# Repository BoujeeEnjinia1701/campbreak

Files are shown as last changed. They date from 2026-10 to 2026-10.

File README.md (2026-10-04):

# CampBreak

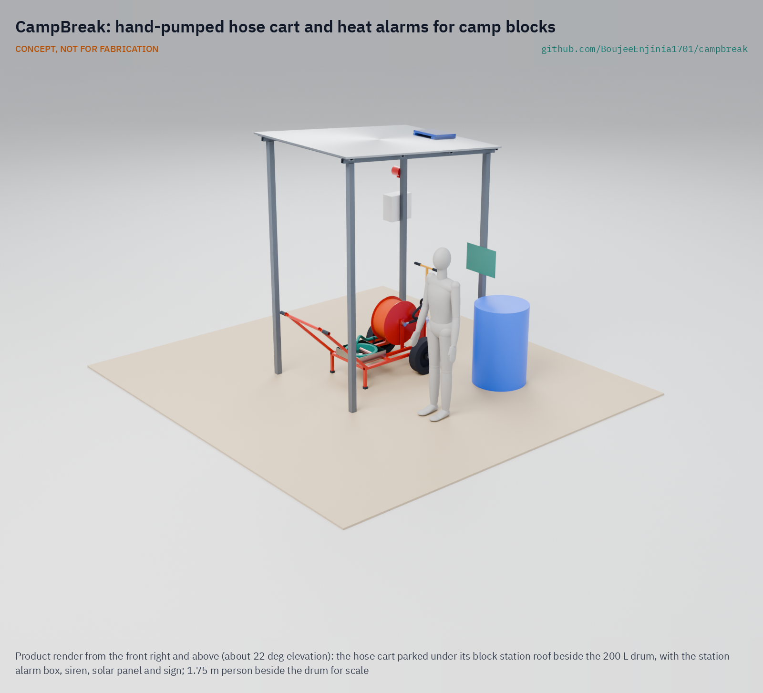
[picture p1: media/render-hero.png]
CampBreak hose cart parked in its block station beside the water drum


     

**Area:** Situational field hardware · **TRL:** 3 of 9 (proof of concept on paper; constructable design, plan not yet built) · **Value-engineering target:** USD 1,600 (estimated cost USD 1,374) · **Difficulty:** 2 of 5

Gives camp residents block alarms and a hand-pumped hose cart to fight shelter fires in the first minutes.

## Concept rationale

Most of the damage in a camp fire is decided in the first few minutes, before any fire service arrives. CampBreak gives each camp block two things for those minutes: rate-of-rise heat alarms in the shelters, so the block knows at once, and a hand-pumped hose cart at a block station, so trained residents can put water on the fire while it is still one shelter. Heat alarms are used because smoke alarms go off from cooking smoke and get switched off.

Keeping the kit open and hand-powered matters because the camps that burn most have little money, patchy power and water that runs short in the dry season. The cart needs no fuel and no mains, and a camp workshop can build and repair it. The alarms make no certification claims; they are an open engineering reference that agencies and camp committees can test and adapt.

## Burning platform

The Rohingya camps in Cox's Bazar, Bangladesh, recorded more than 222 fires between January 2021 and December 2022, 60 of them arson ([Wikipedia, citing BBC, 2023](https://en.wikipedia.org/wiki/2023_Kutupalong_refugee_camp_fire)). A single fire in March 2023 destroyed about 2,000 shelters, 2 health centres and 25 learning centres ([NRC, 2023](https://www.nrc.no/news/2023/march/todays-fire-in-coxs-bazar-must-lead-to-better-living-conditions-in-makeshift-camps)). In January 2024 another fire destroyed about 800 shelters in Camp 5; responders reported that hilly ground kept vehicles out, wind drove the fire through thatch roofs, and dry-season hydrants ran dry ([The New Humanitarian, 2024](https://www.thenewhumanitarian.org/news-feature/2024/01/10/fire-bangladesh-rohingya-refugee-camp-where-is-support)).

The pattern is the same in other dense settlements. In Dhaka, fire services took an average of 68 minutes to reach informal settlements against 28 minutes for formal areas, and residents act as first responders with poor equipment ([Engineering X, Royal Academy of Engineering](https://engineeringx.raeng.org.uk/media/03cd1j4l/engx-a-comparative-study-of-fire-risk-emergence-in-informal-settlements-in-dhaka-and-cape-town-short.pdf)). UNHCR planning standards call for 30 m firebreaks every 300 m and at least 2 m between structures ([UNHCR](https://emergency.unhcr.org/emergency-assistance/shelter-camp-and-settlement/camps/site-planning-camps)), but crowded camps rarely achieve this, so fast local response is often the only barrier left.

## Where it could be used

### By industry

| Industry | Use |
| --- | --- |
| Humanitarian shelter and camp management | Block-level alarm and first-response kit in refugee and displacement camps |
| Urban informal settlements | Community fire stations for dense shack and slum neighbourhoods |
| Disaster risk reduction NGOs | Training and equipment package for community fire volunteer programmes |
| Seasonal and labour camps | Worker camps at construction sites, brick kilns and plantations |
| Rural villages with thatch roofs | Shared hose cart for villages far from a fire station |

### By country or region

| Country or region | Why it matters there |
| --- | --- |
| Bangladesh (Cox's Bazar camps) | More than 222 fires in two years, 60 of them arson, and a 2023 fire that destroyed over 2,000 shelters ([Wikipedia, citing BBC, 2023](https://en.wikipedia.org/wiki/2023_Kutupalong_refugee_camp_fire)). |
| Bangladesh (Dhaka informal settlements) | Fire services averaged 68 minutes to reach informal settlements, against 28 minutes elsewhere ([Engineering X](https://engineeringx.raeng.org.uk/media/03cd1j4l/engx-a-comparative-study-of-fire-risk-emergence-in-informal-settlements-in-dhaka-and-cape-town-short.pdf)). |
| South Africa | Shack fires occur every day, killing and injuring hundreds of people each year ([UNDRR, 2024](https://www.undrr.org/resource/learning-those-who-are-most-risk-informal-settlement-fires-south-africa)). |
| Northwest Syria | A local coordination group counted 126 fires in displacement camps in the first eight months of 2022, with most families cooking inside tents ([Al-Monitor, 2022](https://www.al-monitor.com/originals/2022/08/fires-engulf-displacement-camps-northern-syria-during-heat-wave)). |
| Greece and Europe | The 2020 fires at Moria on Lesbos left about 11,500 asylum seekers without shelter ([UN News, 2020](https://news.un.org/en/story/2020/09/1072132)). |

## What sparked the idea

The idea came from the fire in Camp 11 at Kutupalong, Cox's Bazar, on 5 March 2023. It destroyed more than 2,000 shelters, 35 mosques and 21 learning centres and left about 12,000 people without shelter, although it was brought under control in about three hours ([Wikipedia, citing BBC and The Guardian, 2023](https://en.wikipedia.org/wiki/2023_Kutupalong_refugee_camp_fire)). Three hours is fast for a fire service in a hilly, crowded camp, but far too slow for bamboo and tarpaulin. The damage was done in the first minutes, when the only people present were residents with buckets.

## Problem

Fires in dense camps of bamboo and tarpaulin shelters spread from shelter to shelter within minutes, and fire engines often cannot reach them in time. Residents are the first responders, but they usually have only buckets.

Full problem statement: [docs/01-problem.md](docs/01-problem.md)

## Concept

A camp-block kit of rate-of-rise heat alarms and a hand-pumped hose cart; when an alarm sounds, residents wheel the cart from its block station to the burning shelter and pump water from a drum or tap through the hose to knock the fire down in the first minutes.

Full design precis: [docs/02-concept.md](docs/02-concept.md) · Requirements: [docs/03-requirements.md](docs/03-requirements.md) · Calculations: [docs/04-calcs/01-sizing.md](docs/04-calcs/01-sizing.md) · Prototype build plan: [docs/05-build-plan.md](docs/05-build-plan.md) · Design decisions: [docs/06-design-decisions.md](docs/06-design-decisions.md) · 3D viewer: [media/viewer.html](media/viewer.html)

## Key components

- Rate-of-rise heat alarm, one per shelter, hung under a roof pole
- Block station: four-post shade roof, station alarm box with siren and solar panel, sign and 200 L drum
- Two-wheeled hose cart: welded steel frame, 400 mm puncture-proof wheels
- Semi-rotary hand pump with a two-person T-bar lever and a 4 bar relief valve
- 30 m of 19 mm hose on a reel, stowed full of water behind the shut nozzle, with a jet and spray nozzle
- 4 m suction hose with foot valve strainer, quick couplings and a tap adaptor

Key figures at TRL 3 (estimates): about 20 L/min at the nozzle with two people pumping, a jet reach of about 6.9 m, an alarm relay of 7.2 s, and a 103 kg cart (delivery hose stowed full) that two people pull up a 10 % slope at about 101 N each, 1 N over the 100 N assumed sustainable. A check foot valve keeps the pump primed, the suction hose stays coupled, and volunteers go when two arrive. Water on target within 3 minutes is met on paper for a shelter 100 m away (2.95 min, 3 s to spare), because the delivery hose is stowed full; stations are still sited within 70 m of every shelter (2.5 min).

## Building the prototype

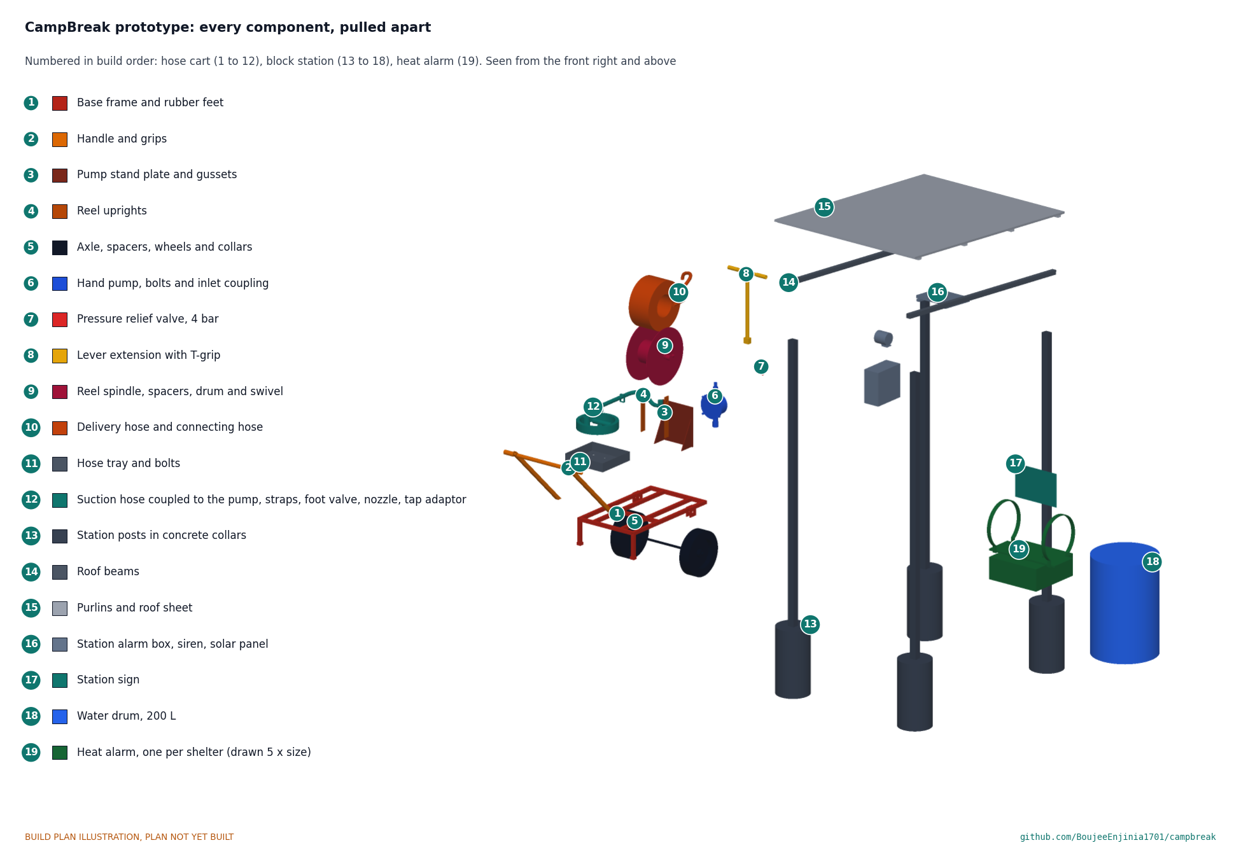
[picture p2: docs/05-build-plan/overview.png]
Every component of the prototype, pulled apart and numbered in build order


The [prototype build plan](docs/05-build-plan.md) shows how to build one block kit, component by component, with a making sketch for every made part, close-ups of the joints and a picture for each of the 21 assembly steps. The cart and station are mild steel tube and plate, cut, drilled and MIG welded, with bought wheels, pump, reel and hoses; the alarm is a drilled stock box on a small aluminium plate. The plan is a plan: nothing has been built or tested yet, and building to it is TRL 4 work. Safety stops before welding, first pumping, loading and wiring are listed in its section 6.

## Safety

> Published as an open engineering reference, not as certified fire alarms or firefighting equipment.
>
> The kit is for small, early fires only. People leave first; nobody enters a burning shelter or stays when the fire spreads.
>
> Never use water on burning cooking oil or on live electrical wiring.
>
> Pressurised hose and pump can injure. The relief valve opens at 4 bar with its discharge pointing down; check hose, clips and fittings before every drill and never point the jet at people.
>
> Heat alarms use alkaline AA cells and the station a sealed lead-acid battery; there are no lithium cells in the kit. Follow the camp's disposal rules.
>
> This design is published as an open engineering reference at TRL 3: a concept, not for fabrication until it is built and tested at TRL 4. It is not certified equipment.

## Repository layout

| Folder | Contents |
| --- | --- |
| `docs/` | Problem, concept, requirements, calculations and design decisions |
| `cad/src/` | build123d Python source, the source of truth for all geometry |
| `cad/step/`, `cad/stl/` | Exported models for FreeCAD, other CAD tools and printing |
| `cad/drawings/` | 2D sketches and dimensioned drawings |
| `bom/` | Bill of materials |
| `electronics/` | KiCad schematics and PCB layouts |
| `firmware/` | Microcontroller code |
| `media/` | Renders, perspectives and photos |
| `build-log/` | Dated prototyping notes |

## Documentation

Controlled documents follow the portfolio [documentation standard](.kit/STANDARDS.md). Each carries a document ID (CBK-PRC-001 for the precis), a version and a revision history. Branded PDFs are built with `python .kit/render.py` and attached to GitHub Releases when a document is tagged, for example `CBK-PRC-001/v1.0`.

## Credits

Designed by Amish Chadha at Design Molecule Labs. See [CONTRIBUTORS.md](CONTRIBUTORS.md) for roles. To cite this design, use [CITATION.cff](CITATION.cff) (GitHub shows it as "Cite this repository").

AI assistance (Claude) was used to accelerate prototype documentation and first-pass research. Design direction and all decisions are Amish Chadha's, recorded in this repository's decision records (`docs/decisions/`).

## Licenses

- **Hardware** (CAD, drawings, BOM, electronics): [CERN-OHL-S v2](LICENSE)
- **Software** (firmware, scripts, notebooks): [MIT](LICENSE-SOFTWARE)

A project of [Design Molecule Labs](https://designmolecule.com).

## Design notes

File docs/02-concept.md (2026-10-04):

---
doc_id: CBK-PRC-001
title: CampBreak design precis
project: CampBreak
doc_type: Precis
version: "0.5"
status: Draft
date: '2026-10-03'
author: Amish Chadha
license: CERN-OHL-S-2.0
revisions:
- version: "0.1"
  date: '2026-09-30'
  author: Amish Chadha
  change: Initial scaffold
- version: "0.2"
  date: '2026-10-03'
  author: Amish Chadha
  change: "Populated to TRL 2 with concept media, components and first-order numbers"
- version: "0.3"
  date: '2026-10-03'
  author: Amish Chadha
  change: "TRL 3 with the decisions of CBK-DDR-001 and CBK-DDR-002 applied and results from CBK-CAL-001"
- version: "0.4"
  date: '2026-10-03'
  author: Amish Chadha
  change: "Amish's R9 decision 1A (CBK-DDR-003): check foot valve, suction hose left coupled, go when two arrive; figures updated"
- version: "0.5"
  date: '2026-10-03'
  author: Amish Chadha
  change: "Amish's round-2 decision 1A (CBK-DDR-004): delivery hose stowed full; cart mass, pull and R9 figures updated"
---

# CampBreak design precis

Gives camp residents block alarms and a hand-pumped hose cart to fight shelter fires in the first minutes.

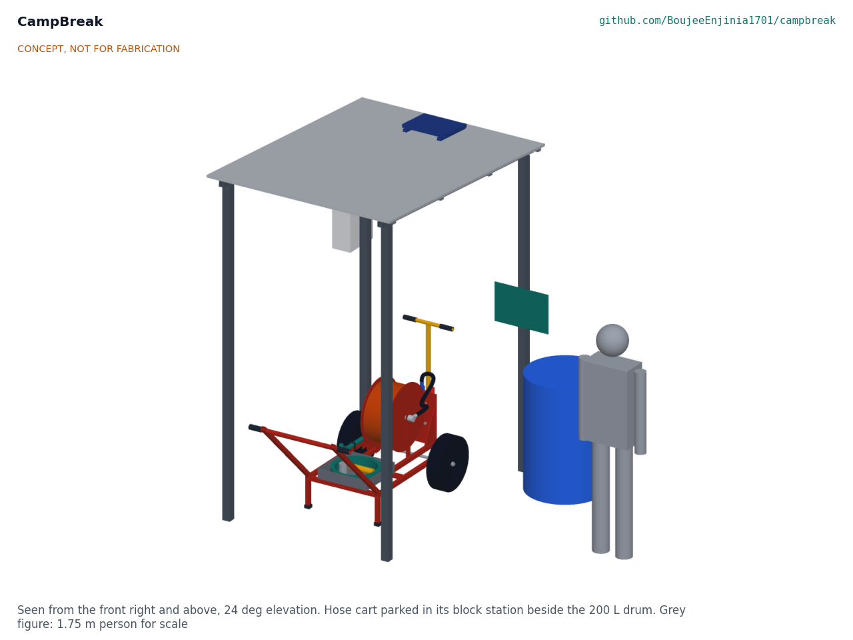
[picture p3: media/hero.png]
Figure 1. Hose cart parked in its block station beside the water drum, with a 1.75 m person for scale


*Figure 1. Concept render of the block station and hose cart, from the TRL 3 model.*

## How it works

Each shelter in a block gets a battery heat alarm hung under a roof pole. When the air at the alarm warms by 8 °C per minute or more, or passes 57 °C, the alarm sounds and radios the block station. The station sounds a 110 dB(A) siren and broadcasts once, so every alarm in the block sounds within about 7 s. Volunteers run to the station, pull out the two-wheeled hose cart and take it to the burning shelter. There they drop the suction hose into a water drum, jerrycan or open container (or connect the tap adaptor to a standpipe), run out the hose from its reel, and two people pump the T-bar lever to drive about 20 L/min through a 6 mm jet that reaches about 7 m. The aim is to keep a fire to one shelter while others clear the neighbours and call the fire service.

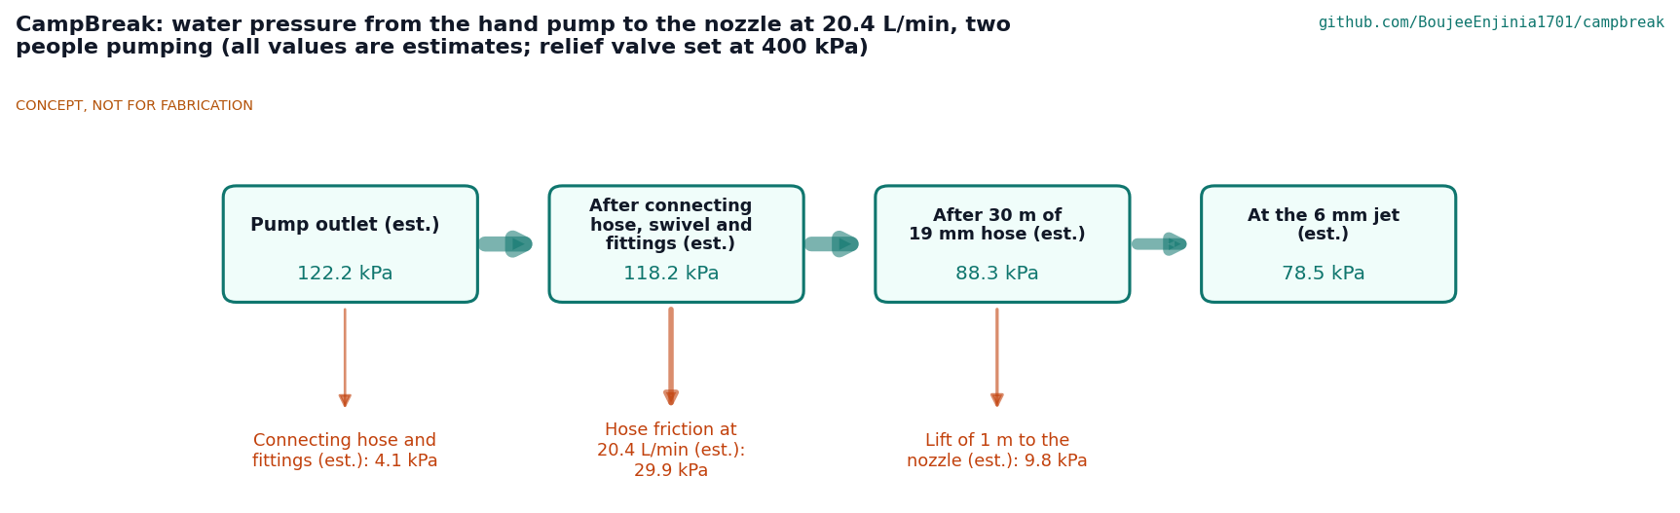
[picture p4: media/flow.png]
Figure 2. Water pressure from the pump to the nozzle (estimates)


*Figure 2. Pressure along the water line at 20.4 L/min with two people pumping; all values are estimates from CBK-CAL-001.*

## Components

*Table 1. Main components (numbers match bom/bom.csv).*

| BOM | Component | What it is |
| --- | --- | --- |
| 1 | Heat alarm (24 per block) | Stock ABS box 100 x 100 x 40 mm with a controller and sub-GHz radio board, a thermistor below the box in a printed guard, a 95 dB(A) piezo and three AA alkaline cells; hung under a roof pole on an aluminium plate and two cable ties |
| 2 | Station alarm box, siren and solar panel | Locked IP65 box with the receiver board, charge controller and 12 V 7 Ah sealed lead-acid battery; 110 dB(A) siren; 10 W panel on the roof |
| 3 | Station frame and roof | Four 60 mm square posts in concrete collars, two beams, four purlins, corrugated sheet; about 1.5 x 2.05 m of shade |
| 4, 5 | Sign and water drum | Instructions in the camp languages; a 200 L drum beside the cart |
| 6 | Cart frame | Welded 30 mm square tube frame with pull handle, pump stand, reel uprights and axle plates |
| 7 | Wheels | Two 400 mm puncture-proof wheels on a 20 mm through axle |
| 8, 9 | Hand pump and lever | Cast-iron double-acting semi-rotary pump, 25 mm ports, with a T-bar lever for two people |
| 10, 11 | Reel and hose | 30 m of 19 mm semi-rigid hose on a reel with a swivel inlet, fed from the pump by a short connecting hose |
| 12 to 15, 20 | Nozzle, suction hose, couplings, tap adaptor, hose straps | Jet and spray nozzle with shut-off; 4 m of 25 mm suction hose with a brass check foot valve, left coupled to the pump inlet and strapped along the left rail so the pump stays primed; cam-lever couplings; a push-on tap adaptor |
| 16 | Hose tray | Folded galvanised tray on the cart that carries the suction hose and small parts |
| 19 | Relief valve | 4 bar spring relief valve at the pump outlet |

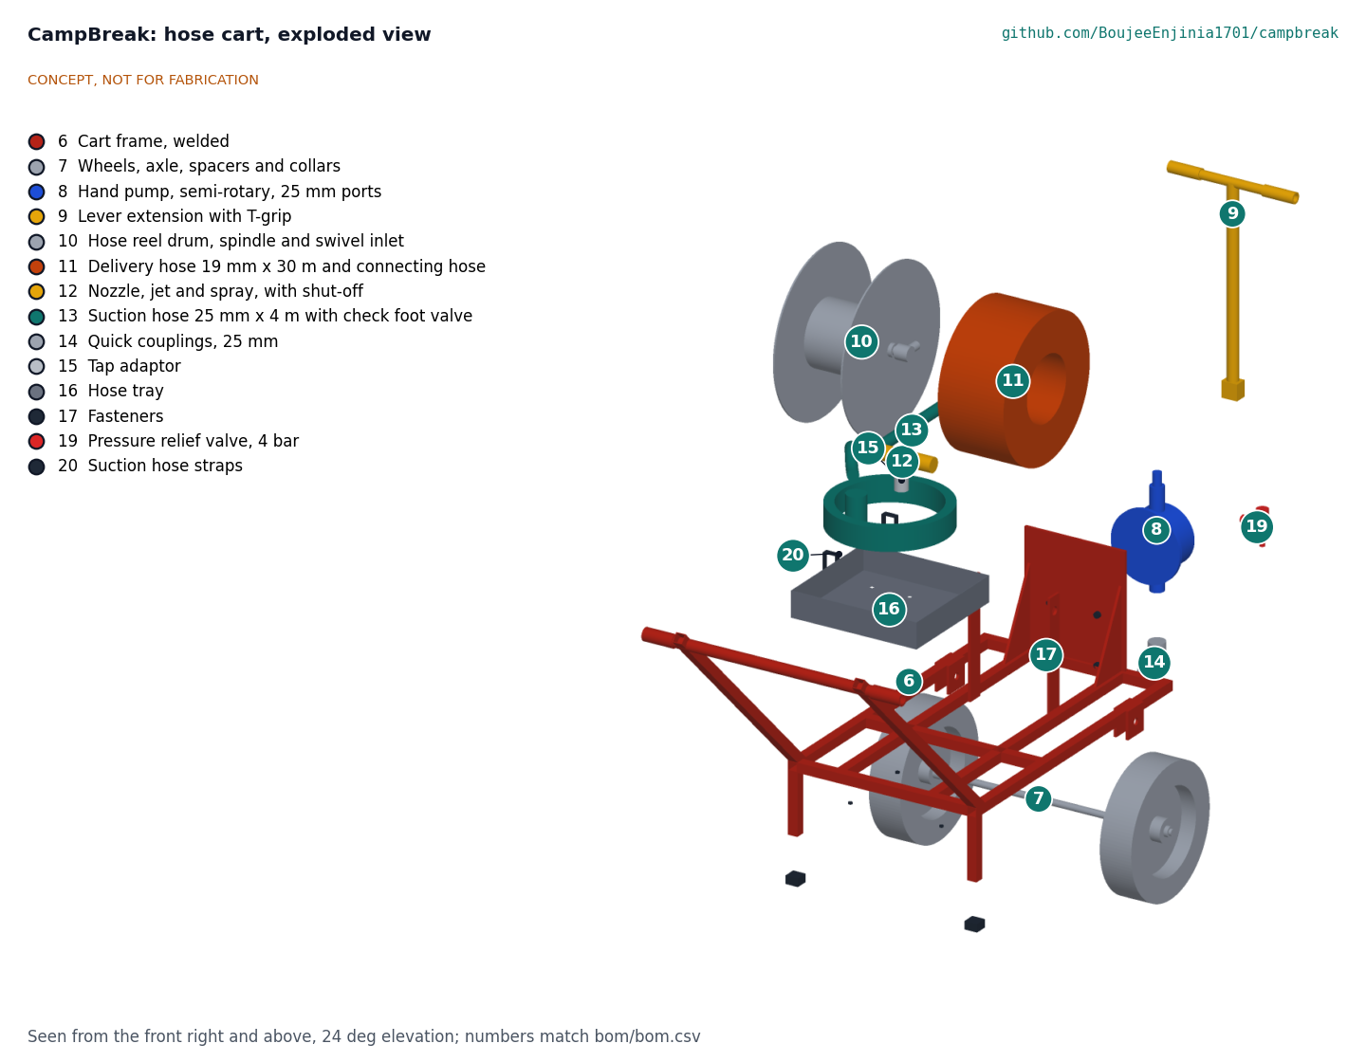
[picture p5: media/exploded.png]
Figure 3. Hose cart pulled apart, numbers matching the BOM


*Figure 3. Exploded view of the hose cart; callouts match bom/bom.csv.*

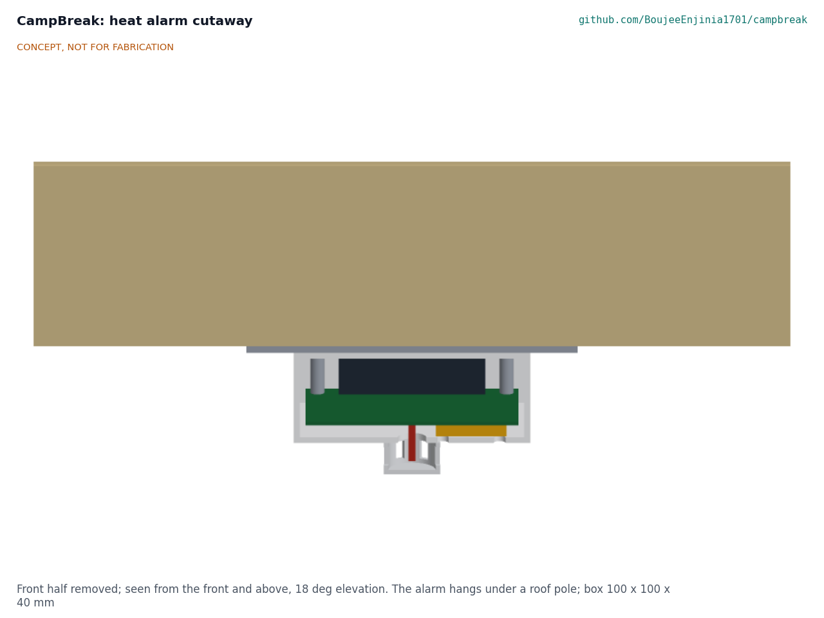
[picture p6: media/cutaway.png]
Figure 4. Heat alarm cut open


*Figure 4. The heat alarm cut open: battery holder, board, sounder and the thermistor below the box.*

## Key design choices

All decided under Amish's 2026-10-03 pre-approval (CBK-DDR-001 and CBK-DDR-002):

1. **Heat, not smoke.** Rate of rise of 8 °C per minute with a 57 °C fixed back-up, because shelters cook with open flames.
2. **Star relay, published in full.** Alarms report to the station, which broadcasts once; no mesh.
3. **A bought pump.** A semi-rotary wing pump is sold in most target markets and is repaired with hand tools.
4. **No lithium cells.** Alkaline cells in the alarms and a sealed lead-acid battery at the station.
5. **Relief valve at 4 bar** so a shut nozzle cannot over-pressure the hose or fittings.
6. **A cart two people can pull,** 850 mm wide, about 103 kg loaded and primed, with the delivery hose full, on 400 mm puncture-proof wheels.
7. **Stations sited within 70 m of every shelter** as the siting margin for the 3 minute target.

Decided by Amish on 2026-10-03 ("1A 2A 3A 4A 5A 6A 7A 8A 9A 10A 11A"; CBK-DDR-003):

8. **A primed pump and a coupled suction hose.** A check foot valve keeps the pump and suction hose full, and the hose stays coupled to the pump, so nothing is coupled or primed at the fire.
9. **Go when two arrive.** The first two volunteers at the station take the cart, within 30 s of the siren; the rule is drilled and printed on the drill card.

## First-order numbers

*Table 2. Key figures (CBK-CAL-001; estimates unless stated).*

| Quantity | Value | Main assumption |
| --- | --- | --- |
| Flow at the nozzle | 20.4 L/min | 0.40 L per double stroke at 60 per minute, 85 % volumetric efficiency |
| Jet reach | 6.9 m | Half the drag-free range of a 12.5 m/s jet at 30° |
| Effort per person | 47 W, about 28 N at the grip | 50 % mechanical efficiency |
| Pump outlet pressure | 1.2 bar | 30 m of 19 mm hose, nozzle 1 m above the pump |
| One 200 L drum | about 10 min | |
| Alarm sound at 3 m | 85.5 dB(A) | 95 dB(A) at 1 m |
| Alarm relay, worst case | 7.2 s | Three retries, station broadcast heard within 4 s |
| Alarm battery life | Cell shelf life (about 5 years) | 6.9 µA average |
| Cart mass, loaded and primed | 103 kg | Catalogue masses for bought parts; 2.6 kg of water in the pump and suction hose and 8.9 kg in the delivery hose |
| Pull on a 10 % slope | 101 N per person | Rolling resistance 0.10; 1 N over the 100 N assumed sustainable |
| Water on target | 2.95 min at 100 m; 2.5 min at 70 m | 1.0 m/s walking, 30 s gather, delivery hose stowed full |
| Block kit cost | USD 1,374 | bom/bom.csv |

Value-engineering target: USD 1,600. Estimated cost of the constructable design: USD 1,374 (USD 226 under the target).

## Patent design-arounds

From the preliminary patent, trademark and prior-art screen (not legal advice):

- Rate-of-rise heat sensing, as the preliminary screen advised; no alarm certification is claimed.
- Lumkani's networked heat detector has no patent identified in the preliminary screen, but its mesh network is described as patented. CampBreak uses a plain star scheme (alarm to station, station broadcast to all), published in full, and is checked again before release.

## Shared blocks

- FieldNode sensor core (power and radio lessons for the alarm and block station)
- CalRig proof-load (pressure and hose proof testing)
- BreakHook (sibling: opening firebreaks in dense settlements)

## Safety

> **Safety:** The kit is for small, early fires only. People leave first; nobody enters a burning shelter or stays when the fire spreads, and the fire service is called at once. Never use water on burning cooking oil or on live electrical wiring.

> **Safety:** The pump, hose and nozzle are pressurised. The relief valve opens at 4 bar and points its discharge at the ground; the hose is rated at 10 bar. Check the hose, clips and couplings before every drill, never point the jet at people, and shut the nozzle only while someone is still at the pump.

> **Safety:** The station battery is sealed lead-acid: fuse it at the terminal, keep it in the locked box, and recycle it through a battery dealer. The alarms use alkaline AA cells; follow the camp's disposal rules. There are no lithium cells in the kit.

> **Safety:** The loaded cart weighs about 103 kg, with the delivery hose full. Two people pull it; on slopes steeper than 10 % a third person holds it back. Park it on its feet with the handle down.

This design is published as an open engineering reference by Design Molecule Labs. It is not certified equipment.

## Open questions

None at design level. Items that can only be settled with real parts are listed in the design decisions register (`docs/06-design-decisions.md`).

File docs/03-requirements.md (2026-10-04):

---
doc_id: CBK-REQ-001
title: CampBreak requirements
project: CampBreak
doc_type: Requirements
version: "0.5"
status: Draft
date: '2026-10-03'
author: Amish Chadha
license: CERN-OHL-S-2.0
revisions:
- version: "0.1"
  date: '2026-09-30'
  author: Amish Chadha
  change: Initial scaffold
- version: "0.2"
  date: '2026-10-03'
  author: Amish Chadha
  change: "Populated to TRL 2 with concept media, components and first-order numbers"
- version: "0.3"
  date: '2026-10-03'
  author: Amish Chadha
  change: "TRL 3 with the decisions of CBK-DDR-001 and CBK-DDR-002 applied and results from CBK-CAL-001"
- version: "0.4"
  date: '2026-10-03'
  author: Amish Chadha
  change: "R9 result after Amish's decision 1A (CBK-DDR-003): check foot valve, suction hose left coupled, go-when-two-arrive rule; delivery hose fill time added. R6 and R11 results updated. Requirement wording unchanged"
- version: "0.5"
  date: '2026-10-03'
  author: Amish Chadha
  change: "Amish's round-2 decision 1A (CBK-DDR-004): delivery hose stowed full; R9 now met on paper at 100 m; R6 pull per person 101 N. Requirement wording unchanged"
---

# CampBreak requirements

Measurable requirements for one block kit, with the TRL 3 result from the calculation note CBK-CAL-001. Ten are met on paper or by design and R2 can only be shown in a cooking trial at TRL 4. **R9 is now met on paper** for a shelter 100 m from the station, with 3 s to spare.

*Table 1. Requirements and TRL 3 status.*

| ID | Requirement | Target | Verification (TRL 4 or later) | TRL 3 result | Status |
| --- | --- | --- | --- | --- | --- |
| R1 | Alarm detects a fast temperature rise | Alarms at a rise of 8 °C (14 °F) per minute or faster, plus a 57 °C fixed threshold | Heat chamber test with logged temperature ramp | Threshold set in firmware, averaged over 60 s | Met by design |
| R2 | Alarm ignores normal cooking | No alarm during 1 hour of stove cooking at 1 m distance | Cooking trial in a mock shelter | Not calculable on paper | To show at TRL 4 |
| R3 | Alarm is loud enough to wake the block | At least 85 dB(A) at 3 m | Sound level meter test | 85.5 dB(A) | Met (est.) |
| R4 | Alarm reaches neighbours and the block station | Every alarm in the block and the station within 10 s | Field test across a mock block layout | 7.2 s worst case | Met (est.) |
| R5 | Alarm runs without mains power | At least 12 months on batteries | Current draw measurement | Limited by cell shelf life, about 5 years | Met (est.) |
| R6 | Cart can be moved on camp paths | Two adults move the loaded cart 100 m on an unpaved 10 % slope in 3 minutes or less; cart width 0.9 m or less | Timed trial on a test track | 1.7 min; 101 N per person (1 N over the 100 N assumed sustainable); 850 mm wide | Met (est.) |
| R7 | Hand pump delivers useful flow | At least 20 L/min (5.3 US gal/min) at the nozzle, pumped by two people for 10 minutes | Bench flow test with timed volume | 20.4 L/min at 47 W per person | Met (est.) |
| R8 | Jet reaches a burning shelter from a safe distance | Jet reach of 6 m (20 ft) or more | Measured throw test | 6.9 m | Met (est.) |
| R9 | Fast deployment | Water on target within 3 minutes of alarm for a shelter 100 m from the station | Timed drill with volunteers, from the siren, using the go-when-two-arrive rule | 2.95 min (177 s) at 100 m; 2.5 min at 70 m | Met (est.), 3 s to spare at 100 m |
| R10 | Repairable locally | All wear parts replaceable with hand tools and parts sold in local markets | Maintenance walkthrough with a camp workshop | Every wear part is a market item | Met by design |
| R11 | Cost against the value-engineering target | Value-engineering target: USD 1,600 for one block kit | Costed bill of materials | USD 1,374, USD 226 under the target | Met |

R9 stays at 3 minutes and 100 m. On 2026-10-03 Amish chose option A on R9 ("1A 2A 3A 4A 5A 6A 7A 8A 9A 10A 11A"; CBK-DDR-003): a check foot valve so the pump stays primed, the suction hose left coupled to the pump with a cam-lever coupling, and the drilled rule "go when two arrive" with a 30 s gather. That brought the 100 m time from 3.8 min to 3.2 min. The rest of the gap was the 26 s needed to fill the empty 30 m delivery hose. In round 2 Amish agreed to stow that hose full of water (CBK-DDR-004): "i agree with all the 46 recommendations you provided. please proceed." The 100 m time is now 2.95 min. This is met on paper by only 3 s, on estimated inputs, and the delivery hose adds 8.9 kg to the cart: the pull is about 101 N per person on a 10 % slope, just over the 100 N assumed sustainable. The R6 time of 1.7 min is still met. The siting rule of CBK-DDR-001 (D9), no shelter more than 70 m along the path from a station, is kept as the siting margin; there the time is 2.5 min.

## Assumptions

- A block has a drum or tap within reach of most shelters, or drums are placed at stations.
- Camp management allows alarms in shelters and a station in each block.
- Volunteers are trained and drill regularly, so the first two reach the station within 30 s of the siren.
- The foot valve's check holds the pump and suction hose full between uses, and the nozzle shut-off holds the delivery hose full; the weekly check on the drill card confirms both.
- The estimates marked (est.) in CBK-CAL-001 hold within the margins shown; the pump displacement is the most important one.

## Safety

> **Safety:** These requirements describe a pressurised hand-pumped water system and battery-powered alarms. The kit is for small, early fires only, people leave first, and water is never used on burning oil or live wiring. It is an open engineering reference, not certified equipment.

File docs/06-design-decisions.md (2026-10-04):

---
doc_id: CBK-DEC-001
title: CampBreak design decisions register
project: CampBreak
doc_type: Design decisions register
version: "0.3"
status: Draft
date: '2026-10-03'
author: Amish Chadha
license: CERN-OHL-S-2.0
revisions:
- version: "0.1"
  date: '2026-10-03'
  author: Amish Chadha
  change: Register opened at TRL 3; all decisions made under Amish's 2026-10-03 pre-approval
- version: "0.2"
  date: '2026-10-03'
  author: Amish Chadha
  change: "Amish's R9 decision 1A recorded (CBK-DDR-003); one new open decision: stow the delivery hose full"
- version: "0.3"
  date: '2026-10-03'
  author: Amish Chadha
  change: "Open decision 1 decided (round 2, 1A) and recorded as CBK-DDR-004; no open decisions; weekly hose check added to items to confirm"
---

# CampBreak design decisions register

Every design decision still to be made, and every decision made, in one place. Each decision is argued in full in its decision record under `docs/decisions/`; this register is the index Amish works from. The build plan (`docs/05-build-plan.md`) describes the design as it stands and does not list decisions.

## Open decisions

None. Open decision 1 (stow the delivery hose full) was decided by Amish on 2026-10-03; see Decisions made and CBK-DDR-004.

## To confirm when parts are bought

| # | What to confirm | Why it matters | Source |
| --- | --- | --- | --- |
| 1 | The hand pump displaces at least 0.40 L per double stroke | R7 is met with only 2 % margin on flow; a smaller pump misses it | CBK-CAL-001, section A |
| 2 | The pump's flange hole pattern (150 mm square assumed), shaft height and handle socket | They set the stand plate holes and the lever hub bore | CBK-DDR-002, P5 and P6 |
| 3 | The reel drum's bore suits a 25 mm spindle, and the swivel inlet's thread suits the 19 mm hose tail | Sets the spindle size or a sleeve | CBK-DDR-002, P7 |
| 4 | The delivery hose's outside diameter is 28 mm or less | The 30 m hose fills the drum with only 8 % spare room | CBK-CAL-001, section G |
| 5 | The nozzle's jet orifice is 6 mm | Sets the flow, pressure and reach together | CBK-CAL-001, section A |
| 6 | The piezo sounder gives at least 95 dB(A) at 1 m | R3 is met with 0.5 dB margin | CBK-CAL-001, section B |
| 7 | The wheels have 20 mm bores and 75 mm hubs | Sets the axle, spacer and collar lengths | CBK-DDR-002, P2 |
| 8 | The relief valve opens at 4 bar ± 0.5 bar | Pressure limit for the hose and fittings | CBK-DDR-001, D7 |
| 9 | The foot valve's check holds the suction hose and pump full for a week, and the suction hose bends to 60 mm radius or less | The pump stays primed (R9); the stowed hose path has a 63 mm bend | CBK-DDR-003 |
| 10 | The nozzle shut-off and the pump hold the full delivery hose for a week with no drip; the pull per person on a 10 % slope (about 101 N expected) is acceptable | R9 has only 3 s of margin and relies on the hose staying full; the pull is 1 N over the 100 N assumed sustainable | CBK-DDR-004 |

## Value engineering

Value-engineering target: USD 1,600 (a hypothetical control target, not a limit). Estimated cost of the constructable design: USD 1,374 (USD 226 under the target). Main cost drivers and savings worth trying:

- The 24 heat alarms are the largest share (USD 420, USD 17.50 each). The board price is a prototype module estimate; a single board with the radio, controller and sounder driver, made in a batch, should fall to about USD 10 to 12 each at TRL 4.
- The station costs USD 317: steel frame and roof USD 157, alarm box with battery, siren and panel USD 105. Where a block already has a shaded structure, the station can be built against it and the frame dropped.
- The cart costs USD 637: pump USD 120, reel drum USD 95, hoses USD 83, wheels USD 69, frame USD 59, suction hose with the brass check foot valve USD 40. A reel welded from tube and sheet in the camp workshop could save about USD 50; a second-hand pump is worth trying if its displacement is checked.

## Decisions made

| Date | Decision | Decided by | Record |
| --- | --- | --- | --- |
| 2026-10-03 | Alarm relay: published star scheme on a sub-GHz band (alarm to station, one station broadcast to all alarms); no mesh; checked against Lumkani's patents before release | Amish, pre-approval: "I pre-approve the batch runs along with any recommendations you come up with." | CBK-DDR-001, D1 |
| 2026-10-03 | Detection: rate of rise of 8 °C per minute over 60 s plus a 57 °C fixed back-up, thermistor below the box | Amish, same pre-approval | CBK-DDR-001, D2 |
| 2026-10-03 | Alarm board specified by function and priced as a module; board design and firmware left to TRL 4 | Amish, same pre-approval | CBK-DDR-001, D3 |
| 2026-10-03 | Block kit of 24 alarms, one station and one cart | Amish, same pre-approval | CBK-DDR-001, D4 |
| 2026-10-03 | Bought cast-iron semi-rotary pump, 25 mm ports, at least 0.40 L per double stroke | Amish, same pre-approval | CBK-DDR-001, D5 |
| 2026-10-03 | No lithium cells: sealed lead-acid at the station, alkaline AA cells in the alarms (conservative; lithium iron phosphate only with evidence of safe charging at 45 °C and a recycling route) | Amish, same pre-approval | CBK-DDR-001, D6 |
| 2026-10-03 | 4 bar relief valve at the pump outlet, discharge down, hose rated 10 bar (conservative; raised only after a burst test of the bought hose and fittings) | Amish, same pre-approval | CBK-DDR-001, D7 |
| 2026-10-03 | 19 mm semi-rigid hose, 30 m on a reel, with a 6 mm jet and spray nozzle | Amish, same pre-approval | CBK-DDR-001, D8 |
| 2026-10-03 | R9 kept at 3 min; stations sited within 70 m of every shelter with a drilled 30 s muster; R9 reported as not met on paper at 100 m | Amish, same pre-approval | CBK-DDR-001, D9 |
| 2026-10-03 | First partner to approach: a camp management agency in the Cox's Bazar camps, Bangladesh, with the Bangladesh Fire Service and Civil Defence (first candidate, not agreed) | Amish, same pre-approval | CBK-DDR-001, D10 |
| 2026-10-03 | Design for construction: welded tube frame, through axle in axle plates, legs and feet, handle, pump stand, lever extension, reel on uprights, connecting hose and relief tee, four-post station, fixings for the station fittings, hose tray and the alarm's plate and ties (P1 to P12) | Amish, same pre-approval | CBK-DDR-002 |
| 2026-10-03 | `budget_usd` left at USD 1,600 as the value-engineering target; cost variations accepted | Amish: "I also accept any cost overruns or variations from the assumed scope cost." | CBK-DDR-001 |
| 2026-10-03 | R9 (decision 1A): brass check foot valve so the pump stays primed; suction hose left coupled to the pump inlet with a cam-lever coupling and strapped along the left rail; drilled rule "go when two arrive" with a 30 s gather on the drill card, the station sign and in the build plan; 3 min target and "stations within 70 m of every shelter" kept as the siting margin. Result: 3.2 min at 100 m (not met, 11 s over), 2.7 min at 70 m | Amish: "1A 2A 3A 4A 5A 6A 7A 8A 9A 10A 11A" | CBK-DDR-003 |
| 2026-10-03 | R9 (round 2, decision 1A): delivery hose and connecting hose stowed full of water behind the shut nozzle, refilled at the weekly check; no new parts. Result: 2.95 min (177 s) at 100 m, met with 3 s to spare; 2.5 min at 70 m; cart 103.4 kg; 101 N per person on a 10 % slope (1 N over the 100 N assumed sustainable); cost unchanged at USD 1,374 | Amish: "i agree with all the 46 recommendations you provided. please proceed." | CBK-DDR-004 |

## Safety

> **Safety:** CampBreak includes a pressurised hand-pumped water line (relief valve at 4 bar, hose rated 10 bar) and a sealed lead-acid station battery. The kit is for small, early fires only; people leave first, and water is never used on burning oil or live wiring. Safety stops are listed in the build plan, section 6. It is an open engineering reference, not certified equipment.

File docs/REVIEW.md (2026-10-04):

# Review note: CampBreak

## Session 2026-09-30: scaffolded

### What was done

- Repository created from kit 1.6.0 at TRL 1, target TRL 2.
- `docs/01-problem.md` (CBK-PRB-001 v0.1): problem with cited evidence, users, environment, constraints, prior work, open questions.
- `docs/02-concept.md` (CBK-PRC-001 v0.1): how it works, components, patent design-arounds, shared blocks, safety.
- `docs/03-requirements.md` (CBK-REQ-001 v0.1): 11 proposed requirements.
- `README.md` with concept rationale, burning platform, where it could be used, and what sparked the idea.

### Next

- Run `/populate` to bring the repo to a strong TRL 2 with concept media.

## Session 2026-10-03: TRL 2 (populate)

Run under `/to-trl3` with Amish's 2026-10-03 pre-approval: "start with the first 14 repos from the list of 29 projects. I pre-approve the batch runs along with any recommendations you come up with. I also accept any cost overruns or variations from the assumed scope cost."

### What was done

- Kit 1.7.0 installed (`.kit/`, `.claude/commands/`, root `CLAUDE.md` from `.kit/CLAUDE.md`).
- `docs/01-problem.md` (CBK-PRB-001 v0.3): budget worded as a value-engineering target; open questions answered; safety section.
- `docs/02-concept.md` (CBK-PRC-001 v0.3): how it works, components by BOM line, key design choices, first-order numbers, safety.
- `docs/03-requirements.md` (CBK-REQ-001 v0.3): 11 measurable requirements with TRL 3 status.
- Concept media from `cad/src/concept_media.py`: `media/hero.png` (with a 1.75 m figure), `media/concept-blueprint.png` and `.pdf` (CBK-DWG-010), `media/model.glb` and `media/viewer.html`, `media/cutaway.png` (heat alarm), `media/exploded.png` (cart, BOM callouts), `media/flow.png` (pressure along the water line, estimates).
- `bom/bom.csv`: 19 lines, every line priced.

### Results

The concept closes on paper except for response time at 100 m (R9) and the cooking test (R2), which cannot be calculated.

### Decisions made under the pre-approval

TRL 2 review items D1 to D10 (relay scheme, detection rule, board scope, kit size, pump, no lithium, relief valve, hose, R9 siting rule, first partner), recorded in `docs/decisions/0001-trl2-review-decisions.md` (CBK-DDR-001).

## Session 2026-10-03: TRL 3 (advance and build plan)

### What was done

- `cad/src/model.py`: parametric build123d model of the cart, station and heat alarm, made constructable, with 97 constructability checks (all pass). STEP and STL in `cad/step/` and `cad/stl/`.
- `docs/04-calcs/01-sizing.md` (CBK-CAL-001 v0.1) and `docs/04-calcs/sizing.py` with `results.csv`.
- `cad/drawings/CBK-DWG-001` Rev P1: general arrangement of the hose cart (`cad/src/sheets.py`).
- Build plan `docs/05-build-plan.md` (CBK-BLD-001 v0.1) with pictures from `cad/src/build_plan_media.py`: overview, 12 making sketches (CBK-DWG-101 to 112), 11 joint close-ups and 21 assembly steps.
- Design decisions register `docs/06-design-decisions.md` (CBK-DEC-001 v0.1) and decision record `docs/decisions/0002-design-for-construction.md` (CBK-DDR-002).
- Appearance model `cad/src/product_model.py` (hero, exploded and detail views; mannequin and forearm for scale). Scenes exported to `/home/claude/renders/campbreak` for the photoreal render on Amish's Mac. `media/render-hero.png` does not exist yet; the README already leads with it.
- `project.yaml`: trl 3, trl_target 3, `design_state: constructable`, evidence listed. `budget_usd` unchanged at 1,600.

### Results

- Flow 20.4 L/min at 47 W per person; jet reach 6.9 m; pump outlet 1.2 bar.
- Alarm 85.5 dB(A) at 3 m; relay 7.2 s worst case; battery life limited by cell shelf life.
- Cart 850 mm wide, about 91 kg loaded; 89 N per person on a 10 % slope; 1.7 min for 100 m.
- Station roof resists a 30 m/s gust uplift with a factor of about 2 on collar weight.
- Value-engineering target: USD 1,600. Estimated cost of the constructable design: USD 1,355 (USD 245 under the target).

### Requirements not met

- **R9 (water on target within 3 min at 100 m): not met on paper**, 3.8 min. With the decided siting rule (no shelter more than 70 m from a station, 30 s muster) the time is 2.8 min.
- R2 (no false alarm while cooking) cannot be shown on paper; it needs a cooking trial at TRL 4.
- Thin margins: R7 flow (2 %), R3 sound (0.5 dB), reel capacity (8 %).

### Decisions made under the pre-approval

- CBK-DDR-001, D1 to D10 (above).
- CBK-DDR-002, P1 to P12: the design-for-construction changes listed below.
- Open decisions: none. Items to confirm when parts are bought are in CBK-DEC-001 (pump displacement and flange, reel bore, hose diameter, jet orifice, sounder level, wheel hubs, relief setting).

### Build plan findings: design changes made for construction (2026-10-03)

1. Cart frame made a welded ladder frame of 30 mm square tube with bearers (P1).
2. Through axle in four 8 mm axle plates with spacers, collars and R-clips (P2).
3. Front legs with rubber feet so the cart parks level (P3).
4. Handle arms sitting on the rail tops, coped to the cross bar (P4).
5. Pump stand plate with gussets; pump bolted with four M12 bolts (P5).
6. Clamp-on lever extension with a T-bar for two people (P6).
7. Reel drum on a spindle in two welded uprights with a swivel inlet (P7).
8. Connecting hose from pump to reel, relief valve on a tee pointing down (P8).
9. Station on four posts in concrete collars instead of a two-post cantilever (P9).
10. Bought fixings for the station box, siren, panel and sign (P10).
11. Folded hose tray bolted to the bearers (P11).
12. Heat alarm on an aluminium plate hung by two ties under a roof pole; thermistor in a printed guard (P12).

### Appearance model

`cad/src/product_model.py` uses the model components unchanged; it only adds context (ground, a 1.75 m mannequin beside the drum, a forearm and hand beside the alarm) and leaves out the buried post ends and collars. No appearance deviations from `model.py`.

### Safety concerns

- Pressurised water line: relief valve at 4 bar fitted before first pumping, hose rated 10 bar, safety stops in build plan section 6.
- Sealed lead-acid station battery: fused at the terminal, connected last, locked box.
- A 91 kg cart on slopes: two people pulling, a third holding back on steeper slopes.
- Use limits: small, early fires only; people leave first; never water on oil or live wiring; drills only with the fire service or camp fire safety focal point present.
- No certification is claimed for the alarms or the firefighting equipment.

### Recommended next step

Photoreal renders and storefront images on Amish's Mac (`/render-product`). TRL 4 (build and test to CBK-BLD-001, starting with the pump flow and relief check and the cooking trial) needs a new instruction from Amish.

## 2026-10-03: photoreal renders

Rendered with Blender Cycles on Amish's Mac from `cad/src/product_model.py`; captioned with `.kit/photo_caption.py`; `media/card.png` and `media/social-preview.png` made with `.kit/cards.py`. Views: hero, exploded, detail. image_qc passes and `render.py --check` has no FAIL.

## 2026-10-03: Amish's requirement decisions carried out

Amish, 2026-10-03: "1A 2A 3A 4A 5A 6A 7A 8A 9A 10A 11A". For CampBreak this is decision 1A on R9 (water on target within 3 min at 100 m), recorded in `docs/decisions/0003-r9-response-time.md` (CBK-DDR-003) and in the register `docs/06-design-decisions.md` (CBK-DEC-001 v0.2).

### Changes made, with the new result for each

| Change | Files | New result |
| --- | --- | --- |
| Brass spring-loaded foot valve with a positive-seal check, so the pump and suction hose stay primed | `cad/src/model.py`, `bom/bom.csv` line 13 (USD 40, was 28) | No priming at the fire; suction loss factor raised to 7.0 (est.); R7 flow unchanged at 20.4 L/min, 47 W per person |
| Suction hose left coupled to the pump inlet by its cam-lever adaptor with a 90° elbow tail, run along the top of the left rail under two rubber straps and onto its coil in the tray | `cad/src/model.py` (new parts `suction_adaptor`, `suction_run`, `hose_straps`; 18 new checks, 115 of 115 pass), STEP and STL, `bom/bom.csv` lines 14 and 20 (new, USD 5) | Clears the wheels by 20 mm, the ground by 173 mm and the swung lever by 166 mm; tightest hose bend 63 mm radius |
| "Go when two arrive" with a 30 s gather on a laminated drill card, the station sign and in the build plan | `docs/05-build-plan.md` section 5a (drill card), Step 12, first checks; sign sketch CBK-DWG-111; `bom/bom.csv` line 18 (USD 27, was 25) | Gather 30 s instead of the 60 s muster |
| R9 recomputed (CBK-CAL-001 v0.2, section E), now with the 26 s to fill the empty 30 m delivery hose, which v0.1 left out | `docs/04-calcs/sizing.py`, `01-sizing.md`, `results.csv`; `docs/03-requirements.md` v0.4 (wording unchanged, result updated) | **R9 at 100 m: 191 s (3.2 min) against 180 s, still not met on paper, 11 s over** (3.8 min before; 4.2 min like for like with the fill counted). At 70 m, the siting margin kept: 161 s (2.7 min), met |
| Cart mass and pull | `sizing.py`, `01-sizing.md` | 94.6 kg stowed primed (was 91.4), including 2.6 kg of water; 92 N per person on a 10 % slope; R6 still met (1.7 min) |
| Cost | `bom/bom.csv` | Value-engineering target: USD 1,600. Estimated cost of the constructable design: USD 1,374 (USD 226 under the target). `budget_usd` unchanged |

Pictures changed: general arrangement CBK-DWG-001 (Rev P2), concept sheet CBK-DWG-010 (Rev P2), `media/hero.png`, `media/exploded.png`, `media/model.glb`, build plan overview, sign sketch CBK-DWG-111, new joint 12 (Figure 17; later figures renumbered), Step 6 to Step 17. Documents also updated: `docs/02-concept.md` v0.4, `docs/01-problem.md` v0.4 (cost), `README.md`, `project.yaml` (evidence), `cad/src/product_model.py` (materials for the new parts; scenes re-exported to `/home/claude/renders/campbreak`). `Compound(children=...)` replaced by `Compound([...])` in the scripts.

### Decision proposed, awaiting Amish

Stow the 30 m delivery hose full of water as well (CBK-DEC-001, open decision 1). Options: (a) leave as is, R9 not met at 100 m by 11 s, the 70 m margin holds; (b) stow the hose full behind the shut nozzle: 177 s (2.95 min) at 100 m, met with 3 s to spare, 8.9 kg more on the cart (about 101 N per person on a 10 % slope, just over the 100 N assumed sustainable), no new parts; (c) restate R9 to 3.25 min. Recommendation: (b).

### Safety

- The first pumper works alone for a minute or two until others arrive, at about 95 W, above the 75 W assumed sustainable for 10 min (est.); the drill checks it.
- "Go when two arrive" never means one person with the cart or running with it; people leave the shelter first. Both are on the drill card.
- The foot valve's seal is now a working part; the weekly prime check on the drill card finds a leak.

### Recommended next step

Amish decides open decision 1. TRL 4 (build and test to CBK-BLD-001, including the week-long prime hold and the timed drill at 70 m and 100 m) needs a new instruction from Amish.

## 2026-10-03: photoreal renders redone after Amish's requirement decisions

Rendered with Blender Cycles on Amish's Mac from `cad/src/product_model.py`; captioned with `.kit/photo_caption.py`; `media/card.png` and `media/social-preview.png` made with `.kit/cards.py`. Views: hero, exploded, detail. image_qc passes and `render.py --check` has no FAIL.

## 2026-10-03: Amish's round-2 requirement decisions carried out

Amish, 2026-10-03: "i agree with all the 46 recommendations you provided. please proceed." For CampBreak this is decision 1A: stow the delivery hose full of water on the cart, recompute R9 at 100 m and the pull per person. Recorded in `docs/decisions/0004-delivery-hose-stowed-full.md` (CBK-DDR-004) and in the register `docs/06-design-decisions.md` (CBK-DEC-001 v0.3).

### Changes made, with the new result for each

| Change | Files | New result |
| --- | --- | --- |
| Delivery hose (8.5 L) and connecting hose (0.3 L) stowed full of water behind the shut nozzle; no new parts and no geometry change | `docs/04-calcs/sizing.py` (water in the hoses added to the cart mass and centre of mass), `docs/04-calcs/01-sizing.md` v0.3, `results.csv`, `bom/bom.csv` line 11 note | Cart 103.4 kg stowed (was 94.6 kg), 8.9 kg more |
| R9 recomputed (CBK-CAL-001 v0.3, section E): no fill time at the fire | `01-sizing.md`, `results.csv`, `docs/03-requirements.md` v0.5 (wording unchanged) | **R9 at 100 m: 2.95 min (177 s) against 3 min, met on paper with 3 s to spare** (191 s before). At 70 m, the siting margin: 2.5 min (147 s). The 25 s to run out the hose and aim now sets the pace |
| Pull per person recomputed | `01-sizing.md` section D | **101 N per person on a 10 % slope (was 92 N), 1 N over the 100 N assumed sustainable.** R6 time (1.7 min) and width (850 mm) are still met; the pull is at the edge of the assumption and the TRL 4 pulling trial measures it |
| Build plan and drill card | `docs/05-build-plan.md` v0.3: Step 12 now fills the delivery hose; new first check "Hose stays full"; weekly check on the drill card also checks the hose is full; weight in the safety note | Text only; build plan pictures unchanged because the model is unchanged |
| Cost | `bom/bom.csv` | Value-engineering target: USD 1,600. Estimated cost of the constructable design: USD 1,374 (USD 226 under the target). `budget_usd` unchanged |
| Documents restated | `docs/02-concept.md` v0.5, `README.md` | Mass, pull and R9 figures updated |

Pictures changed: general arrangement CBK-DWG-001 (Rev P3) and concept sheet CBK-DWG-010 (Rev P3), whose notes and key figures changed. The model, STEP, STL, hero, exploded view and build plan pictures are unchanged (no geometry change). The appearance model needed no change, so the photoreal renders stand and the existing views were re-exported without a change.

### Decisions proposed, awaiting Amish

None. Open decision 1 is closed.

### Safety

- The cart now weighs about 103 kg. Two people always move it, a third holds it back on slopes steeper than 10 %, and nobody runs with it.
- The pull of 101 N per person is 1 N over the 100 N assumed sustainable; the margin on R9 is only 3 s. Both are honest thin points, to be measured at TRL 4.
- A full delivery hose is kept shut at the nozzle; the 4 bar relief valve protects it if the sun heats it.

### Recommended next step

TRL 4 (build and test to CBK-BLD-001, including the week-long hose-full hold, the pulling trial with the effort per person, and the timed drill at 70 m and 100 m) needs a new instruction from Amish.

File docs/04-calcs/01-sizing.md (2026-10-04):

---
doc_id: CBK-CAL-001
title: CampBreak sizing calculations
project: CampBreak
doc_type: Calculation note
version: "0.3"
status: Draft
date: '2026-10-03'
author: Amish Chadha
license: CERN-OHL-S-2.0
revisions:
- version: "0.1"
  date: '2026-10-03'
  author: Amish Chadha
  change: First calculation note at TRL 3, on the constructable design (CBK-DDR-002)
- version: "0.2"
  date: '2026-10-03'
  author: Amish Chadha
  change: "Amish's R9 decision (CBK-DDR-003): check foot valve, suction hose left coupled, go-when-two-arrive rule; R9 timeline recomputed with the delivery hose fill time added; cart mass and cost updated"
- version: "0.3"
  date: '2026-10-03'
  author: Amish Chadha
  change: "Amish's round-2 decision 1A (CBK-DDR-004): delivery hose stowed full of water; R9 recomputed at 100 m and 70 m; cart mass and pull per person recomputed"
---

# CampBreak sizing calculations

On paper the kit meets ten of its eleven requirements. The hand pump gives about 20.4 L/min with two people pumping at a sustainable 47 W each, the 6 mm jet reaches about 6.9 m, the alarms are loud enough and fast enough, and two people pull the loaded cart up a 10 % slope with about 101 N each, 1 N over the 100 N assumed sustainable. R2 (no false alarm while cooking) cannot be calculated and needs a cooking trial at TRL 4. R9 (water on target within 3 min for a shelter 100 m away) is now **met on paper**, at 2.95 min (177 s, 3 s to spare). Amish's R9 decisions of 2026-10-03 (CBK-DDR-003: check foot valve, suction hose left coupled to the pump, "go when two arrive" with a 30 s gather; CBK-DDR-004: delivery hose stowed full of water) bring the time from 3.8 min as first published to 2.95 min. A shelter at most 70 m from a station, the siting margin kept from CBK-DDR-001 (D9), gets water in 2.5 min. The kit costs about USD 1,374 against a value-engineering target of USD 1,600.

Every figure comes from `docs/04-calcs/sizing.py`, which reads its geometry from `cad/src/model.py` and its prices from `bom/bom.csv`, and writes `docs/04-calcs/results.csv`. Inputs marked (est.) are estimates to be confirmed by measurement at TRL 4.

> **Safety:** The pump and hose are a pressurised water system. A shut nozzle with two people pumping could reach several bar; the 4 bar relief valve (CBK-DDR-001, D7) caps it, and the hose is rated at 10 bar. The station battery is sealed lead-acid: it can deliver high short-circuit current and vents hydrogen if overcharged. The kit is for small, early fires only; people leave first, and water is never used on burning oil or live wiring.

## A. Pump, hose and nozzle (R7, R8)

### Assumptions

*Table 1. Inputs for the water line.*

| Input | Value | Note |
| --- | --- | --- |
| Pump displacement | 0.40 L per double stroke | (est.) to confirm on the pump bought |
| Pumping rate | 60 double strokes per minute | (est.) steady pace for two people |
| Volumetric efficiency | 0.85 | (est.) cast semi-rotary pump |
| Mechanical efficiency | 0.50 | (est.) lever, vanes and seals |
| Jet | 6 mm, discharge coefficient 0.96 | Nozzle orifice to confirm when bought |
| Delivery hose | 19 mm bore, 30 m, roughness 0.01 mm | Plus 1.2 m of 19 mm connecting hose |
| Delivery fittings | Loss factor 4.0 | (est.) swivel, tee and couplings |
| Suction | 25 mm, 4 m, loss factor 7.0, lift 1.5 m | (est.) spring check foot valve, strainer, elbow and coupling (CBK-DDR-003); worst case from a low open container |
| Nozzle height | 1 m above the pump | Slope or raised arm |
| Reach factor | 0.50 of the drag-free range at 30° | (est.) to measure |
| Sustained effort | 75 W per person for 10 min | (est.) |

### Method

Flow is displacement x rate x volumetric efficiency. Jet speed comes from the flow and the orifice; nozzle pressure is half the density times the jet speed squared. Hose friction uses the Darcy factor from the Swamee-Jain equation. The pump head is the sum of nozzle pressure, friction, fittings, lift to the nozzle and suction losses. Shaft power is hydraulic power over mechanical efficiency; the lever force follows from the work per double stroke over four 40° swings at a 610 mm grip radius.

### Results

*Table 2. Water line at two people pumping.*

| Quantity | Result |
| --- | --- |
| Flow at the nozzle | 20.4 L/min (R7 target 20) |
| Jet speed | 12.5 m/s |
| Pressure at the nozzle | 78 kPa |
| Hose friction, 30 m | 29.9 kPa at 1.2 m/s, Reynolds number about 22,800 |
| Pump outlet pressure | 122 kPa (1.2 bar), well under the 4 bar relief setting |
| Suction side | 17 kPa below atmosphere; 8.3 m of net positive suction head available |
| Hydraulic power | 47 W; shaft power 95 W, or 47 W per person |
| Force at the grip | 56 N in total, about 28 N per person |
| Force to reach the relief setting against a shut nozzle | 94 N in total, so two people can reach it |
| Jet reach | 6.9 m (13.9 m drag-free); R8 target 6 m |
| One 200 L drum | about 9.8 min of pumping |

Effort is well within the 75 W per person that can be kept up for 10 minutes, so R7 is met with margin on effort, though only with 2 % margin on flow. The flow depends directly on the pump's displacement, which must be confirmed on the pump bought (CBK-DEC-001, to confirm).

Figure 1 (`media/flow.png`) shows the pressure falling from the pump to the nozzle; all values are estimates.

## B. Heat alarm (R1 to R5)

*Table 3. Alarm inputs (est. unless stated).*

| Input | Value |
| --- | --- |
| Threshold | 8 °C per minute over 60 s, plus 57 °C fixed (decided, CBK-DDR-001 D2) |
| Sample interval | 10 s; 1 mA for 1 ms per sample |
| Sleep current | 3 µA |
| Radio listen for station broadcast | every 4 s, 10 mA for 1.5 ms |
| Daily check-in | one 60 ms transmission at 40 mA |
| Cells | 3 x AA alkaline, 2.4 Ah derated to 70 %, with a 30 min sounding reserve |
| Sounder | 95 dB(A) at 1 m |
| Alert | 100 ms transmission with three retries 1 s apart |

*Table 4. Alarm results.*

| Requirement | Result | Status |
| --- | --- | --- |
| R1 rate of rise | 8 °C per minute set in firmware; worst-case extra delay one 10 s sample | Met by design |
| R2 cooking | Not calculable on paper | To show at TRL 4 |
| R3 sound at 3 m | 95 - 20 log10(3) = 85.5 dB(A) | Met (est.), 0.5 dB margin |
| R4 relay time | 3.1 s alarm to station (with retries) plus 4.1 s for the station broadcast to reach every alarm: 7.2 s worst case | Met (est.) |
| R5 battery life | Average 6.9 µA; 331 months on paper, so cell shelf life (about 5 years) is the limit | Met (est.) |

R3 has little margin: a sounder of at least 95 dB(A) at 1 m is specified in the BOM, and a louder one is the first fix if the TRL 4 measurement falls short.

## C. Cart mass and balance (R6)

Steel parts are weighed from the model volumes at 7,850 kg/m³; bought parts use catalogue estimates (pump 14 kg, wheels 5.5 kg each, reel drum 9 kg, wound hose 11.4 kg, brass check foot valve 1.0 kg). Since CBK-DDR-003 the cart is stowed primed: the pump body (about 0.6 L, est.) and the 4 m suction hose (2.0 L) hold 2.6 kg of water, counted at the middle of the suction hose run. Since CBK-DDR-004 the 30 m delivery hose (8.5 L) and the 1.2 m connecting hose (0.3 L) are stowed full too: 8.9 kg of water, counted at the wound hose and the connecting hose.

*Table 5. Cart mass and balance.*

| Quantity | Result |
| --- | --- |
| Loaded cart mass, stowed primed with the delivery hose full | 103.4 kg (est.), of which 2.6 kg is water in the pump and suction hose and 8.9 kg is water in the delivery and connecting hoses (94.6 kg before CBK-DDR-004) |
| Centre of mass | 5 mm left of the centre line, 108 mm in front of the axle and 409 mm up |
| Load on the front feet when parked | 139 N |
| Lift at the pull bar to raise the feet | 81 N |
| Tipping sideways | at 42° |
| Overall size | 850 wide x 1,744 long x 1,067 tall |

## D. Pulling effort and speed (R6)

Rolling resistance 0.10 on unpaved ground (est.), slope 10 %, two people. Pull force is the weight times the sine of the slope plus rolling resistance times the cosine: 202 N in all, 101 N each (92 N before the delivery hose was stowed full). That is 1 N over the 100 N per person assumed sustainable (est.), so the assumption is slightly exceeded, not comfortably met: the pull is a steady push on a 10 % slope for 100 m, and a third person on the cart or a halt on the way covers it. At 1.0 m/s, 100 m takes 1.7 min. The cart is 850 mm wide against a 900 mm limit. R6 is met on time and width (est.), with the pull per person at the edge of the assumption; the TRL 4 timed trial measures it.

## E. Time to water on target (R9)

Amish decided on 2026-10-03 (CBK-DDR-003, decision 1A): "1A 2A 3A 4A 5A 6A 7A 8A 9A 10A 11A". For CampBreak, 1A means three changes, with the 3 min target and the 70 m siting margin kept:

1. A brass spring-loaded foot valve with a positive-seal check holds the 4 m suction hose and the pump full of water between uses, so the pump does not need priming.
2. The suction hose stays coupled to the pump inlet by its cam-lever coupling and lies along the left rail, so nothing has to be coupled at the fire.
3. The drilled rule "go when two arrive": the first two volunteers at the station take the cart at once, at most 30 s after the siren. Others follow to the fire.

In round 2 Amish agreed to a fourth change (CBK-DDR-004): "i agree with all the 46 recommendations you provided. please proceed." The delivery hose (30 m of 19 mm hose and 1.2 m of connecting hose, 8.85 L) is stowed full of water behind the shut nozzle and refilled at the weekly check. The shut-off holds the water in, and the 4 bar relief valve already protects the full hose from heating in the sun.

On arrival the two split the work. One lifts the suction hose off the cart, drops the foot valve in the water and starts pumping. The other runs out the hose from the reel and aims. With the delivery hose full, water leaves the nozzle on the first strokes. Before CBK-DDR-004 the empty line had to fill first: 26 s at 20.4 L/min, which version 0.1 of this note left out.

*Table 6. Time from alarm to water on target.*

| Stage | 100 m (R9) | 70 m (siting margin) | Note |
| --- | --- | --- | --- |
| Alarm to siren | 7 s | 7 s | Section B |
| Gather: go when two arrive | 30 s | 30 s | Drilled; at most 30 s |
| Pull the cart out | 15 s | 15 s | (est.) |
| Walk at 1.0 m/s | 100 s | 70 s | Section D |
| Drop the coupled suction hose in the water | 10 s, at the same time | 10 s, at the same time | (est.) first person; no coupling, no priming |
| First strokes to lift water | 3 s, at the same time | 3 s, at the same time | (est.) pump and suction already full |
| Fill the delivery line | 0 s | 0 s | Stowed full (CBK-DDR-004); 26 s when stowed empty |
| Run out the hose and aim | 25 s | 25 s | (est.) second person; now sets the pace |
| **Total** | **177 s (2.95 min)** | **147 s (2.5 min)** | |

R9 is **met on paper** at 100 m: 177 s against 180 s, 3 s to spare, a thin margin on estimated inputs (walk speed, gather time and pull-out time are all drilled values at TRL 4). At 70 m, the siting margin kept from CBK-DDR-001 (D9), it is met with 33 s to spare.

*Table 7. What the decision changed, at 100 m.*

| Case | Time |
| --- | --- |
| Version 0.1 timeline (60 s muster, 30 s set-up, 15 s priming), as published | 227 s (3.8 min) |
| Version 0.1 timeline with the delivery line fill added | 253 s (4.2 min) |
| After CBK-DDR-003, delivery hose stowed empty | 191 s (3.2 min) |
| Decided design, delivery hose stowed full (CBK-DDR-004) | 177 s (2.95 min) |

On a like-for-like basis CBK-DDR-003 saves 62 s and CBK-DDR-004 a further 14 s (the 39 s after arrival, set by the drop, the first strokes and the 26 s fill, becomes 25 s, set by running out the hose). The price is 8.9 kg more on the cart, which raises the pull per person from 92 N to 101 N. That is slightly above the 100 N assumed sustainable, and the R6 time is still met. The hose must stay full for a week: a TRL 4 check confirms that the nozzle shut-off and the pump hold it.

Until the next volunteers arrive, one person pumps alone. Holding 60 double strokes a minute needs about 95 W at the shaft and 56 N at the grip from that person, more than the 75 W assumed sustainable for 10 minutes (est.), but for the minute or two until the others arrive it is a reasonable effort. The drill (build plan, section 5) checks it.

## F. Station roof and posts

Wind 30 m/s (est., a strong monsoon gust), net uplift coefficient 1.2 on the 3.1 m² roof: about 1,990 N of uplift, 500 N per post. Each concrete collar (300 mm across, 600 mm deep) weighs about 975 N, so uplift is resisted with a factor of about 2. A horizontal load of 210 N gives a bending stress of about 10 MPa at the foot of each 60 x 60 x 3 mm post, far below the 235 MPa yield of S235. The four-post frame weighs about 86 kg of steel plus 14 kg of roof sheet.

## G. Hose reel capacity

30 m of hose with a 28 mm outside diameter needs 18.5 L of space; the drum (200 mm core, 440 mm wound diameter, 210 mm wide, packing 0.785) offers 19.9 L, a ratio of 1.08. The hose fits with little room to spare, so it must be wound neatly (build plan, step 10).

## H. Cost (R11)

*Table 8. Cost of one block kit, from bom/bom.csv.*

| Part of the kit | USD |
| --- | --- |
| 24 heat alarms | 420 |
| Station (alarm box, frame and roof, sign, drum) | 317 |
| Hose cart | 637 |
| **Total** | **1,374** |

Value-engineering target: USD 1,600. Estimated cost of the constructable design: USD 1,374 (USD 226 under the target). CBK-DDR-003 added USD 19: the brass check foot valve (USD 12 more than the plain foot valve), two rubber hose straps (USD 5) and the laminated drill card (USD 2).

## Results against every requirement

*Table 9. Results (from results.csv).*

| ID | Requirement | Target | Result | Status |
| --- | --- | --- | --- | --- |
| R1 | Rate-of-rise threshold | 8 °C/min | 8 °C/min over 60 s, plus 57 °C fixed | Met by design |
| R2 | No alarm in 1 h of cooking at 1 m | No alarm | Not calculable on paper | To show at TRL 4 |
| R3 | Sound at 3 m | At least 85 dB(A) | 85.5 dB(A) | Met (est.) |
| R4 | Relay to station and all alarms | 10 s or less | 7.2 s worst case | Met (est.) |
| R5 | Battery life | 12 months or more | Cell shelf life, about 5 years | Met (est.) |
| R6 | Cart on a 10 % slope, 100 m | 3 min or less, width 0.9 m or less | 1.7 min; 101 N per person (1 N over the 100 N assumed); 850 mm wide | Met (est.) |
| R7 | Flow for 10 min | 20 L/min or more | 20.4 L/min; 47 W per person | Met (est.) |
| R8 | Jet reach | 6 m or more | 6.9 m | Met (est.) |
| R9 | Water on target 100 m away | 3 min or less | 2.95 min (177 s) at 100 m; 2.5 min at 70 m (siting margin) | Met (est.), 3 s to spare |
| R10 | Repairable locally | Hand tools, market parts | Every wear part is a market item | Met by design |
| R11 | Cost | Value-engineering target USD 1,600 | USD 1,374 | USD 226 under the target |

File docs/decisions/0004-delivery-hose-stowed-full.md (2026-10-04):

---
doc_id: CBK-DDR-004
title: CampBreak delivery hose stowed full (R9)
project: CampBreak
doc_type: Design decision record
version: "0.1"
status: Draft
date: '2026-10-03'
author: Amish Chadha
license: CERN-OHL-S-2.0
revisions:
- version: "0.1"
  date: '2026-10-03'
  author: Amish Chadha
  change: Amish's round-2 decision 1A on R9 carried into the design
---

# 0004: Response time (R9): delivery hose stowed full of water

- **Date:** 2026-10-03
- **Status:** decided by Amish, 2026-10-03 (round 2): "i agree with all the 46 recommendations you provided. please proceed." For CampBreak this is decision 1A, the open decision posed in CBK-DEC-001 v0.2.

## Context

After CBK-DDR-003 (primed pump, coupled suction hose, "go when two arrive") R9 was 191 s at 100 m against 180 s, 11 s over. The rest of the gap was the 26 s needed to fill the empty delivery hose (8.85 L at 20.4 L/min) at the fire.

## Options considered

| Option | What it means |
| --- | --- |
| A (chosen) | Stow the delivery hose full behind the shut nozzle, refilled at the weekly check. No new parts; the 4 bar relief valve already protects the full hose from heating in the sun |
| B | Leave as is: R9 not met at 100 m by 11 s; the 70 m siting margin holds |
| C | Restate R9 to 3.25 min at 100 m |

## Decision

Option A. The geometry does not change: the hose, reel, pump and nozzle are the parts already in the model. What changes is the way the cart is stowed and the drill card.

*Table 1. Changes.*

| Item | Was | Now |
| --- | --- | --- |
| Delivery and connecting hose | Stowed empty and drained | Stowed full of water (8.9 kg) behind the shut nozzle; filled at build plan Step 12 and checked every week |
| Drill card (BOM 18) | Weekly prime check only | The weekly check also confirms the delivery hose is full |
| Build plan | Step 12 drains the hose | Step 12 fills it; new first check "Hose stays full" |

## Consequences

*Table 2. Results (CBK-CAL-001 v0.3).*

| Item | Result |
| --- | --- |
| R9 at 100 m | 177 s (2.95 min) against 180 s: **met on paper, 3 s to spare** (191 s before). The 25 s to run out the hose and aim now sets the pace |
| R9 at 70 m (siting margin) | 147 s (2.5 min) |
| Mass | Cart 103.4 kg stowed (was 94.6 kg), 8.9 kg more |
| Pull per person | 101 N on a 10 % slope (was 92 N). This is **1 N over the 100 N assumed sustainable**, so the assumption is slightly exceeded. R6 time (1.7 min) and width (850 mm) are still met. A third person on the handle or a halt on the way covers it, and the TRL 4 pulling trial measures the real effort |
| Margin | 3 s on R9 is thin; walk speed, gather time and pull-out time are estimates and the TRL 4 drill decides |
| Cost | Unchanged: no new parts. Value-engineering target: USD 1,600. Estimated cost of the constructable design: USD 1,374 (USD 226 under the target); `budget_usd` unchanged |
| Model | Unchanged geometry; 115 of 115 constructability checks still pass; STEP and STL not regenerated |
| Drawings | CBK-DWG-001 Rev P3; concept sheet CBK-DWG-010 Rev P3 |

To confirm at TRL 4: the nozzle shut-off and the pump hold the hose full for a week with no drip.

## Safety

> **Safety:** CampBreak includes a pressurised hand-pumped water line (relief valve at 4 bar, hose rated 10 bar) and a sealed lead-acid station battery. The cart now weighs about 103 kg: two people always move it, a third holds it back on slopes steeper than 10 %, and nobody runs with it. The full hose is kept shut at the nozzle; the relief valve protects it if the sun heats it. The kit is for small, early fires only; people leave first, and water is never used on burning oil or live wiring. It is an open engineering reference, not certified equipment.

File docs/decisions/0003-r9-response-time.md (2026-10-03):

---
doc_id: CBK-DDR-003
title: CampBreak response time (R9) changes
project: CampBreak
doc_type: Design decision record
version: "0.1"
status: Draft
date: '2026-10-03'
author: Amish Chadha
license: CERN-OHL-S-2.0
revisions:
- version: "0.1"
  date: '2026-10-03'
  author: Amish Chadha
  change: Amish's requirement decision 1A on R9 carried into the design
---

# 0003: Response time (R9): primed pump, suction hose left coupled, go when two arrive

- **Date:** 2026-10-03
- **Status:** decided by Amish, 2026-10-03: "1A 2A 3A 4A 5A 6A 7A 8A 9A 10A 11A". For CampBreak this is decision 1A.

## Context

R9 asks for water on target within 3 minutes of the alarm for a shelter 100 m from the station. At TRL 3 (CBK-CAL-001 v0.1) the time was 3.8 min, so R9 was not met on paper; CBK-DDR-001 (D9) kept the target and added a siting rule, no shelter more than 70 m from a station. The time at the fire was spent on a 60 s muster, 30 s to couple the suction hose and run out the hose, and 15 s to prime the pump.

## Options considered

| Option | What it means |
| --- | --- |
| A (chosen) | Fit a foot valve with a check so the pump stays primed; stow the suction hose coupled to the pump with a cam-lever (camlock class) coupling; drill the rule "go when two arrive" with a 30 s gather and put it on the drill card and in the build plan. Keep the 3 min target and keep "stations within 70 m of every shelter" as the siting margin |
| B | Leave the design and rely on the siting rule only |
| C | Lower the target or shorten the distance in R9 |

## Decision

Option A. The changes made:

*Table 1. Changes.*

| Item | Was | Now |
| --- | --- | --- |
| Foot valve (BOM 13) | Plain foot valve strainer | Brass spring-loaded foot valve, 25 mm, with a positive-seal check and a stainless strainer; holds the suction hose and pump full between uses |
| Suction hose stowage (BOM 13, 14) | Coiled loose in the tray; coupled to the pump at the fire | Left coupled to the pump inlet by its cam-lever adaptor with a 90° elbow tail; runs along the top of the left rail and onto its coil in the tray. The model checks it clears the wheels by 20 mm, the ground by 173 mm and the lever by 166 mm |
| Hose straps (new BOM 20) | None | Two rubber straps with buckles, round the left rail and the hose, 300 mm apart |
| Drill card (BOM 18) | Pump instruction label only | Laminated drill card in the station box: go when two arrive, the order of work at the fire, and the weekly prime check |
| Station sign (BOM 4) | Leave first, raise the alarm, fetch the cart | Adds "go when two arrive" |

## Consequences

*Table 2. Results (CBK-CAL-001 v0.2).*

| Item | Result |
| --- | --- |
| R9 at 100 m | 191 s (3.2 min) against 180 s: **still not met on paper, 11 s over**. Like for like, the decision saves 62 s (253 s before, once the hose fill is counted) |
| R9 at 70 m (siting margin) | 161 s (2.7 min): met |
| What remains | 26 s to fill the empty 30 m delivery hose, left out of the earlier figure. Stowing that hose full too would give 177 s (2.95 min); this is posed to Amish in CBK-DEC-001 |
| Mass | Cart 94.6 kg stowed primed (was 91.4 kg), including 2.6 kg of water; 92 N per person on a 10 % slope; R6 still met |
| Effort | The first pumper works alone until others arrive: about 95 W, more than the 75 W assumed sustainable for 10 min (est.), for a minute or two |
| Cost | USD 1,374 for the block kit (USD 19 more), USD 226 under the USD 1,600 value-engineering target (`budget_usd` unchanged) |
| Model | 115 constructability checks (18 new), all pass |
| Drawings | CBK-DWG-001 Rev P2; concept sheet CBK-DWG-010 Rev P2; sign sketch CBK-DWG-111 notes; build plan joint 12 and step 12 |

The foot valve's seal is now a working part: if it leaks, the pump loses its prime and about 15 s is lost at the fire. The drill card's weekly prime check finds it, and the leak-down rate is added to the items to confirm when parts are bought.

## Safety

> **Safety:** CampBreak includes a pressurised hand-pumped water line (relief valve at 4 bar, hose rated 10 bar) and a sealed lead-acid station battery. Going when two arrive must not mean going alone or running with the cart: two people always move it, and people leave the burning shelter first. The kit is for small, early fires only; water is never used on burning oil or live wiring. It is an open engineering reference, not certified equipment.

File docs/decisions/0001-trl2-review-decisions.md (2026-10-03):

---
doc_id: CBK-DDR-001
title: CampBreak TRL 2 review decisions
project: CampBreak
doc_type: Design decision record
version: "0.1"
status: Draft
date: '2026-10-03'
author: Amish Chadha
license: CERN-OHL-S-2.0
revisions:
- version: "0.1"
  date: '2026-10-03'
  author: Amish Chadha
  change: TRL 2 review items decided under Amish's 2026-10-03 pre-approval
---

# 0001: TRL 2 review decisions

- **Date:** 2026-10-03
- **Status:** decided. Amish, 2026-10-03: "start with the first 14 repos from the list of 29 projects. I pre-approve the batch runs along with any recommendations you come up with. I also accept any cost overruns or variations from the assumed scope cost." Every item below is the recommendation made in the TRL 2 review and is therefore decided as recommended.

## Context

The scaffold (CBK-PRB-001 and CBK-PRC-001 v0.1) left five open questions: the alarm relay scheme, the size of a block kit, the flow and pressure needed, theft and misuse, and the first drill partner. Populating the repo to TRL 2 raised further choices: the pump type, the station power source, pressure protection, the hose and the response-time target. Amish pre-approved every recommendation for this batch on 2026-10-03, so each is recorded here as decided. Choices that touch safety take the conservative option, and the evidence that would relax them is stated.

## Options considered

*Table 1. Options for each item.*

| # | Item | Options |
| --- | --- | --- |
| D1 | Alarm relay scheme | (a) mesh in which every alarm repeats every other; (b) star: each alarm reports to the block station, which sounds the siren and sends one broadcast that every alarm repeats with its sounder; (c) wired loop |
| D2 | Detection rule | (a) smoke; (b) fixed temperature only; (c) rate of rise with a fixed-temperature back-up |
| D3 | Alarm electronics at TRL 3 | (a) design the board now; (b) specify the board by function and price it as a module assembly, leaving the board design and firmware to TRL 4 |
| D4 | Block kit size | (a) 12 shelters; (b) 24 shelters; (c) 48 shelters |
| D5 | Pump | (a) self-built piston pump; (b) bought double-acting semi-rotary (wing) pump; (c) stirrup pump |
| D6 | Station and alarm power | (a) lithium cells with solar charging; (b) 12 V sealed lead-acid battery with a 10 W panel at the station, alkaline AA cells in the alarms |
| D7 | Pressure protection | (a) none, the operators stop pumping; (b) a 4 bar spring relief valve on the pump outlet, hose rated 10 bar |
| D8 | Hose and nozzle | (a) 25 mm layflat; (b) 19 mm semi-rigid hose, 30 m, on a reel, with a 6 mm jet and spray nozzle |
| D9 | Response-time shortfall (R9) | (a) lower the target; (b) keep the 3 min target and add a siting rule: no shelter more than 70 m along the path from a station, with a 30 s muster drilled by volunteers |
| D10 | First partner and region | (a) Cox's Bazar camps, Bangladesh; (b) Northwest Syria; (c) informal settlements in South Africa |

## Decision

*Table 2. Items decided, 2026-10-03.*

| # | Item | Decision | Status |
| --- | --- | --- | --- |
| D1 | Alarm relay scheme | (b) star scheme on a sub-GHz licence-free radio band: the alarm sends its alert with three retries, the station sounds the 110 dB(A) siren and broadcasts once, and every alarm in range sounds. The scheme is published in full. It is not a mesh, and it will be checked against Lumkani's patents before release. | Decided by Amish, 2026-10-03 (pre-approval) |
| D2 | Detection rule | (c) rate of rise of 8 °C per minute averaged over 60 s, plus a 57 °C fixed back-up, from an NTC thermistor below the box | Decided by Amish, 2026-10-03 (pre-approval) |
| D3 | Alarm electronics | (b) specified by function (low-power controller, sub-GHz radio, thermistor input, sounder driver) and priced as a module assembly; board design and firmware are TRL 4 work | Decided by Amish, 2026-10-03 (pre-approval) |
| D4 | Block kit size | (b) 24 alarms, one station and one cart per drill block | Decided by Amish, 2026-10-03 (pre-approval) |
| D5 | Pump | (b) bought cast-iron semi-rotary pump, 25 mm ports, at least 0.40 L per double stroke; it is sold in markets in most target regions and is repairable with hand tools | Decided by Amish, 2026-10-03 (pre-approval) |
| D6 | Power | (b) no lithium cells anywhere in the kit: sealed lead-acid at the station, alkaline AA cells in the alarms. Conservative choice; lithium iron phosphate could be reconsidered with evidence of safe charging in 45 °C shade temperatures and a local recycling route. | Decided by Amish, 2026-10-03 (pre-approval) |
| D7 | Pressure protection | (b) 4 bar relief valve on a tee at the pump outlet, discharge pointing down, hose rated at least 10 bar. Conservative choice; the setting could rise only with a burst test of the bought hose and fittings at TRL 4. | Decided by Amish, 2026-10-03 (pre-approval) |
| D8 | Hose and nozzle | (b) 19 mm semi-rigid hose, 30 m on a reel, 6 mm jet and spray nozzle with shut-off; the hose pays out without being fully unrolled | Decided by Amish, 2026-10-03 (pre-approval) |
| D9 | R9 shortfall | (b) keep the target; stations are sited so that no shelter is more than 70 m along the path from one, and volunteers drill a 30 s muster. R9 is still reported as not met on paper for 100 m. | Decided by Amish, 2026-10-03 (pre-approval) |
| D10 | First partner and region | (a) Cox's Bazar camps, Bangladesh: the first candidate to approach is a camp shelter or site management agency with an existing community fire volunteer programme, together with the Bangladesh Fire Service and Civil Defence. Recorded as the first candidate, not as agreed. | Decided by Amish, 2026-10-03 (pre-approval) |

## Consequences

- CBK-PRB-001, CBK-PRC-001 and CBK-REQ-001 are revised to v0.3; the open questions are answered by D1, D4, D7, D9 and D10.
- Theft and misuse (an open question in CBK-PRB-001) are handled by the station layout: the cart parks under the station roof in view of the block, and the alarm box is a locked IP65 enclosure. No further parts were added.
- `budget_usd` stays at USD 1,600, a value-engineering target. The pitch and problem are unchanged.
- Nothing in this record authorizes building or testing; TRL 4 needs a new instruction from Amish.

## Safety

> **Safety:** CampBreak includes a pressurised hand-pumped water line (relief valve at 4 bar, hose rated 10 bar) and a sealed lead-acid station battery. The kit is for small, early fires only; people leave first, and water is never used on burning oil or live wiring. Safety stops are listed in the build plan, section 6. It is an open engineering reference, not certified equipment.

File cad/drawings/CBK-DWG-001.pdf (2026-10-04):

CONCEPT, NOT FOR FABRICATION | CampBreak · github.com/BoujeeEnjinia1701/campbreak

FRONT VIEW
Scale 1:25; looking at the front (along +Y)

TOP VIEW
Scale 1:25; looking down (along -Z)

RIGHT VIEW
Scale 1:25; looking at the right side (along -X)

850

1744 1067

ISOMETRIC VIEW
Not to scale; seen from the front right and above, about 30 deg elevation MAIN SIZES AND FIGURES
Overall 850 wide x 1744 long x 1067 tall
Wheel track 735; 400 mm wheels on a 20 mm axle Frame of 30 x 30 x 2 mm tube; deck 215 above the ground Pull bar 33.7 mm, 800 up, 820 long
Pump shaft 440 up; lever grip 610 from the shaft
Reel 500 mm flanges, spindle 535 up; 30 m of 19 mm hose
About 103 kg stowed primed, delivery hose full; 101 N each for two on a 10 % slope (est.) 20.4 L/min; jet reach about 6.9 m (est.)
Suction hose left coupled to the pump on the left rail; check foot valve keeps it primed Delivery hose stowed full behind the shut nozzle; no fill time at the fire
Block station and heat alarm: making sketches CBK-DWG-109 to 112
REV | DESCRIPTION | DATE | BY
P1 | First issue from the constructable TRL 3 model (CBK-DDR-002) | 2026-10-03 | AC
P2 | Suction hose stowed coupled to the pump, check foot valve (CBK-DDR-003) | 2026-10-03 | AC
P3 | Delivery hose stowed full; figures updated (CBK-DDR-004) | 2026-10-03 | AC
CAMPBREAK | github.com/BoujeeEnjinia1701/campbreak

## Hand-pumped hose cart for camp blocks: general arrangement

DRAWING NO.
CBK-DWG-001

REV
P3

SHEET
1 of 1

SIZE

## ANSI B

SCALE
1:25

UNITS
mm
PROJECTION | DATE
2026-10-03

DRAWN
Amish Chadha

MATERIAL / NOTES
S235 steel tube, welded and painted; bought pump, reel, hoses and wheels
Licensed CERN-OHL-S-2.0 · Design Molecule Lab · designmolecule.com | Generated from cad/src; do not edit by hand

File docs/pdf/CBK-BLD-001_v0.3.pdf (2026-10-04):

C A M P B R E A K · B U I L D P L A N

# CampBreak prototype build plan

Design Molecule Lab · designmolecule.com

D O C U M E N T CO N T RO L

Document ID | CBK-BLD-001 | Version | 0.3
Status | Draft | Date | 2026-10-03
Author | Amish Chadha | License | CERN-OHL-S-2.0
Project TRL | TRL 3 | Proof of concept
Repository | github.com/BoujeeEnjinia1701/campbreak
Source | docs/05-build-plan.md @ uncommitted

R EV I S I O N H I STO RY

Version | Date | Author | Change
0.3 | 2026-10-03 | Amish Chadha

Amish's round-2 decision 1A (CBK-DDR-004): delivery hose stowed full of water, filled at Step 12 and topped up at the weekly check; cart weight and pull updated

0.2 | 2026-10-03 | Amish Chadha | Amish's R9 decision 1A (CBK- DDR-003): check foot valve, suction hose left coupled to the pump and strapped to the rail, go-when-two- arrive drill card
0.1 | 2026-10-03 | Amish Chadha | First build plan; design made constructable (CBK-DDR-002)

D R A F T · N O T F O R F A B R I C A T I O N

## CampBreak prototype build plan

Plan, not yet built. How to build the first proof-of-concept prototype, component by component. Building and testing to it is TRL 4 work. Decisions are kept in the design decisions register (docs/06-design-decisions.md), not here.

### 1. What you are building


Figure 1. Every component pulled apart and numbered in build order: the hose cart (1 to 12), the block station (13 to
18) and one heat alarm (19, drawn five times its size).
The prototype is one block kit: a two-wheeled hose cart with a hand pump, a shaded block station for the cart with a siren and a water drum, and a heat alarm of the kind hung in each shelter (a drill block has 24). Figure 1 shows the 19 component groups in the order you make or fit them. The made parts are the welded cart frame, handle, pump stand and reel uprights, the axle and spindle pieces, the lever extension, a folded sheet-steel hose tray, the four station posts with their roof frame, the sign and the alarm's mounting plate and drilled box. Everything else is bought and fitted: wheels, pump, relief valve, reel drum, hoses, nozzle, couplings, roof sheet, drum, the station's box, battery, siren and panel, and the alarm's board, cells and sounder. The work is sawing, drilling and MIG welding mild steel tube and plate, folding thin sheet, pouring four concrete collars, and drilling plastic boxes. The parts cost about USD 1,374 from the bill of materials.

Safety: The finished cart is a pressurised water system: two people can push the pump to several bar against a shut nozzle, so the 4 bar relief valve must be fitted before the first pumping, discharge pointing at the ground. Welding needs a screen, gloves, a mask and a fire watch; grind and weld well away from fuel and shelters. The loaded cart weighs about 103 kg, with its pump, suction hose and delivery hose kept full of water: two people lift and move it. The station roof is put up from a stepladder by two people, never in wind. The station battery is sealed lead-acid: connect its fuse last.

### 2. What changed to make it buildable

The concept showed what the kit does; its parts were blocks with no stock size and no fixings. Each change below keeps what the kit does, and all of them are recorded in decision record CBK-DDR-002.
Table 1. Changes from the concept.

Component | The concept had | The buildable design has | Why
Cart frame | A solid platform | A welded frame of 30 mm square tube with two lines of bearers (Figure 2) | One tube size, square cuts, every joint a weld on a flat table
Wheels | Wheels on the frame sides, no axle mounting | A 20 mm through axle in four 8 mm axle plates, with spacers, collars and R-clips (Figure 15) | The axle runs in two plates each side and clears the tubes
Legs | None; the cart stood on its wheels only | Two short legs with rubber feet at the front | The cart parks level
Handle | A bar floating in front | Two arms sitting on the rail tops, coped to a cross bar (Figures 4 and 5) | A welded triangle at each foot
Pump mounting | Pump on the deck, no fixing | A 10 mm stand plate with two gussets; four M12 bolts (Figure 7) | Puts the shaft 440 mm up so the lever clears the wheels
Lever | The pump's own short handle | A clamp-on lever with a T-bar for two people (Figure 12) | About 28 N per person
Reel | A cylinder, no support | A bought drum on a 25 mm spindle in two welded uprights with a swivel inlet (Figure 9) | The hose pays out while the pump stays connected
Pump to reel | Nothing | A 1.2 m connecting hose and the 4 bar relief valve on a tee (Figure 16) | The relief water goes to the ground
Small parts | Loose | A folded tray bolted to the bearers (Figures 13 and 14) | Everything travels on the cart and drains
Station | Two posts holding a cantilever roof | Four posts in concrete collars, two beams, four purlins and a sheet (Figures 18 to 21) | Resists monsoon uplift with plain bolts and welds

Suction hose Coiled loose in the tray,

| coupled and primed at the fire | Left coupled to the pump inlet, strapped along the left rail, with a check foot valve that keeps the pump full (Figure 17; CBK-DDR-003) | Nothing to couple or prime at the fire: water about 30 s sooner
Heat alarm | A box glued to the roof | An aluminium plate on the box, hung on a roof pole by two ties (Figures 24 and 25) | Fits any bamboo pole; no screws into bamboo

### 3. Making the components

Make and check each component before the assembly step that needs it. Sizes are in millimetres. "Front" is the pull handle end of the cart; "left" and "right" are as seen standing behind the handle, facing the cart. Workshop tolerance is 1 mm on the cart and 5 mm on the station unless a step says otherwise; drawings carry no tolerances before TRL 4.

### 3.1 Cart base frame

Figure 2. Cart base frame making sketch (CBK-DWG-101).
What it is and what it is made from. The ladder frame everything on the cart hangs from. Mild steel square tube 30 x 30 x 2 mm (S235), about 7.6 m in all, and 8 mm flat plate for the four axle plates.
How to make it.
Cut two side rails 1,000 long, three cross members 540 long (cut the middle one later into pieces of 110, 260 and 110), two front bearers 320 long, two rear bearers 590 long and two legs 190 long. Square all ends and deburr.
Lay the side rails on a flat table, 540 apart inside. Weld the front cross member flush with the rail front ends and the rear one with its back face 30 in from the rail back ends. Check that the diagonals are equal within 3 mm, then weld.
Mark the middle cross member line 350 behind the front cross member. Fit its two 110 pieces from the rails inward and the 260 piece in the middle, leaving a 30 gap each side for the bearers.
Fit the bearers in those gaps, 260 apart inside: the front pair from the front cross member to the middle line, the rear pair from the middle line to the rear cross member. All tube tops flush. Weld.
Cut four axle plates 80 x 85 x 8. Clamp them as a stack and drill a 21 mm hole centred across the width, 40 up from the bottom edge.
Weld one plate on each side of each rail, centred 800 behind the rail front ends, tops flush with the rail top, with a 20 mm bar through all four holes so they line up. Remove the bar after cooling.
Weld a leg under each rail's front end, square to the rail.

1.

2.

3.

4.

5.

6.

7.

How it fits the parts next to it. The handle arms sit on the rail tops at the front (Figure 4). The pump stand plate sits on the rear cross member and its gussets on the rear bearers (Figure 7). The reel uprights stand against the inner faces of the rear bearers (Figure 9). The axle runs through the four plates (Figure 15). The tray sits on the bearers and the front cross member (Figure 14).
Check before moving on. The frame sits flat on the table without rocking; the 20 mm bar turns by hand in all four plates at once.

### 3.2 Pull handle

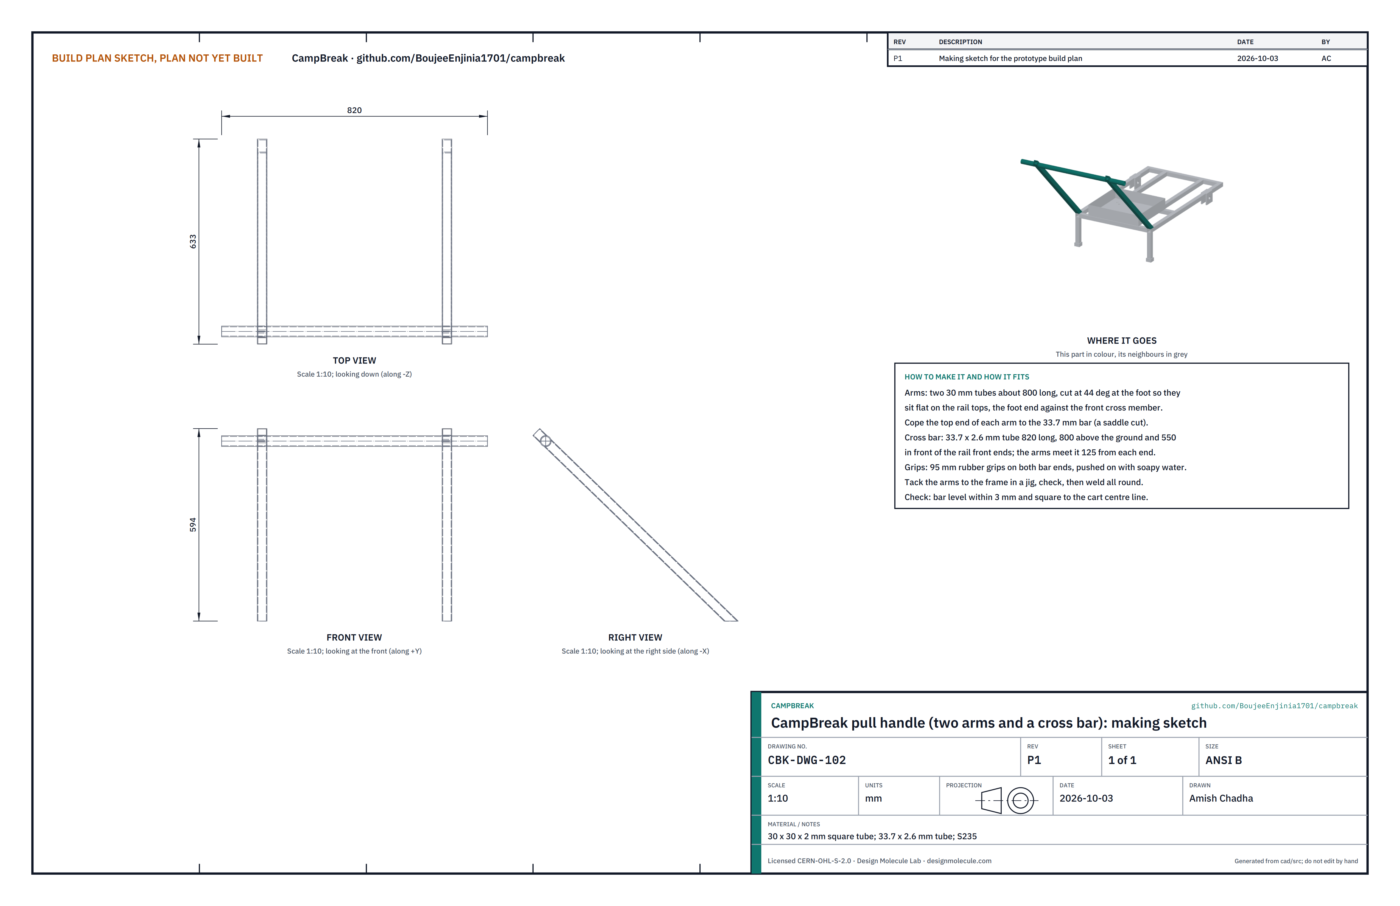
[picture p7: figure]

Figure 3. Pull handle making sketch (CBK-DWG-102).
What it is and what it is made from. Two arms and a cross bar that two people pull side by side. 30 x 30 x 2 mm square tube for the arms; 33.7 x 2.6 mm round tube, 820 long, for the bar; two rubber grips.
How to make it.
Cut two arms about 820 long. Cut the foot end of each at 44° so it lies flat on the rail top with its toe touching the front cross member's end.
Cope the top end of each arm to fit round the 33.7 mm bar (a saddle cut with a hole saw or a grinder and a paper template).
Set the frame on the table, clamp the bar 800 above the floor and 550 in front of the rail front ends, centred, and tack the arms to the rails and the bar, 125 in from each bar end.
Check that the bar is level and square to the frame, then weld all round.
Push a grip onto each bar end with soapy water.

1.

2.

3.

4.
5.

How it fits the parts next to it.

Figure 4. The arm foot sits flat on the rail top and its toe touches the end of the front cross member; welded all round.

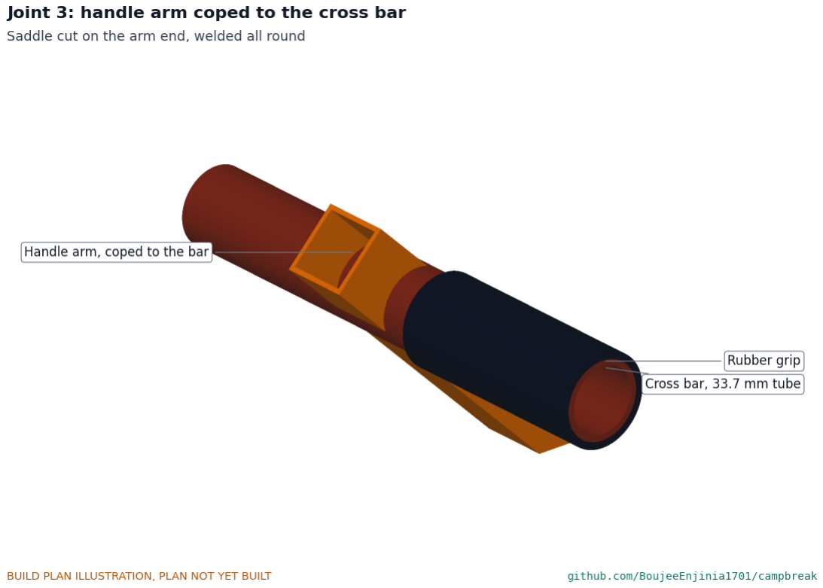
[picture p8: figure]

Figure 5. The saddle-cut arm end wraps the bar; welded all round.
Check before moving on. The bar is level within 3 mm. Lift the frame by the bar: nothing flexes visibly.

### 3.3 Pump stand plate and gussets

Figure 6. Pump stand making sketch (CBK-DWG-103).
What it is and what it is made from. An upright plate the pump bolts to, braced by two triangles. 10 mm plate 320 x 355; two 8 mm triangles 130 x 250.
How to make it.
Cut the plate 320 wide and 355 tall. Mark the centre line.
Lay the bought pump's flange on the plate, centred on the centre line with the shaft 195 up from the bottom edge, and mark its four holes (on a 150 mm square for the pump specified). Drill 13 mm.
Cut two right-angled triangles, 130 along the bottom and 250 tall.
Stand the plate on the rear cross member, its front face 10 behind the member's front face and square to the bearers. Weld it to the cross member on both sides.
Stand each gusset on a rear bearer, centred on it, against the plate's front face. Weld to the bearer and the plate.

How it fits the parts next to it.

1.
2.

3.
4.

5.

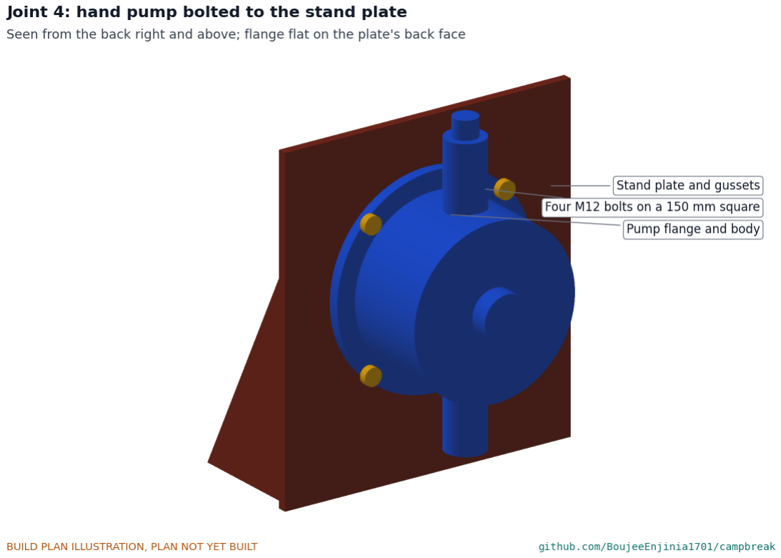
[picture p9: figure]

Figure 7. The pump flange sits flat on the plate's back face; four M12 bolts with washers both sides.
Check before moving on. The plate is upright within 1°; the pump's bolts pass through all four holes without forcing.

### 3.4 Reel uprights

Figure 8. Reel upright making sketch (CBK-DWG-104).
What it is and what it is made from. Two flat bars that carry the reel spindle. 50 x 8 mm flat bar, two pieces 365 long.
How to make it.
Cut both bars 365 long and clamp them together.
Drill a 26 mm hole through both, centred across the width, 320 up from the bottom end.
Stand each bar against the inside face of a rear bearer, bottom end flush with the bearer bottom, its centre 130 in front of the axle centre line. Pass a 25 mm bar through both holes to hold them in line, then weld along both edges.

How it fits the parts next to it.

1.
2.
3.

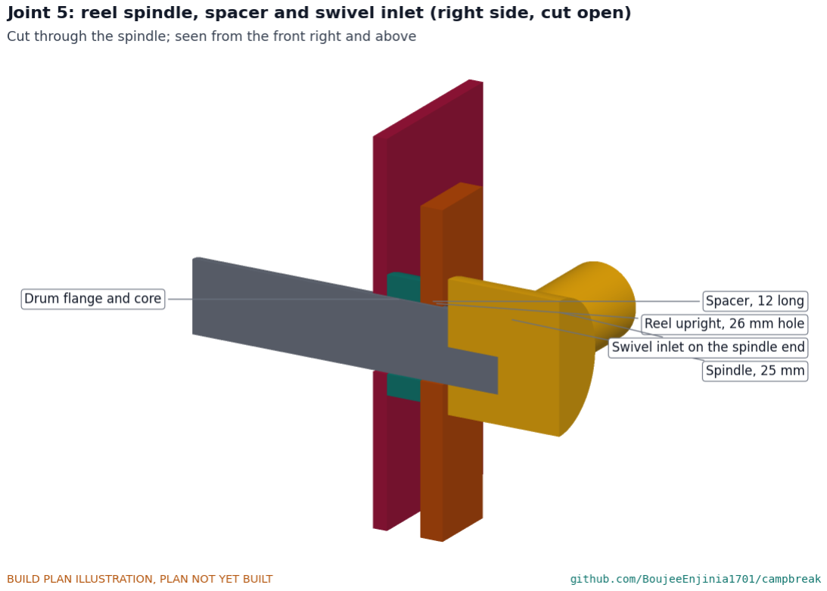
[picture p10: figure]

Figure 9. The spindle passes through the upright, a 12 mm spacer and the drum; the swivel inlet sits on the right-hand end.
Check before moving on. The 25 mm bar slides through both holes at once and is level within 2 mm.

### 3.5 Axle, wheel spacers and collars

Figure 10. Axle and spacers making sketch (CBK-DWG-105).
What it is and what it is made from. A 20 mm bright steel bar 850 long, two spacers cut from 32 x 22 mm tube, two bought 20 mm collars and two R-clips.
How to make it.
Cut the axle 850 long; chamfer both ends 1 mm.
Drill a 4 mm cross hole 6 from each end for the R-clips.
Cut two spacers 22 long from the tube; square and deburr the ends.

How it fits the parts next to it. See Figure 15 in section 3.9. From the middle out on each side: inner axle plate, rail, outer axle plate, spacer, wheel hub, collar, R-clip.
Check before moving on. With both wheels on, the axle end float is 1 to 2 mm and the wheels spin freely.

1.
2.
3.

### 3.6 Reel spindle and spacers

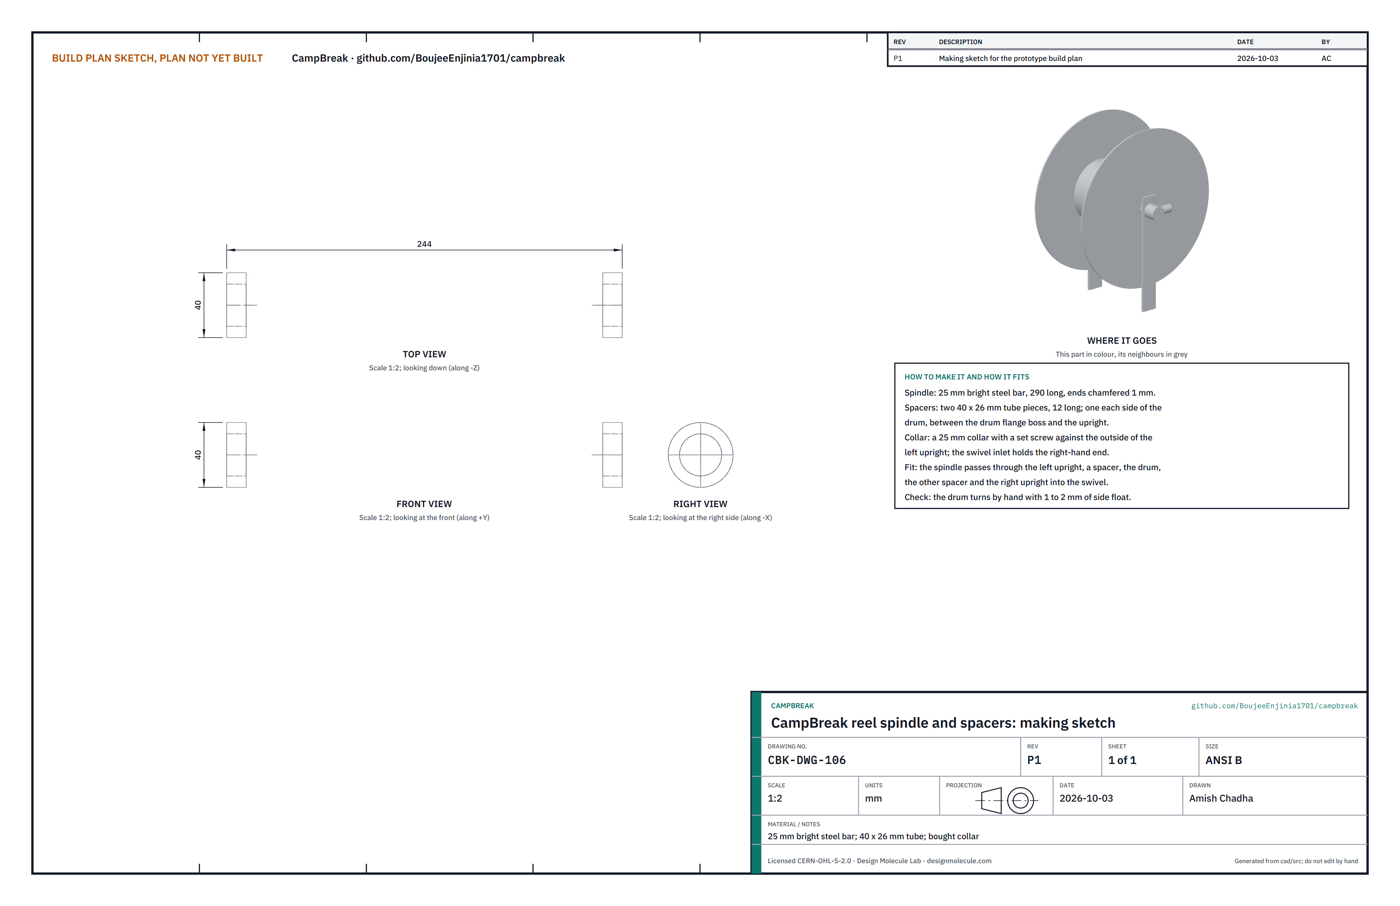
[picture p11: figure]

Figure 11. Reel spindle making sketch (CBK-DWG-106).
What it is and what it is made from. A 25 mm bright steel bar 290 long, two spacers cut from 40 x 26 mm tube, one bought 25 mm collar.
How to make it.
Cut the spindle 290 long; chamfer both ends 1 mm.
Cut two spacers 12 long; deburr.
Check the reel drum's bore against the spindle; if the bore is larger, sleeve it (see the register, to confirm).

How it fits the parts next to it. Figure 9: left upright, spacer, drum, spacer, right upright, swivel. The collar sits against the outside of the left upright.
Check before moving on. The drum turns by hand with 1 to 2 mm of side float.

1.
2.
3.

### 3.7 Lever extension with T-grip

Figure 12. Lever extension making sketch (CBK-DWG-107).
What it is and what it is made from. A clamp hub that fits the pump's handle socket, a 585 mm lever of 33.7 x 2.6 mm tube and a 400 mm T-bar of 27 x 2.3 mm tube with two grips.
How to make it.
Cut a 50 x 50 block 38 thick. Bore it to fit the pump's handle socket (measured on the pump bought), slot it on one side and drill and tap for two M10 clamp bolts.
Weld the lever tube upright on the hub.
Weld the T-bar across the top, square to the pump shaft, so the bar centre is 610 above the shaft centre. Push the grips on.

How it fits the parts next to it. The hub clamps on the pump's handle socket with the lever upright at mid-stroke. Two people face each other across the T-bar and swing it 40° each way.
Check before moving on. At both ends of the swing the grip is at least 50 from the wheels and 30 from the frame.

1.

2.
3.
4.

### 3.8 Hose tray

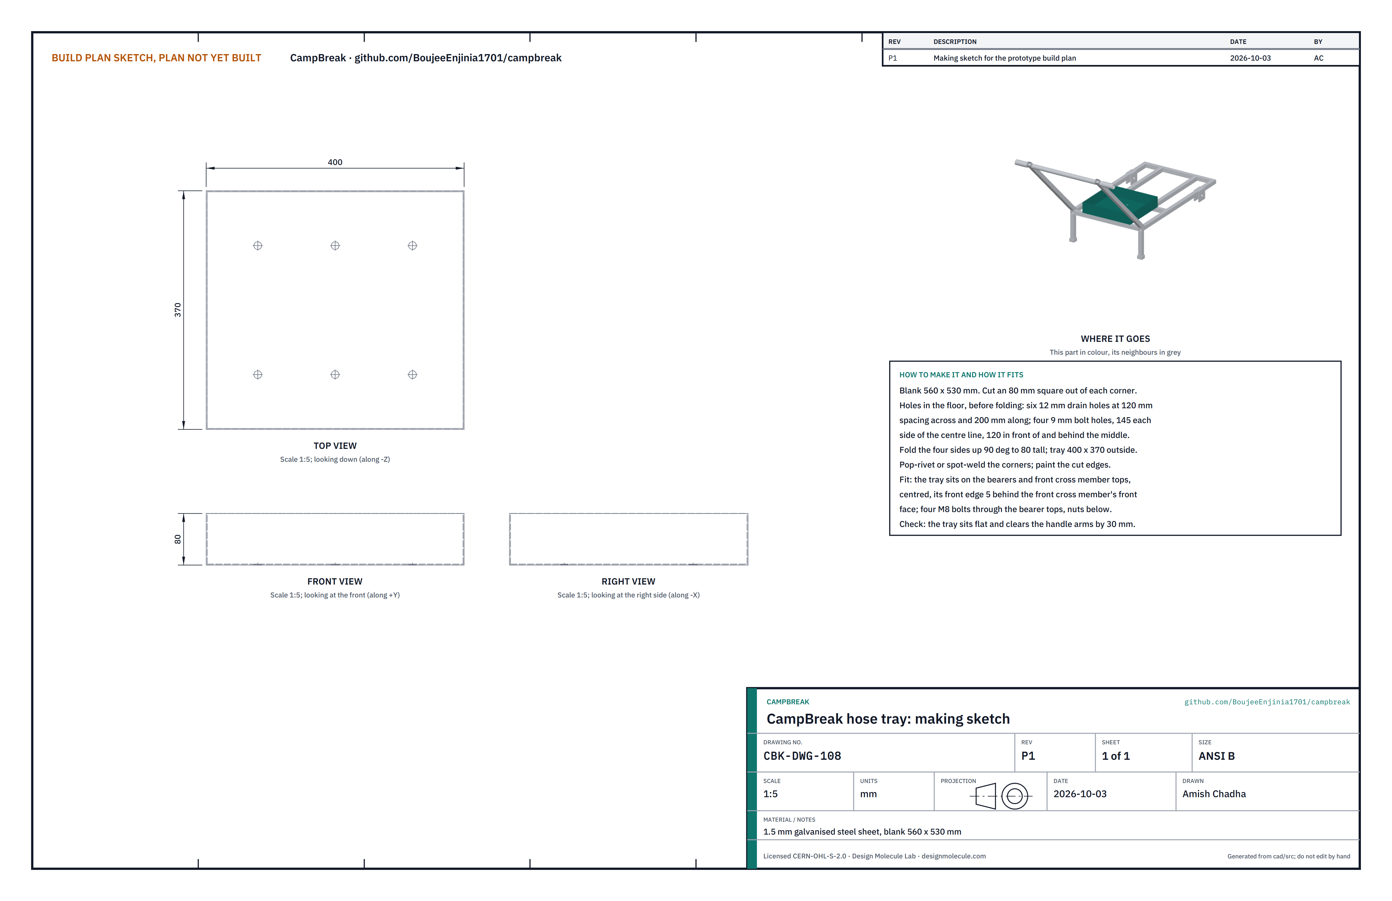
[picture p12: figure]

Figure 13. Hose tray making sketch (CBK-DWG-108).
What it is and what it is made from. An open tray that carries the suction hose and small parts. 1.5 mm galvanised steel sheet, blank 560 x 530.
How to make it.
Cut the blank and cut an 80 mm square from each corner.
Drill six 12 mm drain holes in the floor (three across at 120 spacing, two rows 200 apart) and four 9 mm bolt holes, 145 each side of the centre line and 120 in front of and behind the middle.
Fold the four sides up 90° to 80 tall. The tray is 400 x 370 outside.
Pop-rivet the corners and paint the cut edges with zinc-rich paint.

How it fits the parts next to it.

1.
2.

3.
4.

Figure 14. The tray floor sits flat on the tube tops; an M8 bolt through each bearer top, nut and washer below. Check before moving on. The tray sits flat and clears the handle arms by 30 mm.

### 3.9 Bought cart parts

What to buy for the cart (full specifications in the bill of materials), and what to do to each:
Wheels: two 400 mm puncture-proof wheelbarrow wheels, 100 mm wide, with 20 mm bore ball-bearing hubs 75 long. Nothing to do.
Hand pump: a cast-iron double-acting semi-rotary pump with 25 mm ports, at least 0.40 L per double stroke and rated for at least 40 m head. Measure its flange holes and handle socket before drilling the stand plate (3.3) and boring the lever hub (3.7).
Relief valve: a 19 mm spring relief valve set at 4 bar, with a tee. Fit it at the pump outlet with the discharge pointing down.
Reel drum: a steel reel drum with a 200 mm core and 500 mm flanges, 210 apart, and a 19 mm swivel inlet with a hose tail.
Hoses: 30 m of 19 mm semi-rigid hose rated at least 10 bar; 1.2 m of 19 mm reinforced hose and two clips for the pump to reel connection; 4 m of 25 mm wire-reinforced suction hose that bends to 60 mm radius or less. Foot valve: a 25 mm brass spring-loaded foot valve with a check that seals and a stainless strainer. It keeps the suction hose and the pump full of water between uses. Before you buy, fill one on its hose, hang it up and see that it holds water overnight.

•

•

•

•

•

•

Nozzle, couplings and tap adaptor: a jet and spray nozzle with shut-off and a 6 mm jet; three 25 mm cam-lever coupling sets, the suction hose's one with a 90° elbow hose tail; a push-on tap connector to a 25 mm hose tail. Hose straps: two rubber straps with buckles, 20 mm wide, long enough to go round the rail and the hose.

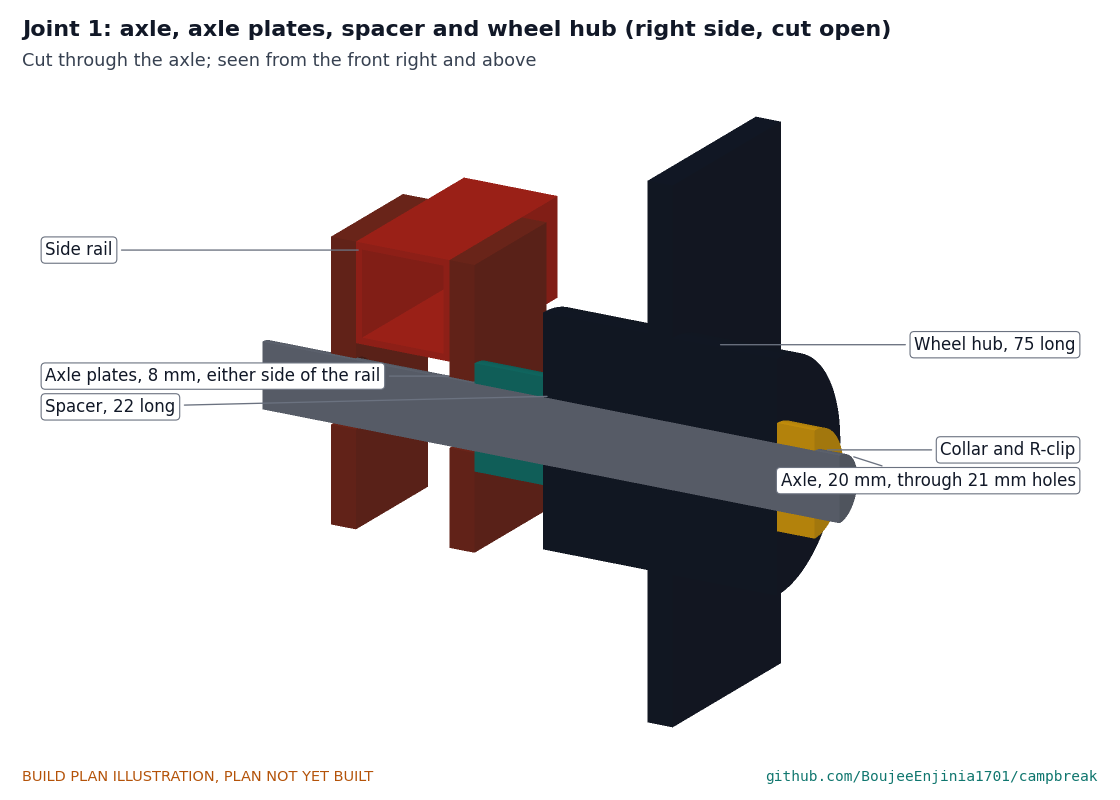
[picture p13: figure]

Figure 15. The axle passes through 21 mm holes in both axle plates; the spacer holds the hub clear of the outer plate; the collar and R-clip hold it on.

•

•

Figure 16. Seen from the back right: the relief valve sits on a tee at the pump outlet with its discharge pointing down; the connecting hose runs from the outlet tail over to the reel swivel, a clip at each end.

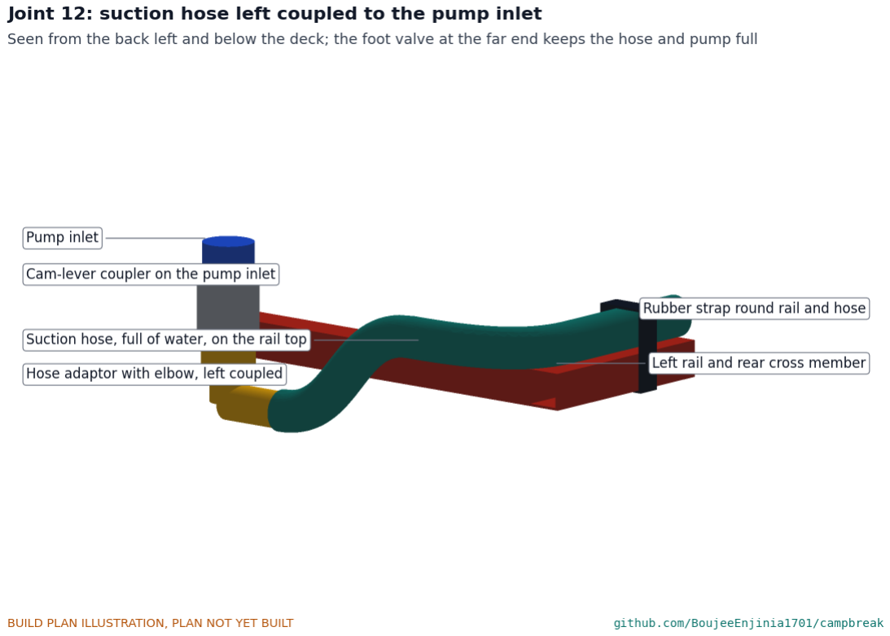
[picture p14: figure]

Figure 17. Seen from the back left: the suction hose's adaptor stays locked in the coupler under the pump. Its elbow sends the hose left, up behind the end of the left rail and forward along the rail top, under a rubber strap. The foot valve at the far end keeps the hose and the pump full of water.

### 3.10 Station posts and concrete collars

Figure 18. Station posts making sketch (CBK-DWG-109), left pair drawn.
What it is and what it is made from. Four posts of 60 x 60 x 3 mm square tube, two front posts 3,160 long and two back posts 3,000 long, each set 600 into a concrete collar 300 across. Four bags of concrete and some gravel.
How to make it.
Cut the posts to length with the tops cut at 5° so the roof falls toward the back.
Drill two 13 mm holes across each post top, 60 down, for the beam cleats.
Paint the bottom 700 of each post with bitumen and cap the tops.
Peg out the four post centres: 1,300 apart across and 1,800 front to back; check the diagonals are equal within 10.
Auger four holes 300 across and 650 deep. Put 50 of gravel in each.
Stand each post on the gravel, plumb it in both directions and brace it. Pour concrete to ground level, sloped away from the post. Leave three days before loading.

How it fits the parts next to it.

1.
2.
3.
4.

5.
6.

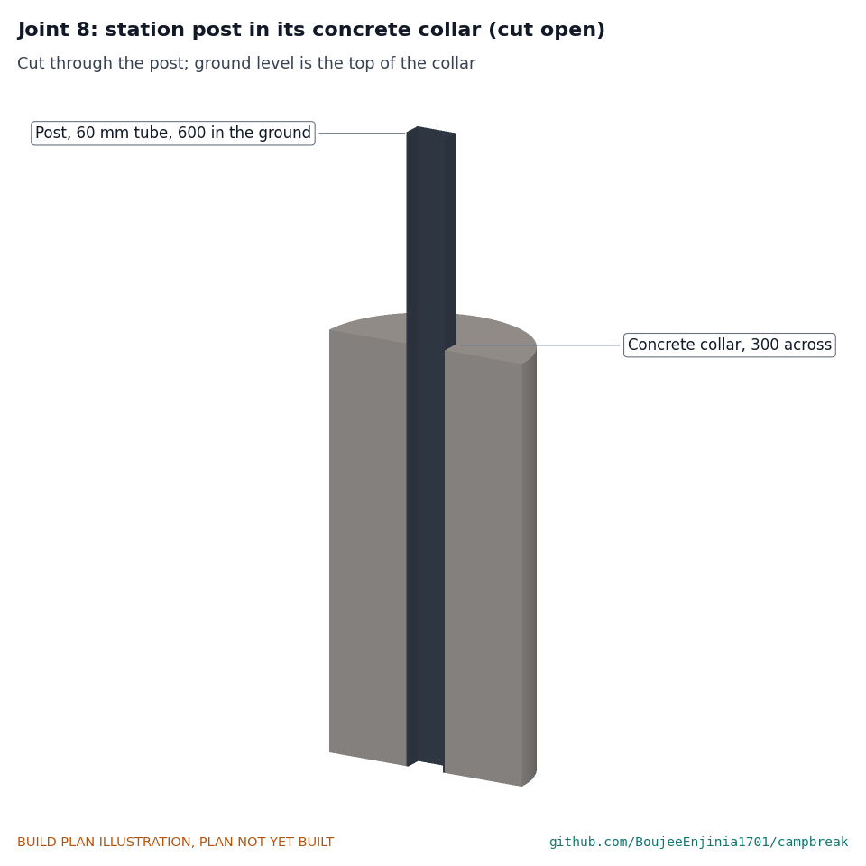
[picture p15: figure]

Figure 19. The post stands 600 into its collar; the top of the collar is ground level.
Check before moving on. Each post is plumb within 5 mm over 2 m; the back post tops are 2,400 above the ground.

### 3.11 Roof frame: beams, purlins and sheet

Figure 20. Roof beams and purlins making sketch (CBK-DWG-110).
What it is and what it is made from. Two beams of 40 x 40 x 2 mm tube, 2,000 long; four purlins of 40 x 20 x 2 mm tube, 1,500 long; one corrugated galvanised sheet 1,500 x 2,050; angle cleats, M8 bolts and roofing screws.
How to make it.
Cut the beams and purlins. Cut four cleats from 40 x 40 x 4 angle and drill them to match the post top holes. Bolt a cleat to each post top. Lift each beam onto a pair of posts so it reaches 100 past the front and back post centres, and bolt or weld it to the cleats.
Fix the purlins across the beams at 30, 660, 1,300 and 1,940 from the beams' front ends.
Screw the sheet to every purlin through every second crest, with sealing washers.

How it fits the parts next to it.

1.
2.

3.
4.

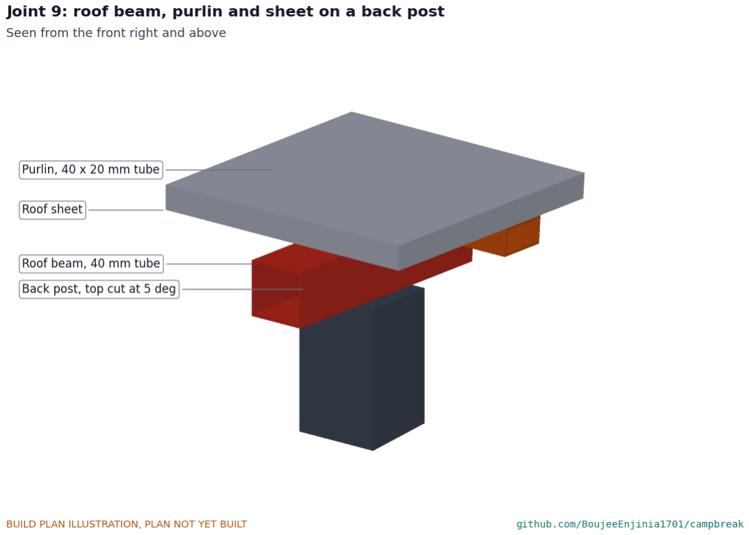
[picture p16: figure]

Figure 21. The beam sits on the cut post top; the purlins sit on the beams; the sheet sits on the purlins. Check before moving on. The roof falls 5° to the back and does not move when pushed at a corner.

### 3.12 Station sign

Figure 22. Station sign making sketch (CBK-DWG-111).
What it is and what it is made from. A 440 x 300 x 3 mm aluminium sheet with printed instructions in the camp languages and pictograms.
How to make it.
Cut the sheet and round the corners.
Drill two 9 mm holes on the centre line, 60 from the top and bottom edges.
Apply the printed vinyl: leave first, raise the alarm, fetch the cart, small fires only, never water on oil or live wires, call the fire service.

How it fits the parts next to it. It bolts to the front face of the back right post with two M8 bolts, bottom edge 1,100 above the ground.
Check before moving on. It reads clearly from 5 m in daylight.

### 3.13 Bought station parts

Station alarm box: a lockable IP65 box 300 x 300 x 150 holding the receiver board (the alarm board with a relay output), a solar charge controller and a 12 V 7 Ah sealed lead-acid battery with an inline fuse at its positive terminal. Drill it for the cable glands; mount it with U-bolts on the outer face of the back left post, bottom 1,400 above the ground.
Siren: a 12 V siren of at least 110 dB(A) at 1 m on a bolted bracket on the same post, 1,900 up.

1.
2.
3.

•

•

Solar panel: a 10 W 12 V panel 350 x 290 on two rails screwed to the roof sheet near the back edge. Water drum: a 200 L food-grade drum with lid, beside the right of the station.

### 3.14 Heat alarm: mounting plate, box and guard

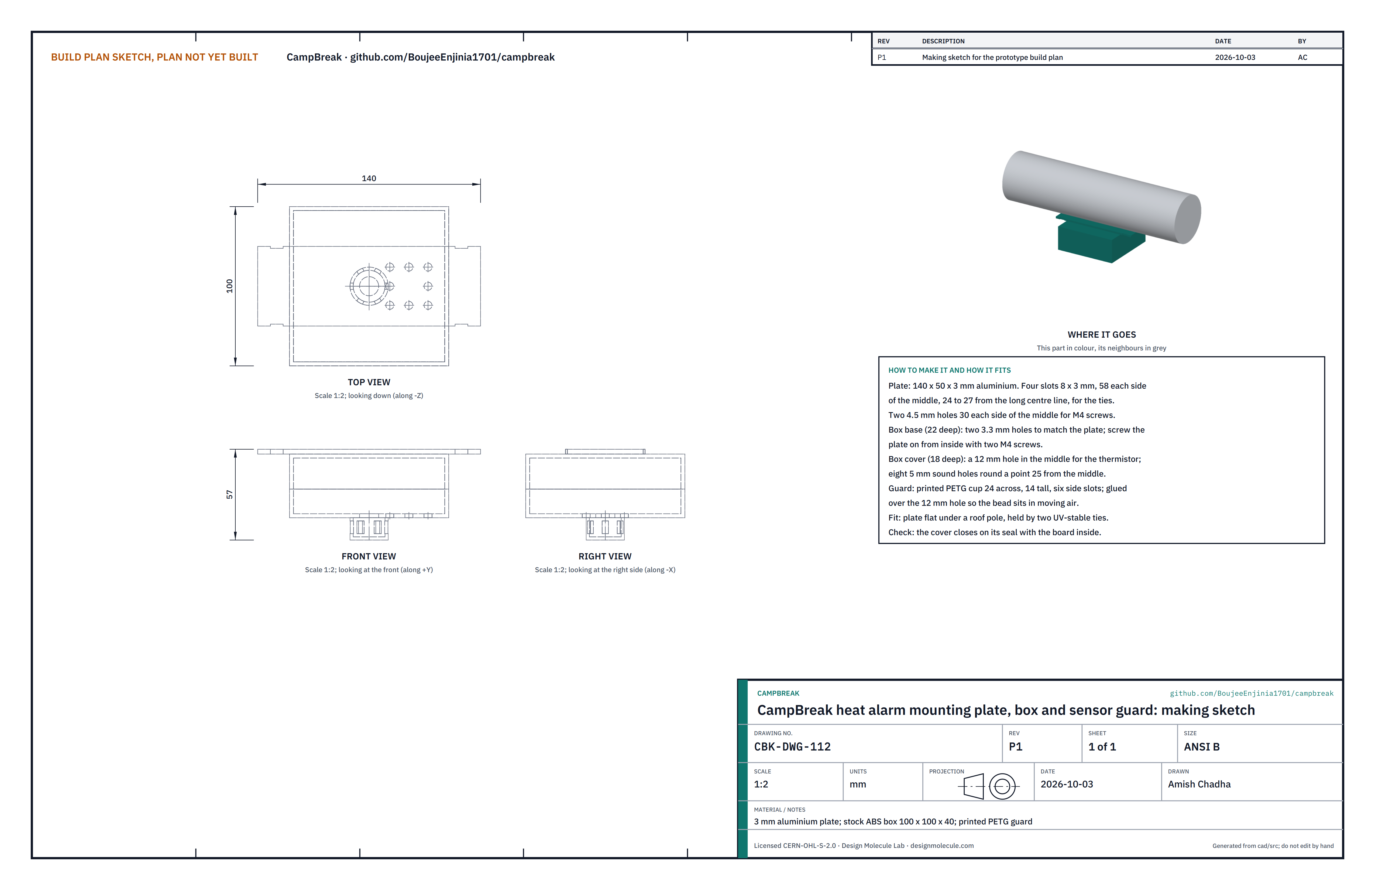
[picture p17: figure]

Figure 23. Heat alarm housing making sketch (CBK-DWG-112).
What it is and what it is made from. A 140 x 50 x 3 mm aluminium plate, a stock two-part ABS box 100 x 100 x 40, and a small printed guard cup in PETG. Bought parts inside: the alarm board (low-power controller and sub-GHz radio with a thermistor input), a thermistor on a 40 mm lead, a piezo sounder of at least 95 dB(A) at 1 m, a 3 x AA holder with alkaline cells, four standoffs, and two UV-stable cable ties.
How to make it.
Cut the plate. Mark and file four slots 8 x 3, 58 each side of the middle, from 24 to 27 off the long centre line. Drill two 4.5 mm holes 30 each side of the middle.
Drill the box base to match the plate holes (3.3 mm) and screw the plate on from inside with two M4 screws. Drill a 12 mm hole in the middle of the cover and eight 5 mm sound holes round a point 25 from the middle, over where the sounder will sit.
Print the guard (24 across, 14 tall, six side slots).
Fit the battery holder to the base with double-sided foam tape, screw the board onto its standoffs, lead the thermistor bead out through the 12 mm hole, close the cover and glue the guard over the hole.

How it fits the parts next to it.

•
•

1.

2.
3.

4.
5.

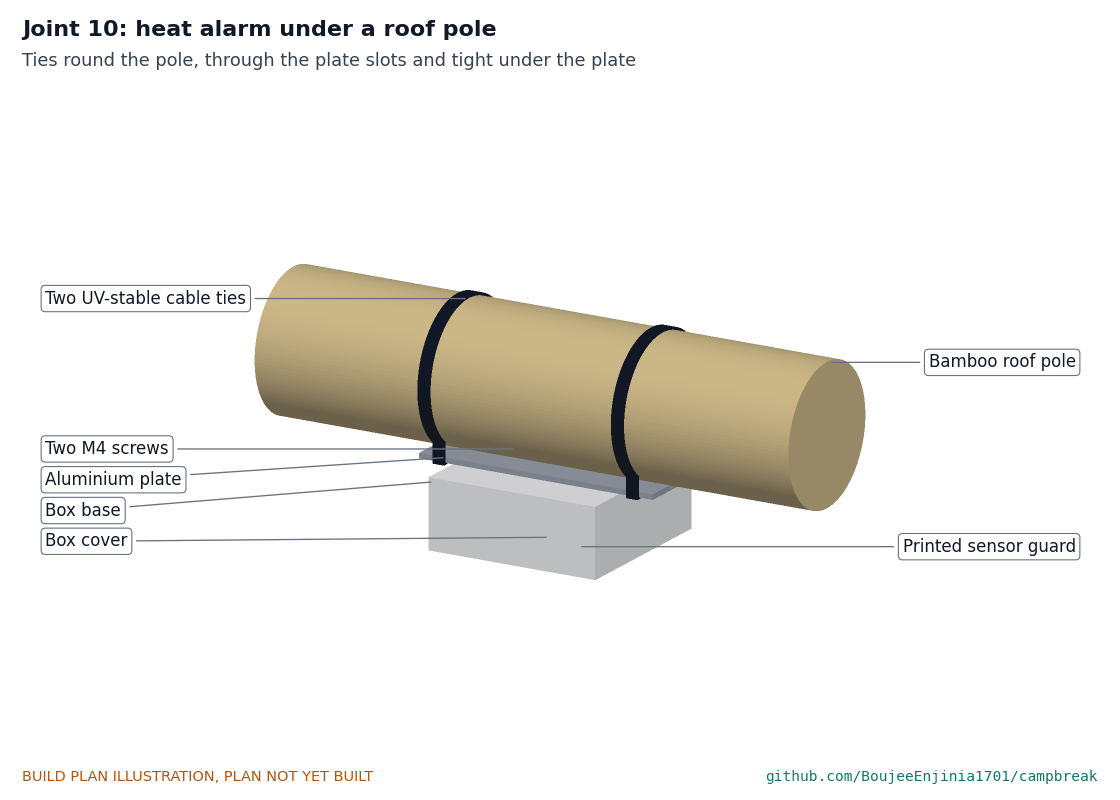
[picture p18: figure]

Figure 24. Two ties go round the pole, down through the plate slots and tight under the plate.

Figure 25. The board sits on standoffs 12 clear of the battery holder; the thermistor bead hangs in the guard below the box, in moving air.
Check before moving on. The cover closes on its seal with nothing pinched; the bead does not touch the guard.

### 4. Putting it together

Parts already fitted are grey; the part being fitted is in colour, pulled back along the way it goes in.

Step 1: Base frame on its feet

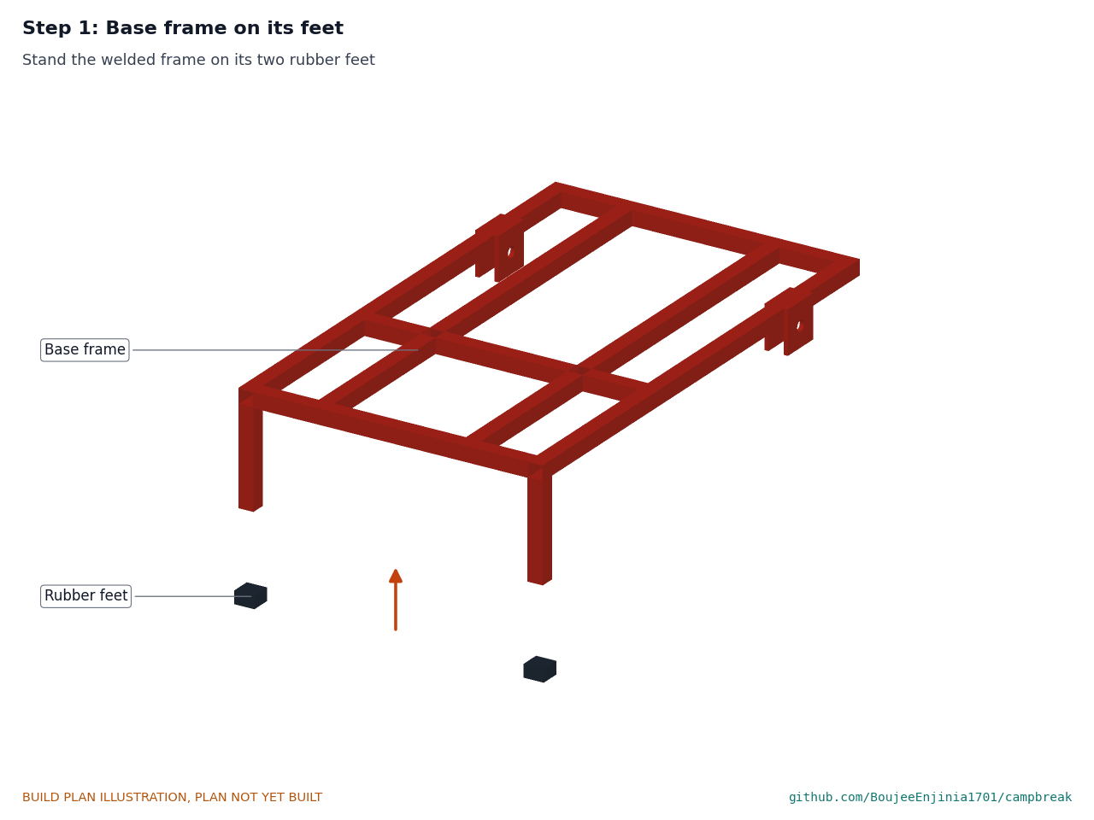
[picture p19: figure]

Push the rubber feet onto the legs (a dab of contact adhesive) and stand the frame on them.

Step 2: Handle

Weld the handle on as in section 3.2 and fit the grips.

Step 3: Pump stand

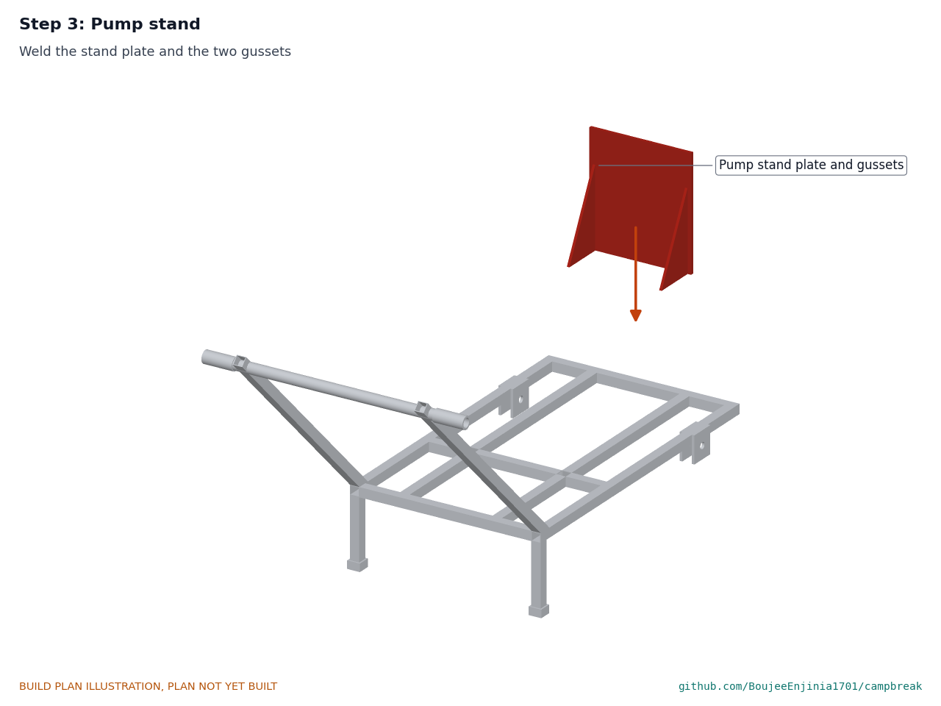
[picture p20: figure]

Weld the stand plate and gussets as in section 3.3.

Step 4: Reel uprights

Weld the two uprights to the rear bearers as in section 3.4. Prime and paint the frame now, before anything is bolted on; mask the axle plate holes and the stand plate's back face.

Step 5: Axle and wheels

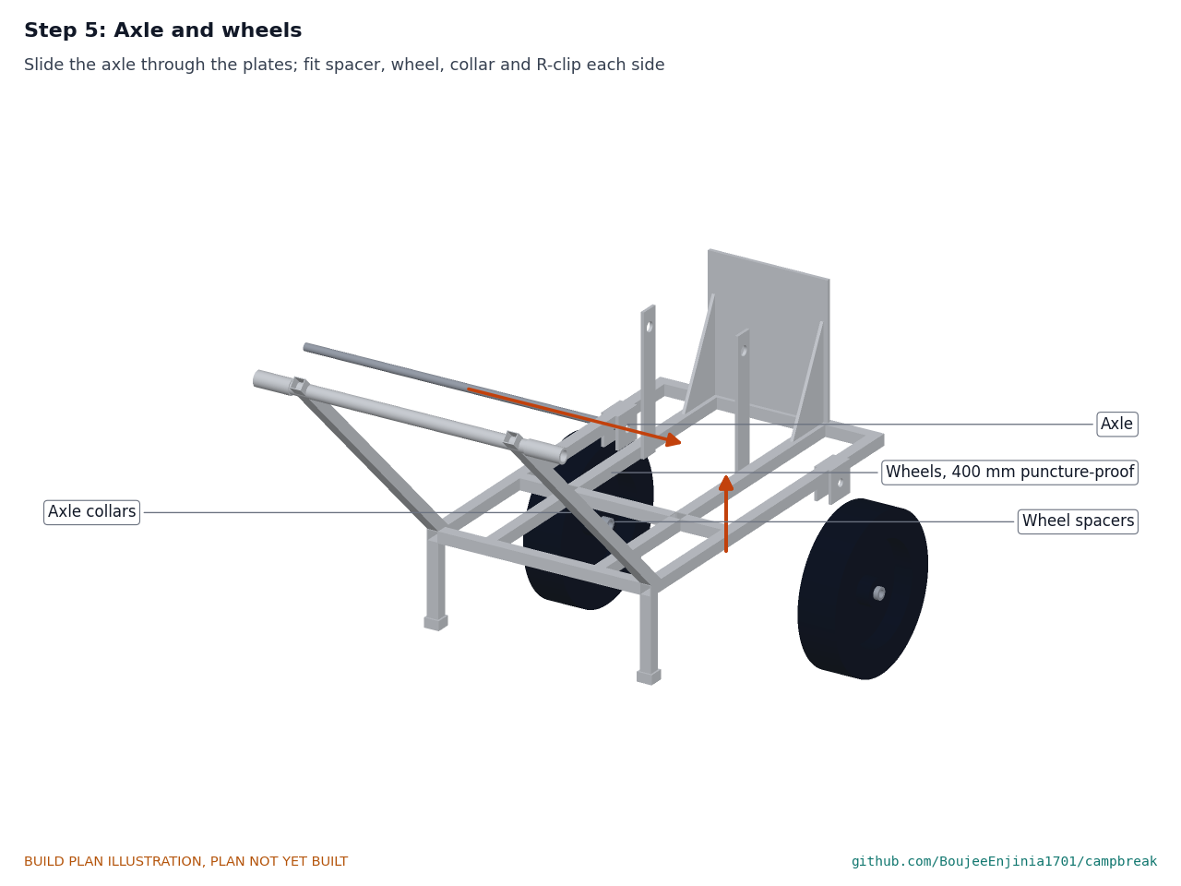
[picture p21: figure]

Grease the axle. Slide it through all four axle plates. On each side fit a spacer, the wheel, a collar (set screw tightened) and an R-clip.
Hold point: the cart rolls straight and both wheels spin freely.

Step 6: Hand pump

Two people lift the pump (about 14 kg) onto the back of the stand plate and fit four M12 x 40 bolts with washers both sides. Fit the 25 mm cam-lever coupler to the inlet, pointing down.

Step 7: Relief valve

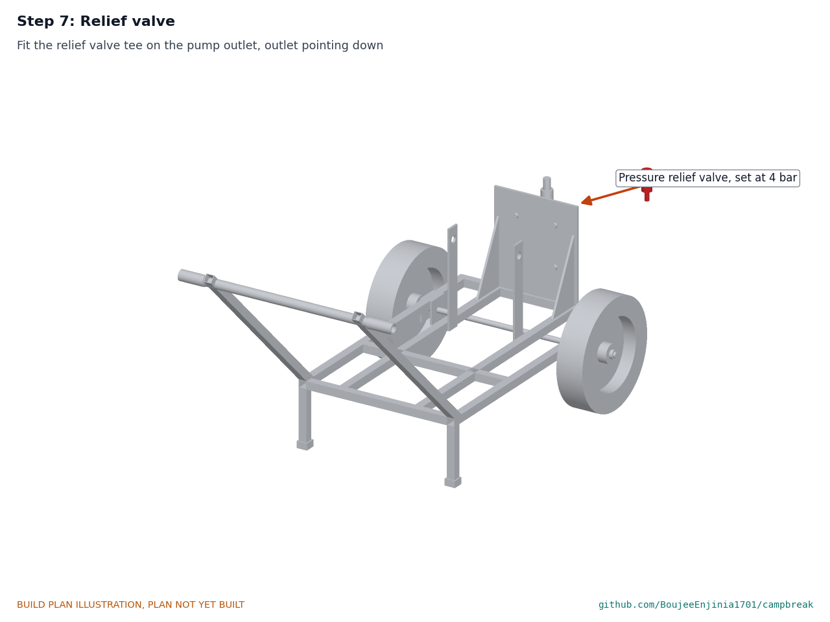
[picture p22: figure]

Fit the tee and relief valve to the pump outlet with thread sealant, discharge pointing straight down.

Step 8: Lever extension

Clamp the lever hub on the pump's handle socket with the lever upright at mid-stroke and tighten both clamp bolts. Hold point: swing the lever 40° each way: the grip clears the wheels by at least 50 and the frame by at least 30.

Step 9: Hose reel

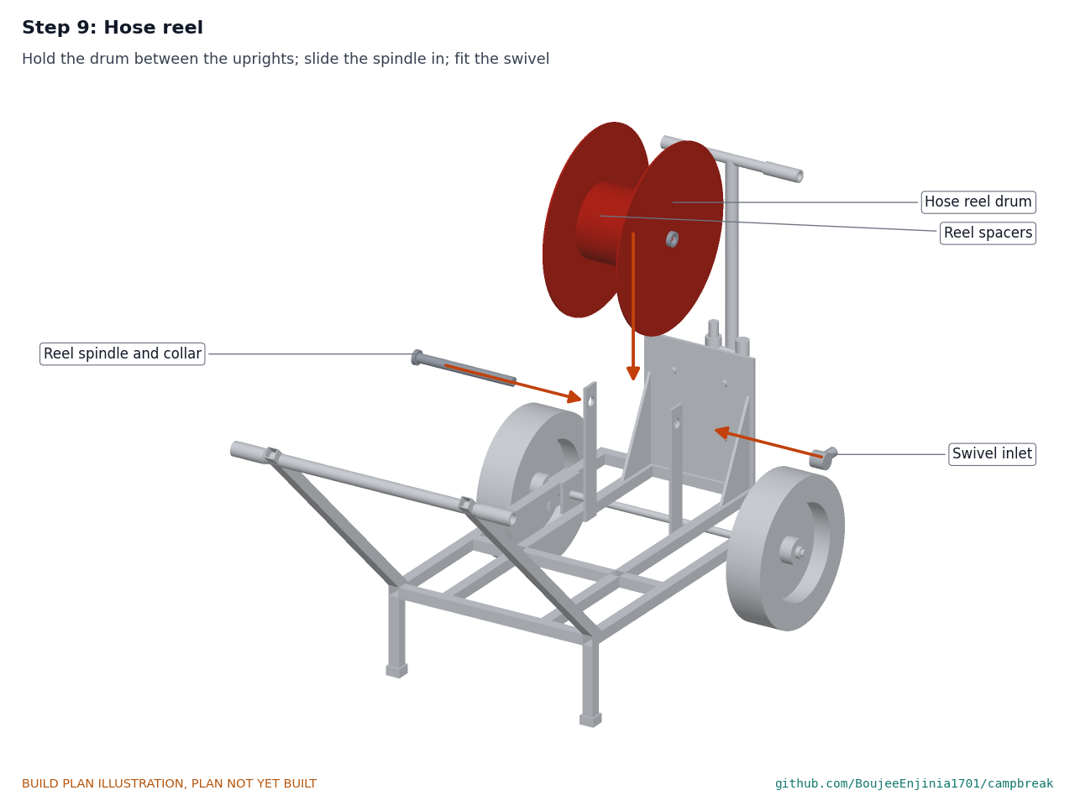
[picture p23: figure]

Hold the drum between the uprights with a spacer each side. Slide the spindle in from the left, fit the collar outside the left upright, and fit the swivel inlet on the right-hand end.

Step 10: Hoses

Fit the connecting hose from the pump outlet tail over to the swivel tail, with a clip at each end. Fit the 30 m hose to the drum's outlet and wind it on in neat even layers; it fills the drum, so a loose wind will not fit. Fit the nozzle to the free end.

Step 11: Hose tray

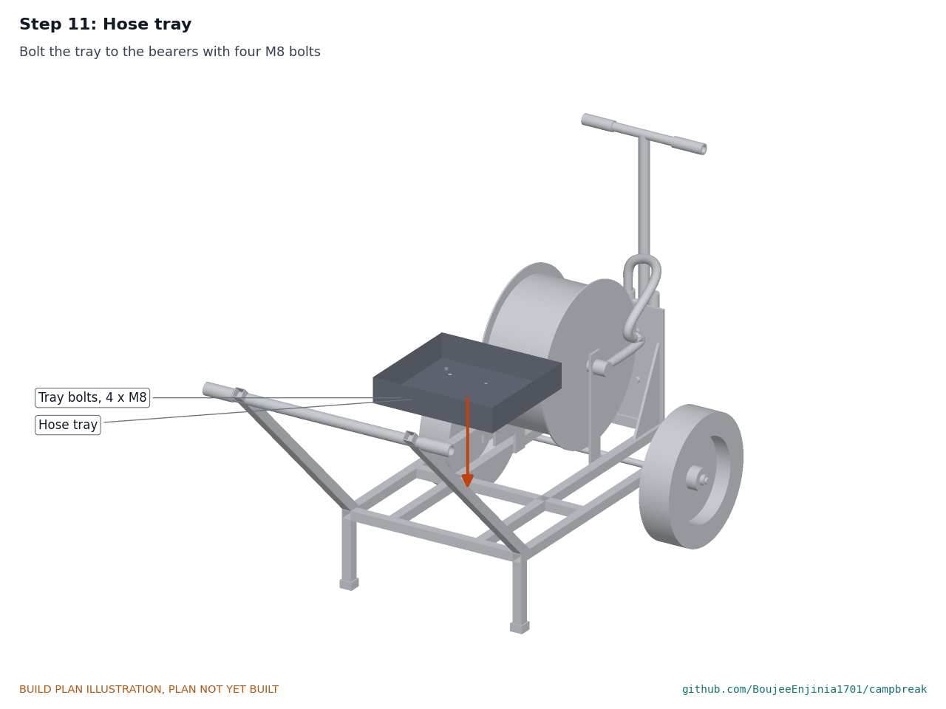
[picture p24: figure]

Bolt the tray to the bearers with four M8 bolts, washers and nyloc nuts.

Step 12: Suction kit

Fit the foot valve to one end of the suction hose and the cam-lever adaptor with its elbow to the other. Push the adaptor into the coupler under the pump and close both cam levers; it stays coupled from now on. Lead the hose to the left, up behind the end of the left rail and forward along the rail top, and fasten it with the two rubber straps. Coil the rest in the tray with the foot valve on top, and lay the tap adaptor inside the coil. Stow the nozzle in the tray when the hose is wound. Fit the reflective tape and the pump instruction label.
Prime it once. Stand the foot valve in a bucket of water and pump until water comes out of the nozzle, then lift the foot valve out. From now on the check in the foot valve keeps the pump and the suction hose full (see the weekly check on the drill card, section 5a).
Fill the delivery hose. With the foot valve still in the bucket, run out the 30 m hose, open the nozzle and pump until water runs steadily from it, then close the nozzle shut-off and wind the full hose back onto the reel. The shut-off holds the water in; the 4 bar relief valve protects the full hose if the sun heats it. Top the bucket up if it runs low. A full hose is heavy to wind (about 8.9 kg of water), so wind it with two people.

Step 13: Posts in their collars

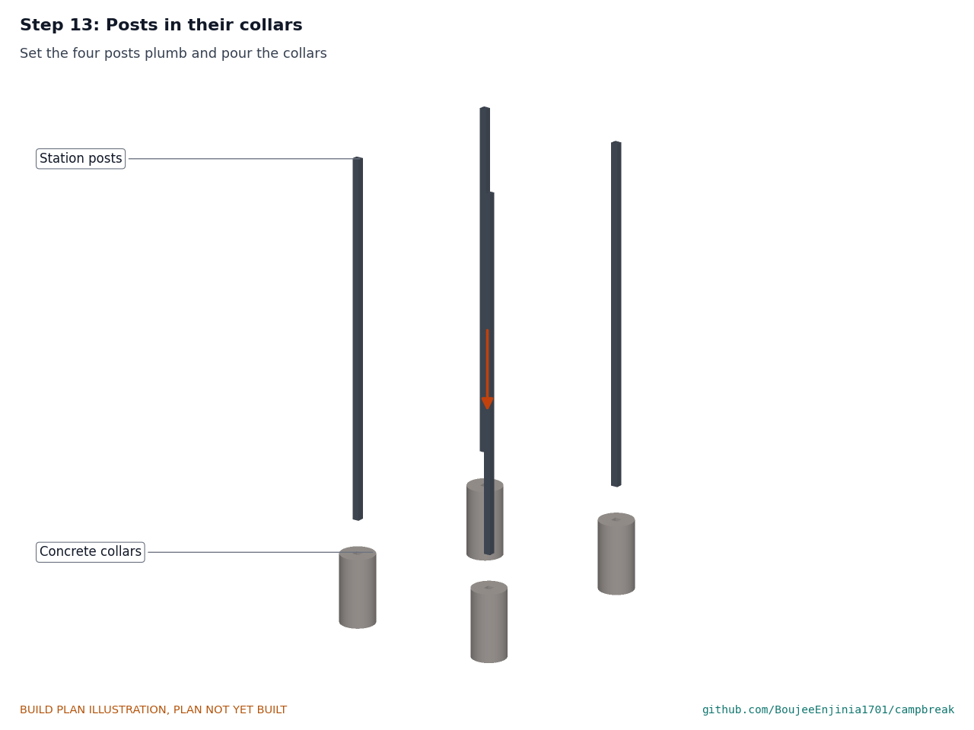
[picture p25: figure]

Set the posts and pour the collars as in section 3.10.

Step 14: Roof beams

Fix the beams to the post tops as in section 3.11.
Hold point: posts plumb and braced; concrete at least three days old.

Step 15: Purlins and roof sheet

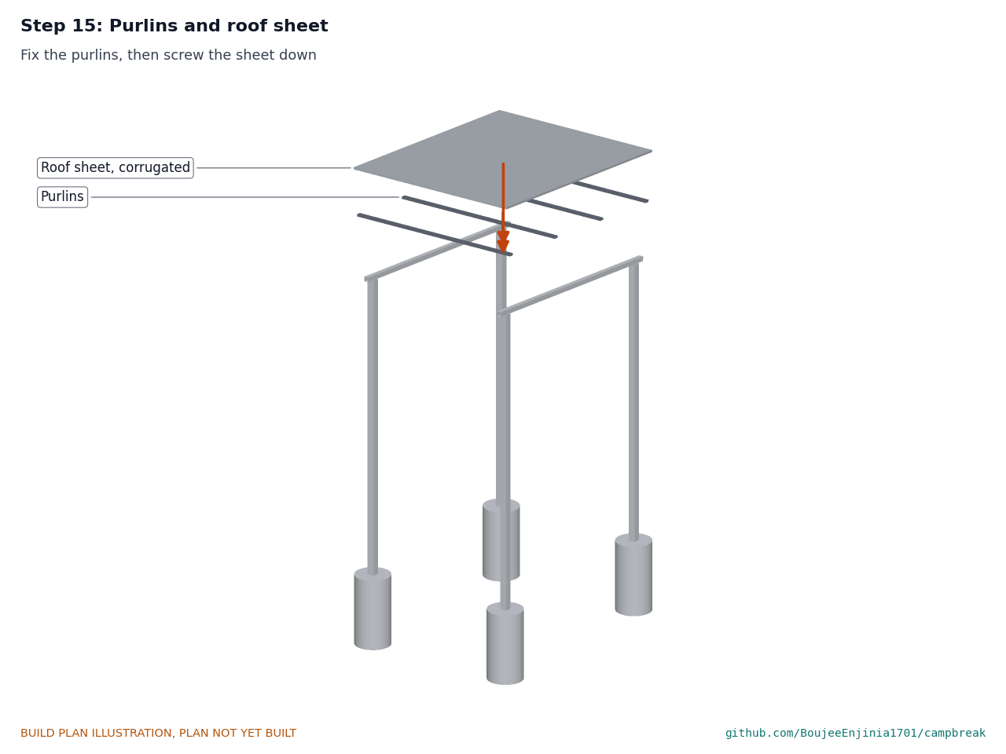
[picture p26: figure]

Fix the purlins, then screw the sheet down.

Step 16: Station alarm box, siren and solar panel

U-bolt the box to the back left post and bolt the siren bracket above it. Screw the panel rails to the sheet and bolt the panel on. Run the cables through glands into the box. Wire the panel to the charge controller and the siren to the relay output; connect the battery last, through its fuse.

Step 17: Sign, drum and cart


Bolt the sign to the back right post. Stand the drum beside the station and fill it. Push the cart in under the roof, handle to the front.

Step 18: Plate on the box base

Screw the mounting plate to the alarm box base with two M4 screws from inside.

Step 19: Battery holder and board


Fit the battery holder, the standoffs and the board with its sounder. Leave the cells out.

Step 20: Cover, thermistor and guard

Lead the thermistor out through the cover hole, close the cover and glue the guard on.

Step 21: Hang it under a roof pole


Put the cells in, close the box, and hang it under a roof pole about 300 from the ridge with two UV-stable ties through the plate slots, pulled tight under the plate.

### 5. First checks

These are listed here and recorded at TRL 4 in a test report. Table 2. First checks.

Check | Requirement How | Pass when
Cart width | R6 | Tape across the tyres | 900 mm or less
Pulling | R6 | Two adults pull the loaded cart (delivery hose full) 100 m up a 10 % unpaved slope; note the effort | 3 min or less; effort per person against the 100 N assumed (about 101 N expected)
Flow | R7 | Pump from a drum into a measured container for 1 min, then for 10 min | At least 20 L/min, kept up for 10 min
Relief valve | R7, safety | Shut the nozzle and pump slowly; watch a gauge on the tee | Valve opens at 4 bar ± 0.5; nothing leaks
Jet reach | R8 | Measure where the jet lands on level ground at 30° | 6 m or more
Alarm trigger | R1 | Warm the bead with a hot-air gun through a ramp logged by a reference thermometer | Sounds at 8 °C per minute or faster, and at 57 °C
Alarm sound | R3 | Sound meter at 3 m | 85 dB(A) or more
Relay | R4 | Trigger one alarm in a mock block | Station siren and every alarm within 10 s
Cooking | R2 | One hour of stove cooking 1 m from an alarm in a mock shelter | No alarm
Pump stays primed | R9 | Leave the primed cart a week, drop the foot valve in a drum and pump | The lever takes load within 3 strokes; water at the nozzle in about 30 s; no drip from the foot valve
Hose stays full | R9 | Leave the cart with the delivery hose full and the nozzle shut for a week, then open the nozzle | Water leaves the nozzle at once with no air; no drip at the nozzle or swivel
Drill | R9 | Timed drill from the siren to water on target at 70 m and 100 m, using the drill card | 3 min or less at both distances (2.95 min and 2.5 min expected)

### 5a. Drill card

The drill card is printed in the camp languages, laminated and kept in the station box; the station sign carries the first line. Volunteers practise it until the first two are away with the cart within 30 s of the siren.
Table 3. Drill card.

When | What to do
Siren sounds | Everyone in the burning shelter and its neighbours gets out first. Volunteers go to the station
At the station | Go when two arrive. The first two volunteers take the cart out at once; do not wait for more. Never more than 30 s from the siren. Two people always move the cart; never run with it
Others | Follow to the fire; take over the second side of the pump lever when you arrive
At the fire | Park the cart on its feet, upwind, at least 6 m from the fire. Person 1: lift the suction hose off the rail, drop the foot valve in the drum or water, and start pumping; it is already coupled and primed. Person 2: run out the hose from the reel and aim at the base of the fire. The hose is already full, so water leaves the nozzle as soon as the first strokes lift water
Never | Water on burning oil or live wiring. Go into a burning shelter
Every week | Prime check: drop the foot valve in the station drum and pump. The lever should take load within three strokes and water reach the nozzle in about 30 s. If not, re-prime (Step 12) and report the foot valve. Then check that the delivery hose is still full: open the nozzle for a moment; if air comes out, pump until water runs, shut the nozzle and wind the hose back

### 6. Safety stops

Work stops at each point below until what is listed is true.
Before welding: screen, gloves and mask on; fire extinguisher and a fire watch in place; no fuel, tarpaulin or shelters within 10 m.
Before the first pumping: the relief valve is fitted with its discharge pointing down; every hose clip and coupling is tight; the hose shows no cuts or kinks; nobody stands in front of the nozzle.
Before pumping against a shut nozzle (relief check): a pressure gauge is fitted on the tee, and the person pumping goes slowly and stops at 4.5 bar if the valve has not opened.
Before moving the loaded cart on a slope: two people on the handle, a third holding back on slopes steeper than 10 %; nobody in front of the cart downhill.
Before putting up the roof: posts braced and the concrete at least three days old; two people on stepladders; no work in wind.
Before connecting the station battery: the fuse is out, all wiring is finished and checked, and the box can be locked.
Before any drill with fire: the fire service or the camp's fire safety focal point is present, the fire is a small controlled test fire in a cleared area, and everyone knows that people leave first and water is never used on burning oil or live wiring.
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

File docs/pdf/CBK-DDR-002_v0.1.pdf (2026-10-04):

C A M P B R E A K · D E S I G N D E C I S I O N R E C O R D

# CampBreak design for construction

### Design Molecule Lab · designmolecule.com

D O C U M E N T CO N T RO L

Document ID | CBK-DDR-002 | Version | 0.1
Status | Draft | Date | 2026-10-03
Author | Amish Chadha | License | CERN-OHL-S-2.0
Project TRL | TRL 3 | Proof of concept
Repository | github.com/BoujeeEnjinia1701/campbreak
Source | docs/decisions/0002-design-for-construction.md @ uncommitted

R EV I S I O N H I STO RY

Version | Date | Author | Change
0.1 | 2026-10-03 | Amish Chadha | Changes that make the concept buildable, decided under Amish's 2026-10-03 pre-approval

D R A F T · N O T F O R F A B R I C A T I O N
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

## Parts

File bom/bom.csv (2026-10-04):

item | qty | spec | supplier | unit_cost_usd | make_buy | notes
1 Heat alarm complete | 24 | Rate-of-rise heat alarm: alarm board with a low-power controller and a sub-GHz radio module (USD 9.00), 10 kOhm NTC thermistor on a 40 mm lead and parts (USD 0.80), piezo sounder at least 95 dB(A) at 1 m (USD 1.20), stock two-part ABS box 100 x 100 x 40 mm (USD 2.50), 3 x AA holder with 3 alkaline AA cells (USD 2.00), 140 x 50 x 3 mm aluminium mounting plate, two M4 screws, printed sensor guard and two UV-stable cable ties (USD 2.00) | Electronics distributor (board parts); local market (box and cells) | 17.50 | buy | One alarm per shelter in a 24-shelter drill block; board design and firmware are TRL 4 work (CBK-DDR-001 D3)
2 Station alarm box with siren and solar panel | 1 | IP65 enclosure 300 x 300 x 150 mm holding a receiver board (the alarm board with a relay output), PWM solar charge controller, 12 V 7 Ah sealed lead-acid battery; 12 V siren at least 110 dB(A) at 1 m on a bolted bracket; 10 W 12 V solar panel 350 x 290 mm on two rails on the roof; cable and glands | Electronics distributor; solar and battery shop | 105.00 | buy | No lithium cells at the station (CBK-DDR-001 D6)
3 Station shade frame and roof | 1 | Four posts 60 x 60 x 3 mm square tube 3.2 m long cut to length (back posts 3.0 m, front posts 3.16 m, top cut at 5 degrees), 600 mm in the ground in 300 mm concrete collars (4 bags of concrete); two roof beams 40 x 40 x 2 mm, 2,000 mm; four purlins 40 x 20 x 2 mm, 1,500 mm; corrugated galvanised roof sheet 1,500 x 2,050 mm; S235 steel; about 87 kg of steel | Local steel stockist; building supplies | 157.00 | make | Four posts in place of a two-post cantilever (CBK-DDR-002 P9); CBK-CAL-001 section F
4 Station sign board | 1 | Aluminium sheet 440 x 300 x 3 mm with printed instructions in the camp languages and pictograms, including go when two arrive, two M8 bolts through the post | Local sign maker | 20.00 | make | Sign text is set with the co-design partner
5 Water drum 200 L | 1 | HDPE drum about 585 mm diameter x 880 mm with lid, food-grade | Local market | 35.00 | buy | One drum is about 10 minutes of pumping at 20 L/min (CBK-CAL-001)
6 Cart frame welded | 1 | 30 x 30 x 2 mm square tube (about 7.6 m): two side rails 1,000 mm, three cross members, four bearer pieces, two legs, two handle arms coped to a 33.7 x 2.6 mm cross bar 820 mm; four 80 x 85 x 8 mm axle plates with 21 mm holes; 320 x 355 x 10 mm pump stand plate with two 8 mm gussets; two 50 x 8 mm reel uprights 365 mm with 26 mm holes; S235; about 30 kg; welding consumables; four rubber handle grips | Local steel stockist; camp or market workshop | 59.00 | make | CBK-DDR-002; mass from the model (CBK-CAL-001 section E)
7 Wheels axle spacers and collars | 1 | Two 400 mm puncture-proof wheelbarrow wheels, 100 mm wide, with 20 mm bore ball-bearing hubs 75 mm long; 20 mm bright steel axle 850 mm with R-clip holes; two spacer tubes 32 x 22 mm; two collars with set screws | Hardware store | 69.00 | buy | Wheels USD 28.00 each
8 Hand pump semi-rotary 25 mm ports | 1 | Double-acting semi-rotary (wing) hand pump, cast iron, 25 mm (1 in) suction and delivery ports, at least 0.40 L per double stroke, rated for at least 40 m head; flange with four M12 holes on a 150 mm square; about 14 kg | Pump or agricultural supply shop | 120.00 | buy | Displacement and port positions to confirm when bought (CBK-DEC-001)
9 Lever extension with T-grip | 1 | Clamp hub on the pump handle socket, 33.7 x 2.6 mm tube 585 mm, 27 x 2.3 mm T-bar 400 mm, two rubber grips | Local steel stockist; camp workshop | 12.00 | make | Grip 610 mm from the pump shaft
10 Hose reel drum spindle and swivel inlet | 1 | Steel hose reel drum 200 mm core, two 500 mm flanges 210 mm apart; 25 mm spindle 300 mm; two spacer tubes 40 x 26 mm 12 mm long; collar; 19 mm (3/4 in) swivel inlet with a hose tail | Fire equipment or hardware supplier | 95.00 | buy | Drum only; no reel certification is claimed
11 Delivery hose 19 mm x 30 m and connecting hose | 1 | 30 m of 19 mm bore semi-rigid hose, rated at least 10 bar working; 1.2 m of 19 mm reinforced hose from the pump outlet to the reel swivel with two hose clips | Fire equipment supplier | 83.00 | buy | Hose USD 75.00; connecting hose USD 8.00; stowed full of water (8.9 kg | no cost; CBK-DDR-004)
12 Nozzle jet and spray with shut-off | 1 | Hand nozzle for 19 mm hose, 6 mm jet orifice, jet and spray settings and shut-off | Fire equipment supplier | 25.00 | buy | Orifice to confirm when bought
13 Suction hose 25 mm x 4 m with check foot valve | 1 | Wire-reinforced PVC suction hose 25 mm bore, 4 m, bend radius 75 mm or less; cam-lever adaptor end (line 14); brass spring-loaded foot valve with a positive-seal check and a stainless strainer, 25 mm (1 in), at the other end. The check holds the hose and pump full of water between uses so the pump stays primed | Pump or agricultural supply shop | 40.00 | buy | CBK-DDR-003. Price basis: hose USD 22.00 as before; brass 1 in spring check foot valve about USD 18.00 at pump and agricultural supply shops, replacing the plain foot valve strainer priced at USD 6.00 (+USD 12.00)
14 Quick couplings 25 mm | 3 | Cam-lever quick coupling sets, 25 mm: pump inlet coupler (type D), with the suction hose's adaptor and a 90 degree elbow hose tail (type E with elbow) left coupled to it when the cart is stowed; tap adaptor end | Pump or agricultural supply shop | 9.00 | buy | Suction hose stowed coupled to the pump (CBK-DDR-003); the elbow tail is priced within the set
15 Tap adaptor | 1 | Universal push-on tap connector to a 25 mm hose tail with clip | Hardware store | 12.00 | buy
16 Hose tray | 1 | Galvanised steel sheet 1.5 mm, blank 560 x 530 mm, folded to 400 x 370 x 80 mm with six 12 mm drain holes; four 12 mm holes for the tray bolts | Local sheet metal shop | 15.00 | make
17 Fasteners | 1 | Four M12 x 40 bolts with nuts and washers (pump); four M8 bolts (tray); two R-clips; two rubber feet 40 x 40 x 25 mm; M8 and U-bolts for the station box, siren bracket, sign and panel rails; stainless where outdoors | Hardware store | 30.00 | buy
18 Paint reflective tape labels and drill card | 1 | Primer and red enamel for the cart frame; white reflective tape; hazard and pump-instruction labels; laminated A5 drill card with the go-when-two-arrive rule and the weekly prime check, kept in the station box | Hardware store | 27.00 | buy | Price basis: drill card printing and lamination about USD 2.00 at a local print shop (+USD 2.00; CBK-DDR-003)
19 Pressure relief valve 4 bar | 1 | 19 mm (3/4 in) spring relief valve set at 4 bar, on a tee in the pump outlet, discharge pointing down | Plumbing or pump supplier | 18.00 | buy | Limits hose and pump pressure when the nozzle is shut (CBK-DDR-001 D7)
20 Suction hose straps | 2 | Rubber hold-down strap, 20 mm wide, with a buckle, round the left rail and the suction hose lying on it, 300 mm apart | Hardware store | 2.50 | buy | CBK-DDR-003. Price basis: rubber tie-down or hose strap about USD 2.00 to 3.00 each at hardware stores

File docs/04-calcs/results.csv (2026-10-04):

id | requirement | target | result | status
R1 | Rate-of-rise threshold | 8 C/min | 8 C/min over 60 s, plus 57 C fixed | Met by design (firmware threshold)
R2 | No alarm in 1 h of cooking at 1 m | No alarm | Not calculable on paper | To show at TRL 4
R3 | Sound at 3 m | >= 85 dB(A) | 85.5 dB(A) | Met (est.)
R4 | Relay to station and all alarms | <= 10 s | 7.2 s worst case | Met (est.)
R5 | Battery life | >= 12 months | 331 months; shelf life of the cells limits it to about 5 years | Met (est.)
R6 | Cart on a 10 % slope, 100 m | <= 3 min, width <= 0.9 m | 1.7 min at 1.0 m/s; 101 N per person; width 850 mm | Met (est.)
R7 | Flow for 10 min | >= 20 L/min | 20.4 L/min; 47 W per person | Met (est.)
R8 | Jet reach | >= 6 m | 6.9 m | Met (est.)
R9 | Water on target 100 m away | <= 3 min | 2.95 min (177 s) at 100 m; 2.5 min at 70 m (siting margin) | Met (est.)
R10 | Repairable locally | Hand tools, market parts | Every wear part is a market item | Met by design
R11 | Value-engineering target | USD 1,600 | USD 1,374 | USD 226 under the target

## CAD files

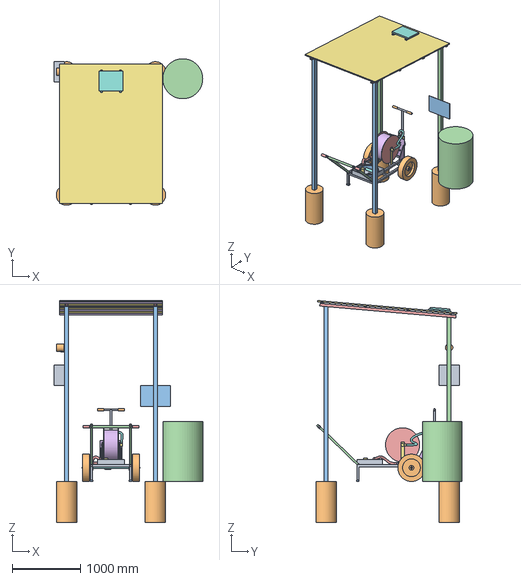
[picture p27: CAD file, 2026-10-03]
cad/step/campbreak-assembly.step
2172.5 x 2142.3 x 3246.8 mm

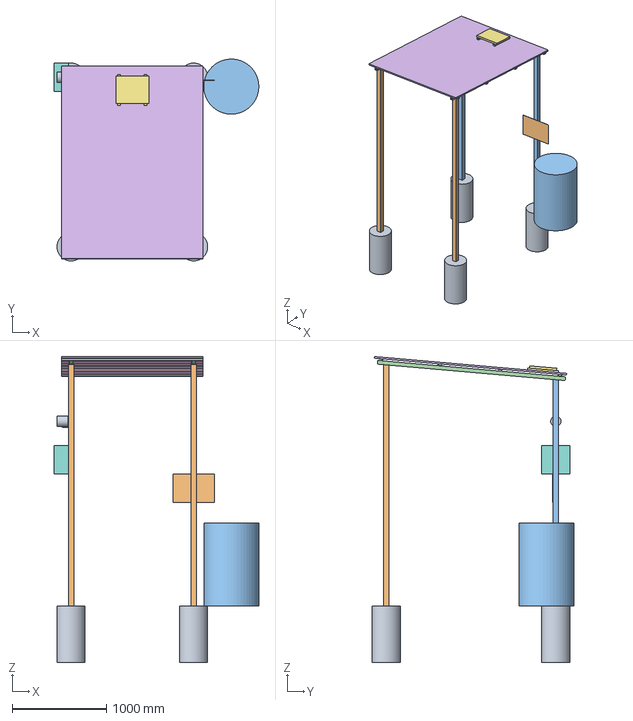
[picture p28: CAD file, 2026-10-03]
cad/step/campbreak-station.step
2172.5 x 2142.3 x 3246.8 mm

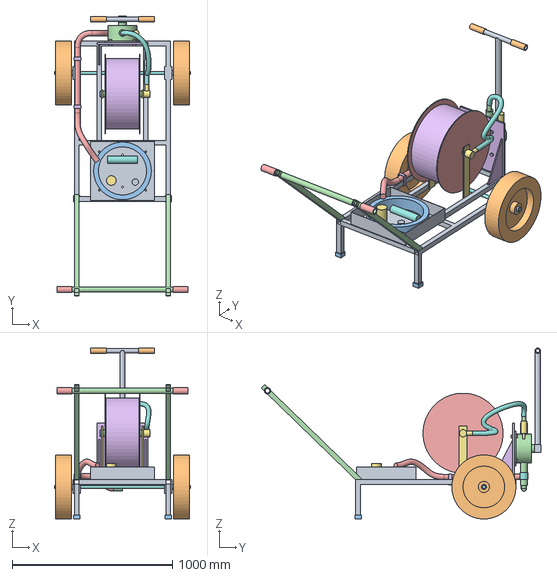
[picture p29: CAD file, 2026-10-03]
cad/step/campbreak-cart.step
850.0 x 1744.2 x 1067.0 mm

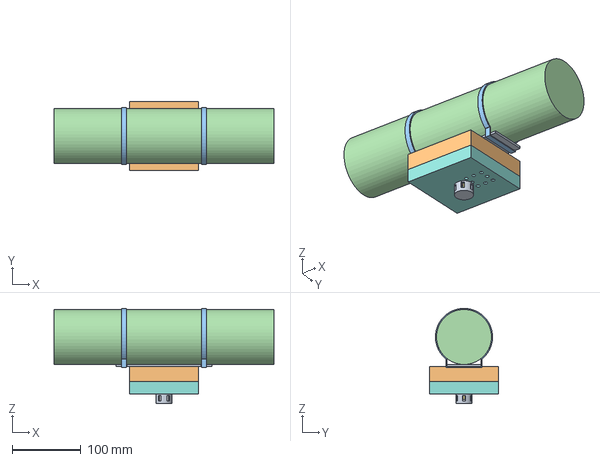
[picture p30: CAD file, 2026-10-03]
cad/step/campbreak-alarm.step
320.0 x 100.0 x 138.6 mm

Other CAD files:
cad/stl/campbreak-alarm.stl
cad/stl/campbreak-assembly.stl
cad/stl/campbreak-cart.stl
cad/stl/campbreak-station.stl

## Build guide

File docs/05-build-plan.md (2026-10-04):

---
doc_id: CBK-BLD-001
title: CampBreak prototype build plan
project: CampBreak
doc_type: Build plan
version: "0.3"
status: Draft
date: '2026-10-03'
author: Amish Chadha
license: CERN-OHL-S-2.0
revisions:
  - version: "0.1"
    date: '2026-10-03'
    author: Amish Chadha
    change: First build plan; design made constructable (CBK-DDR-002)
  - version: "0.2"
    date: '2026-10-03'
    author: Amish Chadha
    change: "Amish's R9 decision 1A (CBK-DDR-003): check foot valve, suction hose left coupled to the pump and strapped to the rail, go-when-two-arrive drill card"
  - version: "0.3"
    date: '2026-10-03'
    author: Amish Chadha
    change: "Amish's round-2 decision 1A (CBK-DDR-004): delivery hose stowed full of water, filled at Step 12 and topped up at the weekly check; cart weight and pull updated"
---

# CampBreak prototype build plan

**Plan, not yet built.** How to build the first proof-of-concept prototype, component by component. Building and testing to it is TRL 4 work. Decisions are kept in the design decisions register ([docs/06-design-decisions.md](06-design-decisions.md)), not here.

## 1. What you are building

Figure 1. Every component, pulled apart and numbered in build order

*Figure 1. Every component pulled apart and numbered in build order: the hose cart (1 to 12), the block station (13 to 18) and one heat alarm (19, drawn five times its size).*

The prototype is one block kit: a two-wheeled hose cart with a hand pump, a shaded block station for the cart with a siren and a water drum, and a heat alarm of the kind hung in each shelter (a drill block has 24). Figure 1 shows the 19 component groups in the order you make or fit them. The made parts are the welded cart frame, handle, pump stand and reel uprights, the axle and spindle pieces, the lever extension, a folded sheet-steel hose tray, the four station posts with their roof frame, the sign and the alarm's mounting plate and drilled box. Everything else is bought and fitted: wheels, pump, relief valve, reel drum, hoses, nozzle, couplings, roof sheet, drum, the station's box, battery, siren and panel, and the alarm's board, cells and sounder. The work is sawing, drilling and MIG welding mild steel tube and plate, folding thin sheet, pouring four concrete collars, and drilling plastic boxes. The parts cost about USD 1,374 from the bill of materials.

> **Safety:** The finished cart is a pressurised water system: two people can push the pump to several bar against a shut nozzle, so the 4 bar relief valve must be fitted before the first pumping, discharge pointing at the ground. Welding needs a screen, gloves, a mask and a fire watch; grind and weld well away from fuel and shelters. The loaded cart weighs about 103 kg, with its pump, suction hose and delivery hose kept full of water: two people lift and move it. The station roof is put up from a stepladder by two people, never in wind. The station battery is sealed lead-acid: connect its fuse last.

## 2. What changed to make it buildable

The concept showed what the kit does; its parts were blocks with no stock size and no fixings. Each change below keeps what the kit does, and all of them are recorded in decision record CBK-DDR-002.

*Table 1. Changes from the concept.*

| Component | The concept had | The buildable design has | Why |
| --- | --- | --- | --- |
| Cart frame | A solid platform | A welded frame of 30 mm square tube with two lines of bearers (Figure 2) | One tube size, square cuts, every joint a weld on a flat table |
| Wheels | Wheels on the frame sides, no axle mounting | A 20 mm through axle in four 8 mm axle plates, with spacers, collars and R-clips (Figure 15) | The axle runs in two plates each side and clears the tubes |
| Legs | None; the cart stood on its wheels only | Two short legs with rubber feet at the front | The cart parks level |
| Handle | A bar floating in front | Two arms sitting on the rail tops, coped to a cross bar (Figures 4 and 5) | A welded triangle at each foot |
| Pump mounting | Pump on the deck, no fixing | A 10 mm stand plate with two gussets; four M12 bolts (Figure 7) | Puts the shaft 440 mm up so the lever clears the wheels |
| Lever | The pump's own short handle | A clamp-on lever with a T-bar for two people (Figure 12) | About 28 N per person |
| Reel | A cylinder, no support | A bought drum on a 25 mm spindle in two welded uprights with a swivel inlet (Figure 9) | The hose pays out while the pump stays connected |
| Pump to reel | Nothing | A 1.2 m connecting hose and the 4 bar relief valve on a tee (Figure 16) | The relief water goes to the ground |
| Small parts | Loose | A folded tray bolted to the bearers (Figures 13 and 14) | Everything travels on the cart and drains |
| Station | Two posts holding a cantilever roof | Four posts in concrete collars, two beams, four purlins and a sheet (Figures 18 to 21) | Resists monsoon uplift with plain bolts and welds |
| Suction hose | Coiled loose in the tray, coupled and primed at the fire | Left coupled to the pump inlet, strapped along the left rail, with a check foot valve that keeps the pump full (Figure 17; CBK-DDR-003) | Nothing to couple or prime at the fire: water about 30 s sooner |
| Heat alarm | A box glued to the roof | An aluminium plate on the box, hung on a roof pole by two ties (Figures 24 and 25) | Fits any bamboo pole; no screws into bamboo |

## 3. Making the components

Make and check each component before the assembly step that needs it. Sizes are in millimetres. "Front" is the pull handle end of the cart; "left" and "right" are as seen standing behind the handle, facing the cart. Workshop tolerance is 1 mm on the cart and 5 mm on the station unless a step says otherwise; drawings carry no tolerances before TRL 4.

### 3.1 Cart base frame

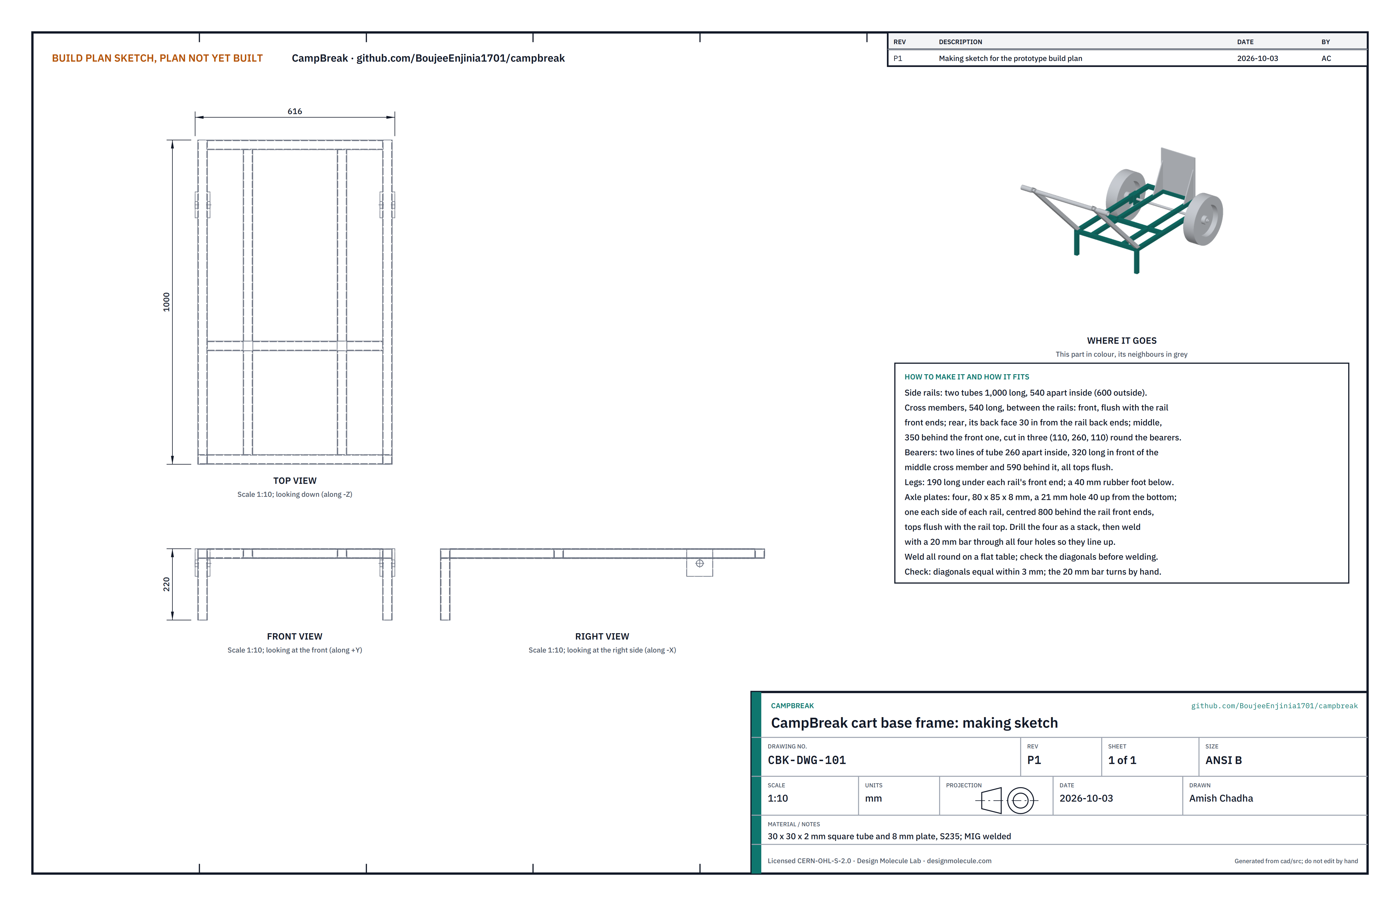
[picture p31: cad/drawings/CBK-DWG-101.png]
Figure 2. Making sketch of the cart base frame


*Figure 2. Cart base frame making sketch (CBK-DWG-101).*

**What it is and what it is made from.** The ladder frame everything on the cart hangs from. Mild steel square tube 30 x 30 x 2 mm (S235), about 7.6 m in all, and 8 mm flat plate for the four axle plates.

**How to make it.**

1. Cut two side rails 1,000 long, three cross members 540 long (cut the middle one later into pieces of 110, 260 and 110), two front bearers 320 long, two rear bearers 590 long and two legs 190 long. Square all ends and deburr.
2. Lay the side rails on a flat table, 540 apart inside. Weld the front cross member flush with the rail front ends and the rear one with its back face 30 in from the rail back ends. Check that the diagonals are equal within 3 mm, then weld.
3. Mark the middle cross member line 350 behind the front cross member. Fit its two 110 pieces from the rails inward and the 260 piece in the middle, leaving a 30 gap each side for the bearers.
4. Fit the bearers in those gaps, 260 apart inside: the front pair from the front cross member to the middle line, the rear pair from the middle line to the rear cross member. All tube tops flush. Weld.
5. Cut four axle plates 80 x 85 x 8. Clamp them as a stack and drill a 21 mm hole centred across the width, 40 up from the bottom edge.
6. Weld one plate on each side of each rail, centred 800 behind the rail front ends, tops flush with the rail top, with a 20 mm bar through all four holes so they line up. Remove the bar after cooling.
7. Weld a leg under each rail's front end, square to the rail.

**How it fits the parts next to it.** The handle arms sit on the rail tops at the front (Figure 4). The pump stand plate sits on the rear cross member and its gussets on the rear bearers (Figure 7). The reel uprights stand against the inner faces of the rear bearers (Figure 9). The axle runs through the four plates (Figure 15). The tray sits on the bearers and the front cross member (Figure 14).

**Check before moving on.** The frame sits flat on the table without rocking; the 20 mm bar turns by hand in all four plates at once.

### 3.2 Pull handle

Figure 3. Making sketch of the pull handle

*Figure 3. Pull handle making sketch (CBK-DWG-102).*

**What it is and what it is made from.** Two arms and a cross bar that two people pull side by side. 30 x 30 x 2 mm square tube for the arms; 33.7 x 2.6 mm round tube, 820 long, for the bar; two rubber grips.

**How to make it.**

1. Cut two arms about 820 long. Cut the foot end of each at 44° so it lies flat on the rail top with its toe touching the front cross member's end.
2. Cope the top end of each arm to fit round the 33.7 mm bar (a saddle cut with a hole saw or a grinder and a paper template).
3. Set the frame on the table, clamp the bar 800 above the floor and 550 in front of the rail front ends, centred, and tack the arms to the rails and the bar, 125 in from each bar end.
4. Check that the bar is level and square to the frame, then weld all round.
5. Push a grip onto each bar end with soapy water.

**How it fits the parts next to it.**

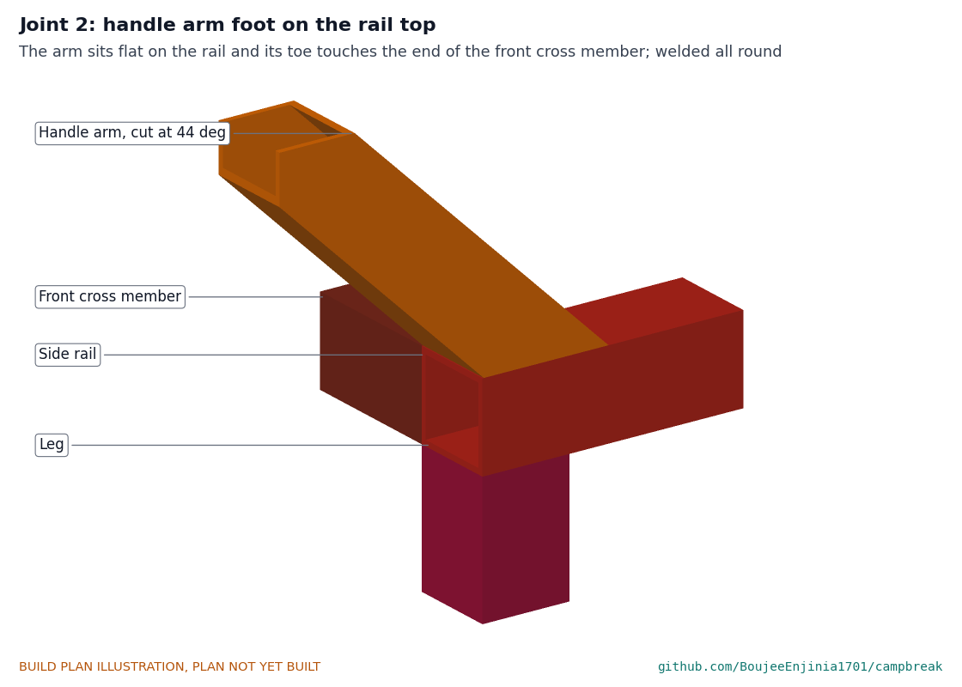
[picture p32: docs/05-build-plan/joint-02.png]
Figure 4. Joint 2: handle arm foot on the rail top


*Figure 4. The arm foot sits flat on the rail top and its toe touches the end of the front cross member; welded all round.*

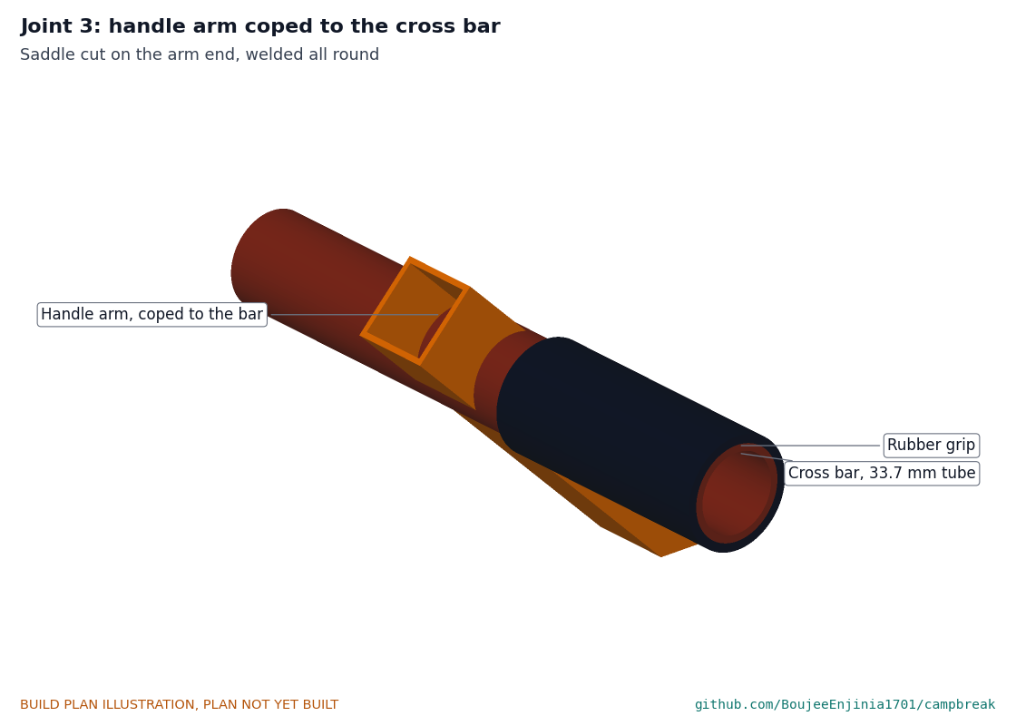
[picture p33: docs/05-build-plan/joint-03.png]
Figure 5. Joint 3: arm coped to the cross bar


*Figure 5. The saddle-cut arm end wraps the bar; welded all round.*

**Check before moving on.** The bar is level within 3 mm. Lift the frame by the bar: nothing flexes visibly.

### 3.3 Pump stand plate and gussets

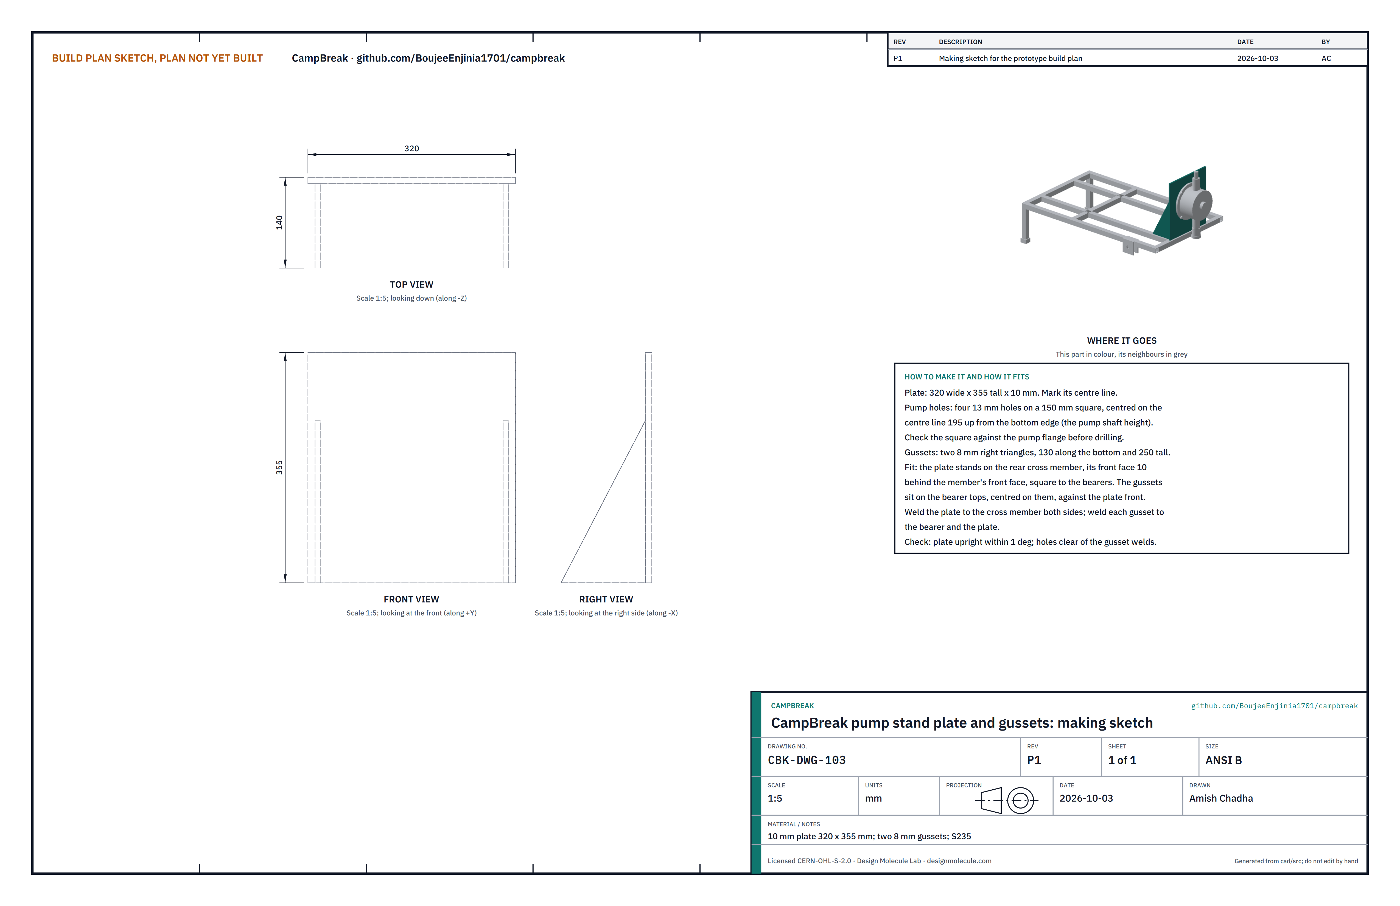
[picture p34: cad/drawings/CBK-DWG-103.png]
Figure 6. Making sketch of the pump stand


*Figure 6. Pump stand making sketch (CBK-DWG-103).*

**What it is and what it is made from.** An upright plate the pump bolts to, braced by two triangles. 10 mm plate 320 x 355; two 8 mm triangles 130 x 250.

**How to make it.**

1. Cut the plate 320 wide and 355 tall. Mark the centre line.
2. Lay the bought pump's flange on the plate, centred on the centre line with the shaft 195 up from the bottom edge, and mark its four holes (on a 150 mm square for the pump specified). Drill 13 mm.
3. Cut two right-angled triangles, 130 along the bottom and 250 tall.
4. Stand the plate on the rear cross member, its front face 10 behind the member's front face and square to the bearers. Weld it to the cross member on both sides.
5. Stand each gusset on a rear bearer, centred on it, against the plate's front face. Weld to the bearer and the plate.

**How it fits the parts next to it.**

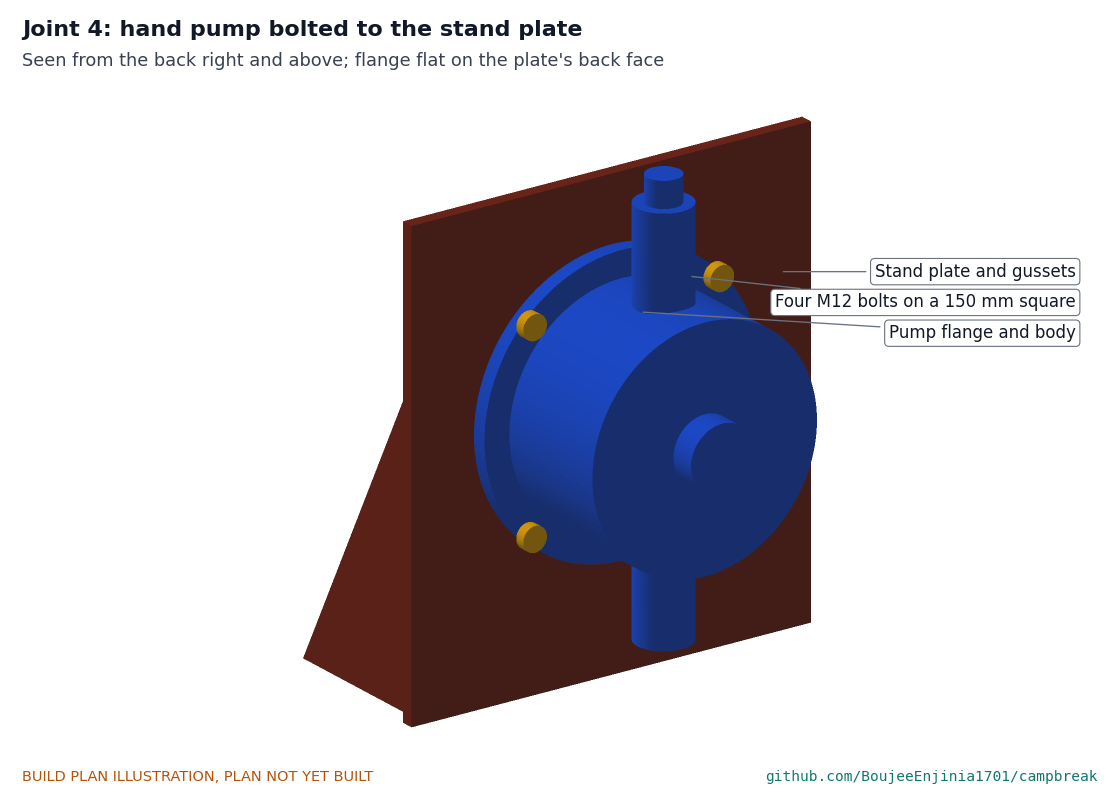
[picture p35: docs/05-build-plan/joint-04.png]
Figure 7. Joint 4: hand pump bolted to the stand plate


*Figure 7. The pump flange sits flat on the plate's back face; four M12 bolts with washers both sides.*

**Check before moving on.** The plate is upright within 1°; the pump's bolts pass through all four holes without forcing.

### 3.4 Reel uprights

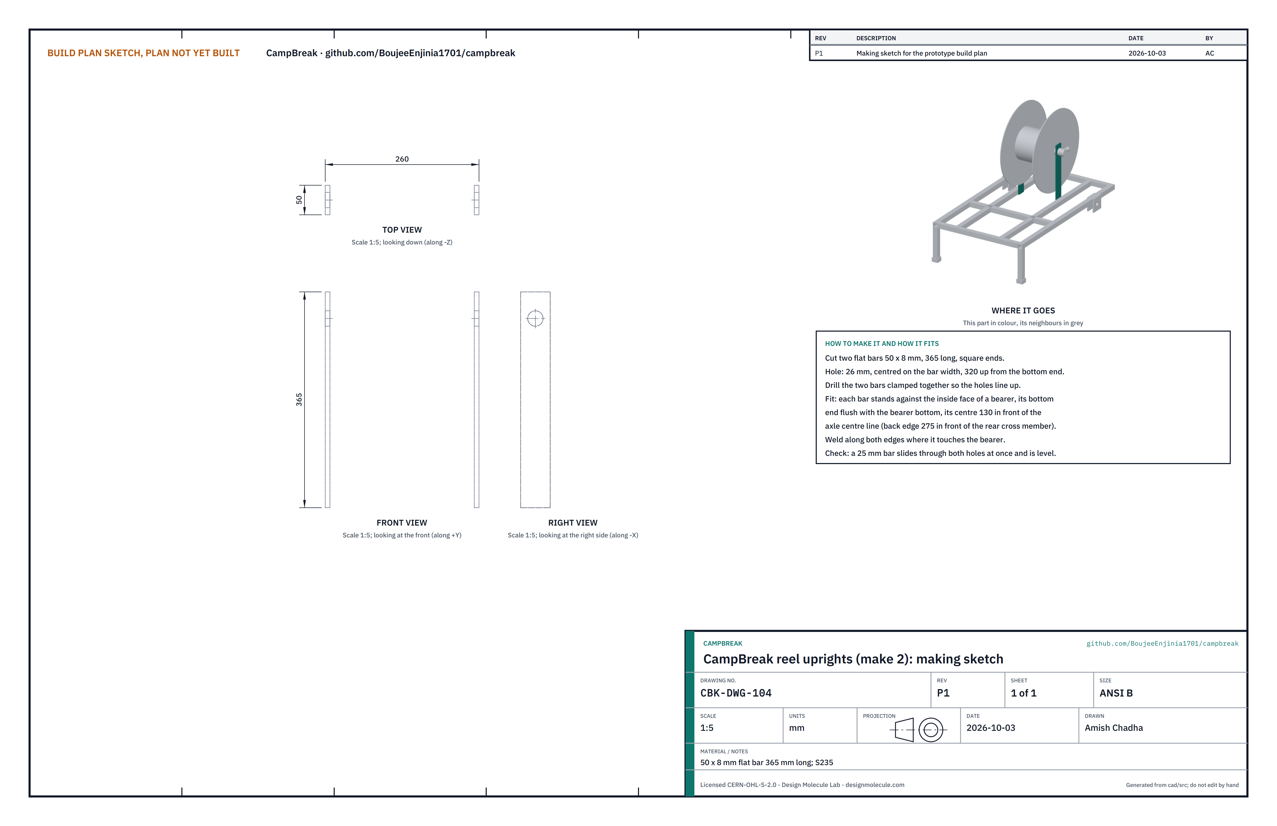
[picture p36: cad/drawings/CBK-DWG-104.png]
Figure 8. Making sketch of the reel uprights


*Figure 8. Reel upright making sketch (CBK-DWG-104).*

**What it is and what it is made from.** Two flat bars that carry the reel spindle. 50 x 8 mm flat bar, two pieces 365 long.

**How to make it.**

1. Cut both bars 365 long and clamp them together.
2. Drill a 26 mm hole through both, centred across the width, 320 up from the bottom end.
3. Stand each bar against the inside face of a rear bearer, bottom end flush with the bearer bottom, its centre 130 in front of the axle centre line. Pass a 25 mm bar through both holes to hold them in line, then weld along both edges.

**How it fits the parts next to it.**

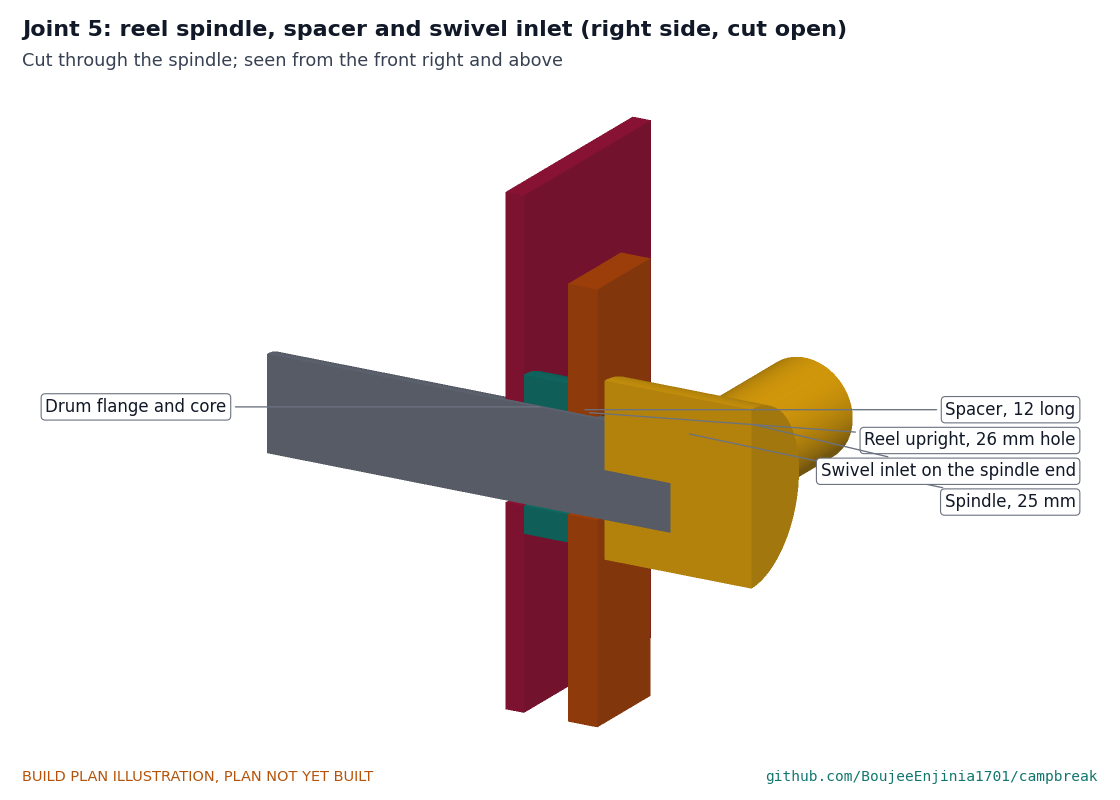
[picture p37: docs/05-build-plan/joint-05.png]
Figure 9. Joint 5: reel spindle, spacer and swivel (cut open)


*Figure 9. The spindle passes through the upright, a 12 mm spacer and the drum; the swivel inlet sits on the right-hand end.*

**Check before moving on.** The 25 mm bar slides through both holes at once and is level within 2 mm.

### 3.5 Axle, wheel spacers and collars

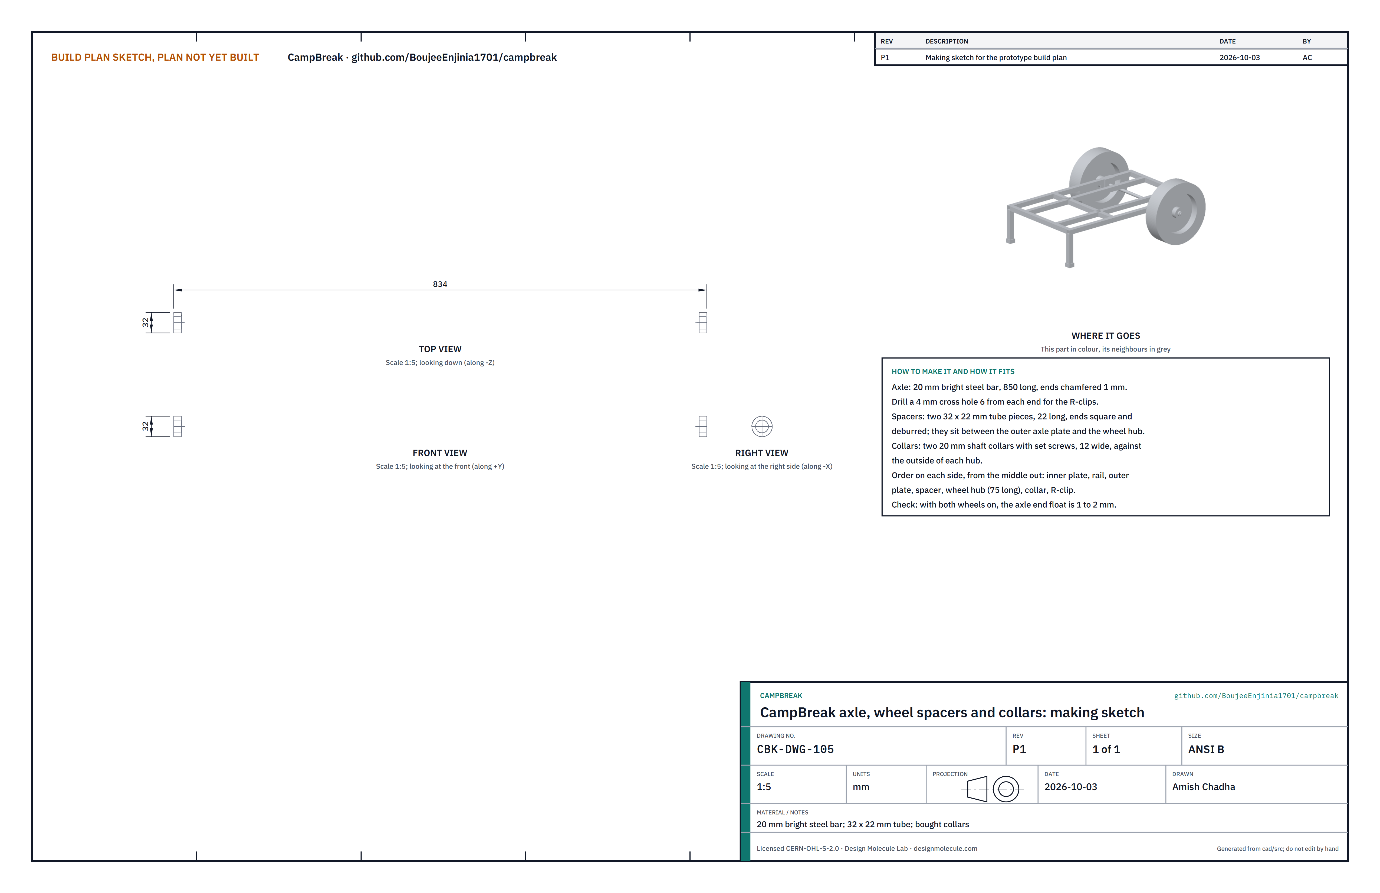
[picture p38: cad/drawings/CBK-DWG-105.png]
Figure 10. Making sketch of the axle and spacers


*Figure 10. Axle and spacers making sketch (CBK-DWG-105).*

**What it is and what it is made from.** A 20 mm bright steel bar 850 long, two spacers cut from 32 x 22 mm tube, two bought 20 mm collars and two R-clips.

**How to make it.**

1. Cut the axle 850 long; chamfer both ends 1 mm.
2. Drill a 4 mm cross hole 6 from each end for the R-clips.
3. Cut two spacers 22 long from the tube; square and deburr the ends.

**How it fits the parts next to it.** See Figure 15 in section 3.9. From the middle out on each side: inner axle plate, rail, outer axle plate, spacer, wheel hub, collar, R-clip.

**Check before moving on.** With both wheels on, the axle end float is 1 to 2 mm and the wheels spin freely.

### 3.6 Reel spindle and spacers

Figure 11. Making sketch of the reel spindle

*Figure 11. Reel spindle making sketch (CBK-DWG-106).*

**What it is and what it is made from.** A 25 mm bright steel bar 290 long, two spacers cut from 40 x 26 mm tube, one bought 25 mm collar.

**How to make it.**

1. Cut the spindle 290 long; chamfer both ends 1 mm.
2. Cut two spacers 12 long; deburr.
3. Check the reel drum's bore against the spindle; if the bore is larger, sleeve it (see the register, to confirm).

**How it fits the parts next to it.** Figure 9: left upright, spacer, drum, spacer, right upright, swivel. The collar sits against the outside of the left upright.

**Check before moving on.** The drum turns by hand with 1 to 2 mm of side float.

### 3.7 Lever extension with T-grip

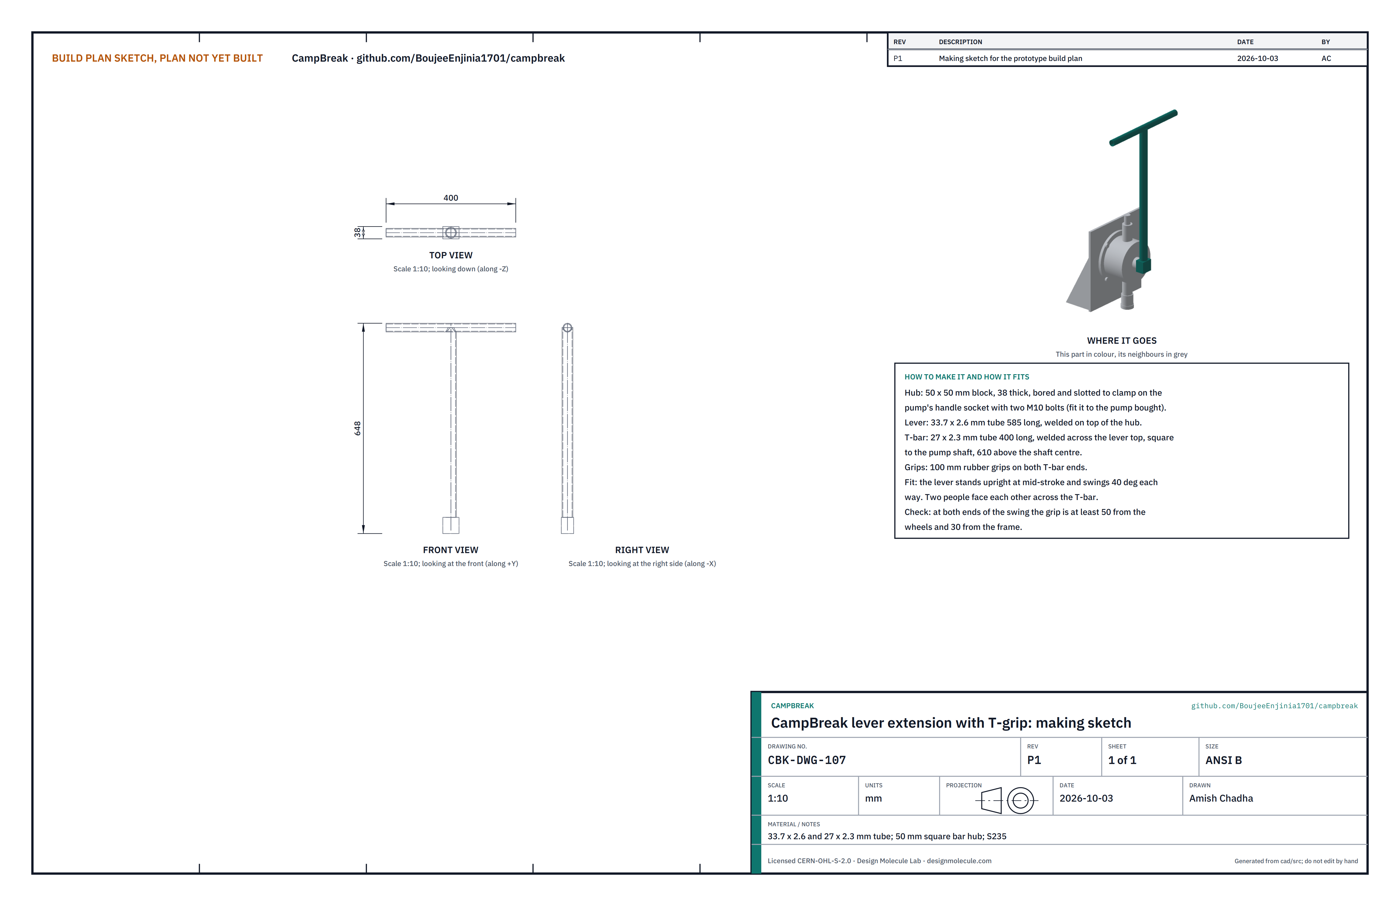
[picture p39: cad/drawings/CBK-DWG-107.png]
Figure 12. Making sketch of the lever extension


*Figure 12. Lever extension making sketch (CBK-DWG-107).*

**What it is and what it is made from.** A clamp hub that fits the pump's handle socket, a 585 mm lever of 33.7 x 2.6 mm tube and a 400 mm T-bar of 27 x 2.3 mm tube with two grips.

**How to make it.**

1. Cut a 50 x 50 block 38 thick. Bore it to fit the pump's handle socket (measured on the pump bought), slot it on one side and drill and tap for two M10 clamp bolts.
2. Weld the lever tube upright on the hub.
3. Weld the T-bar across the top, square to the pump shaft, so the bar centre is 610 above the shaft centre.
4. Push the grips on.

**How it fits the parts next to it.** The hub clamps on the pump's handle socket with the lever upright at mid-stroke. Two people face each other across the T-bar and swing it 40° each way.

**Check before moving on.** At both ends of the swing the grip is at least 50 from the wheels and 30 from the frame.

### 3.8 Hose tray

Figure 13. Making sketch of the hose tray

*Figure 13. Hose tray making sketch (CBK-DWG-108).*

**What it is and what it is made from.** An open tray that carries the suction hose and small parts. 1.5 mm galvanised steel sheet, blank 560 x 530.

**How to make it.**

1. Cut the blank and cut an 80 mm square from each corner.
2. Drill six 12 mm drain holes in the floor (three across at 120 spacing, two rows 200 apart) and four 9 mm bolt holes, 145 each side of the centre line and 120 in front of and behind the middle.
3. Fold the four sides up 90° to 80 tall. The tray is 400 x 370 outside.
4. Pop-rivet the corners and paint the cut edges with zinc-rich paint.

**How it fits the parts next to it.**

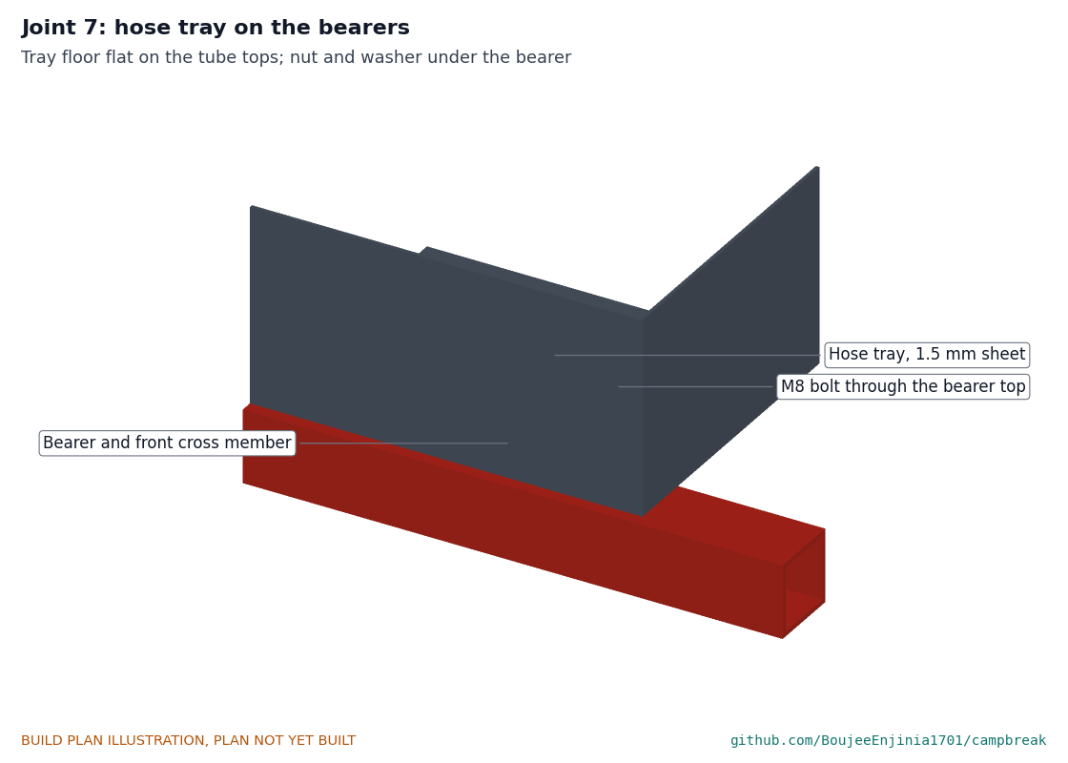
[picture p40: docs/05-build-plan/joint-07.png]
Figure 14. Joint 7: hose tray on the bearers


*Figure 14. The tray floor sits flat on the tube tops; an M8 bolt through each bearer top, nut and washer below.*

**Check before moving on.** The tray sits flat and clears the handle arms by 30 mm.

### 3.9 Bought cart parts

What to buy for the cart (full specifications in the bill of materials), and what to do to each:

- **Wheels:** two 400 mm puncture-proof wheelbarrow wheels, 100 mm wide, with 20 mm bore ball-bearing hubs 75 long. Nothing to do.
- **Hand pump:** a cast-iron double-acting semi-rotary pump with 25 mm ports, at least 0.40 L per double stroke and rated for at least 40 m head. Measure its flange holes and handle socket before drilling the stand plate (3.3) and boring the lever hub (3.7).
- **Relief valve:** a 19 mm spring relief valve set at 4 bar, with a tee. Fit it at the pump outlet with the discharge pointing down.
- **Reel drum:** a steel reel drum with a 200 mm core and 500 mm flanges, 210 apart, and a 19 mm swivel inlet with a hose tail.
- **Hoses:** 30 m of 19 mm semi-rigid hose rated at least 10 bar; 1.2 m of 19 mm reinforced hose and two clips for the pump to reel connection; 4 m of 25 mm wire-reinforced suction hose that bends to 60 mm radius or less.
- **Foot valve:** a 25 mm brass spring-loaded foot valve with a check that seals and a stainless strainer. It keeps the suction hose and the pump full of water between uses. Before you buy, fill one on its hose, hang it up and see that it holds water overnight.
- **Nozzle, couplings and tap adaptor:** a jet and spray nozzle with shut-off and a 6 mm jet; three 25 mm cam-lever coupling sets, the suction hose's one with a 90° elbow hose tail; a push-on tap connector to a 25 mm hose tail.
- **Hose straps:** two rubber straps with buckles, 20 mm wide, long enough to go round the rail and the hose.

Figure 15. Joint 1: axle, axle plates, spacer and wheel hub (cut open)

*Figure 15. The axle passes through 21 mm holes in both axle plates; the spacer holds the hub clear of the outer plate; the collar and R-clip hold it on.*

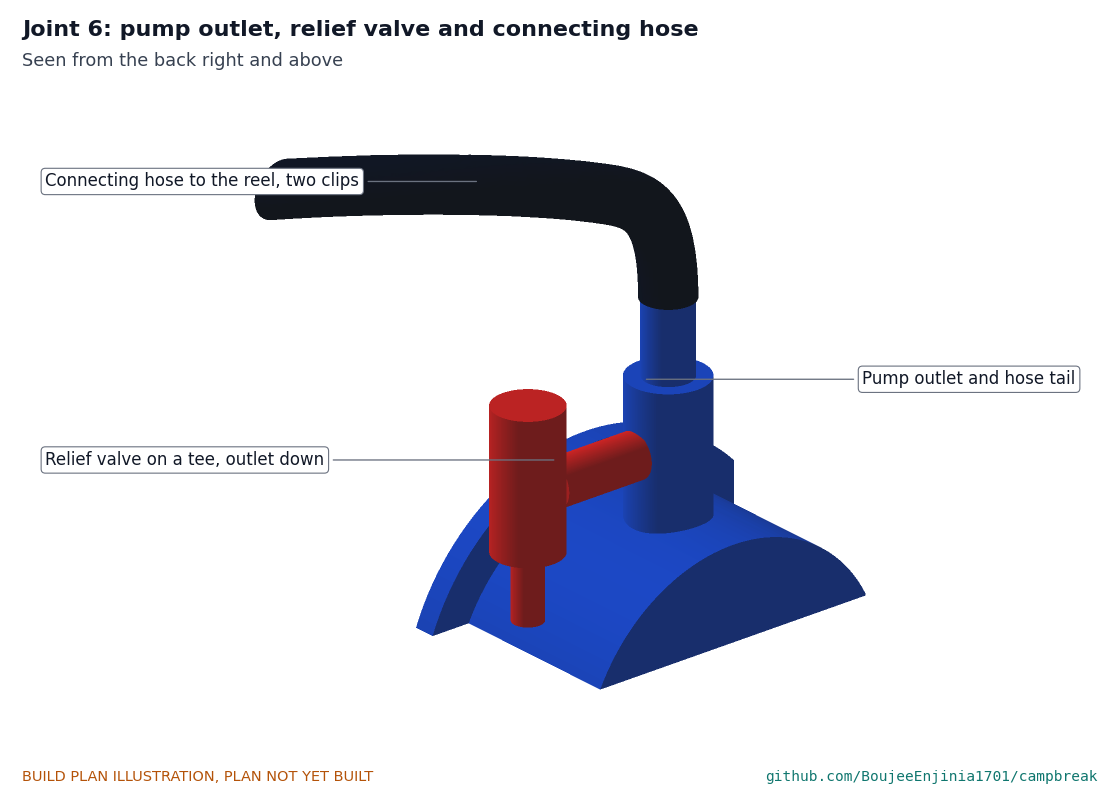
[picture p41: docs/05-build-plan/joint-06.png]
Figure 16. Joint 6: pump outlet, relief valve and connecting hose


*Figure 16. Seen from the back right: the relief valve sits on a tee at the pump outlet with its discharge pointing down; the connecting hose runs from the outlet tail over to the reel swivel, a clip at each end.*

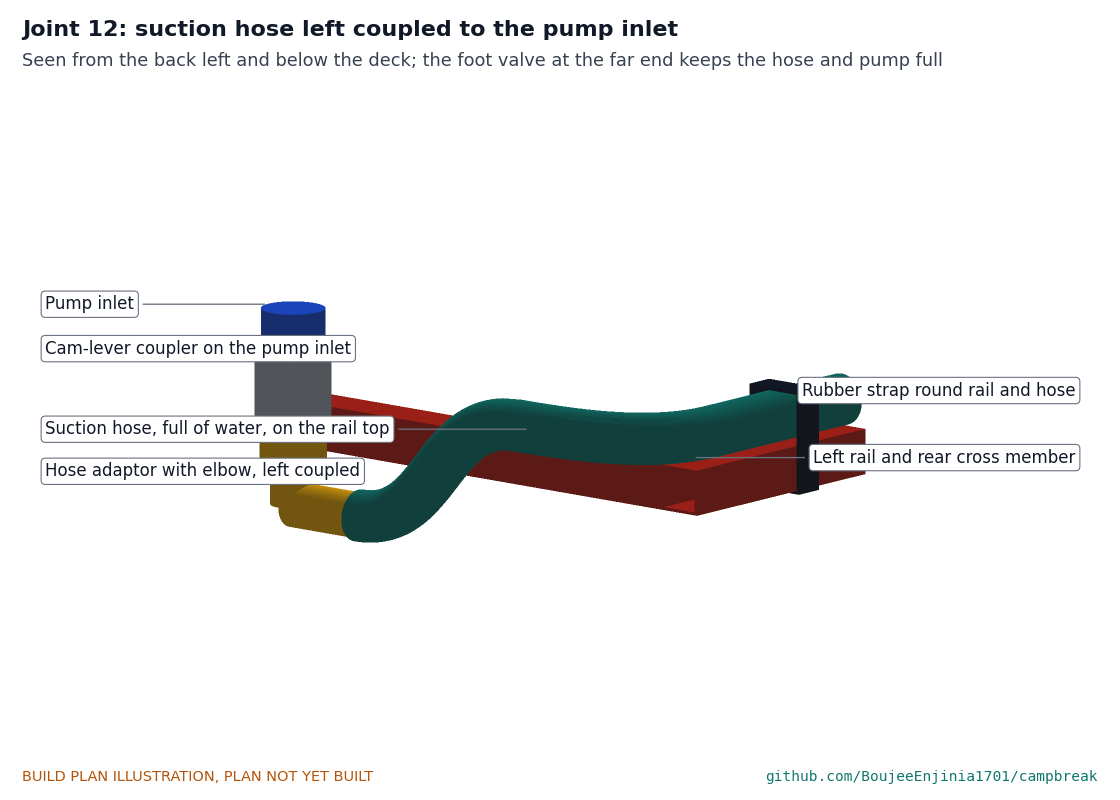
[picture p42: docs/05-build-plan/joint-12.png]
Figure 17. Joint 12: suction hose left coupled to the pump inlet


*Figure 17. Seen from the back left: the suction hose's adaptor stays locked in the coupler under the pump. Its elbow sends the hose left, up behind the end of the left rail and forward along the rail top, under a rubber strap. The foot valve at the far end keeps the hose and the pump full of water.*

### 3.10 Station posts and concrete collars

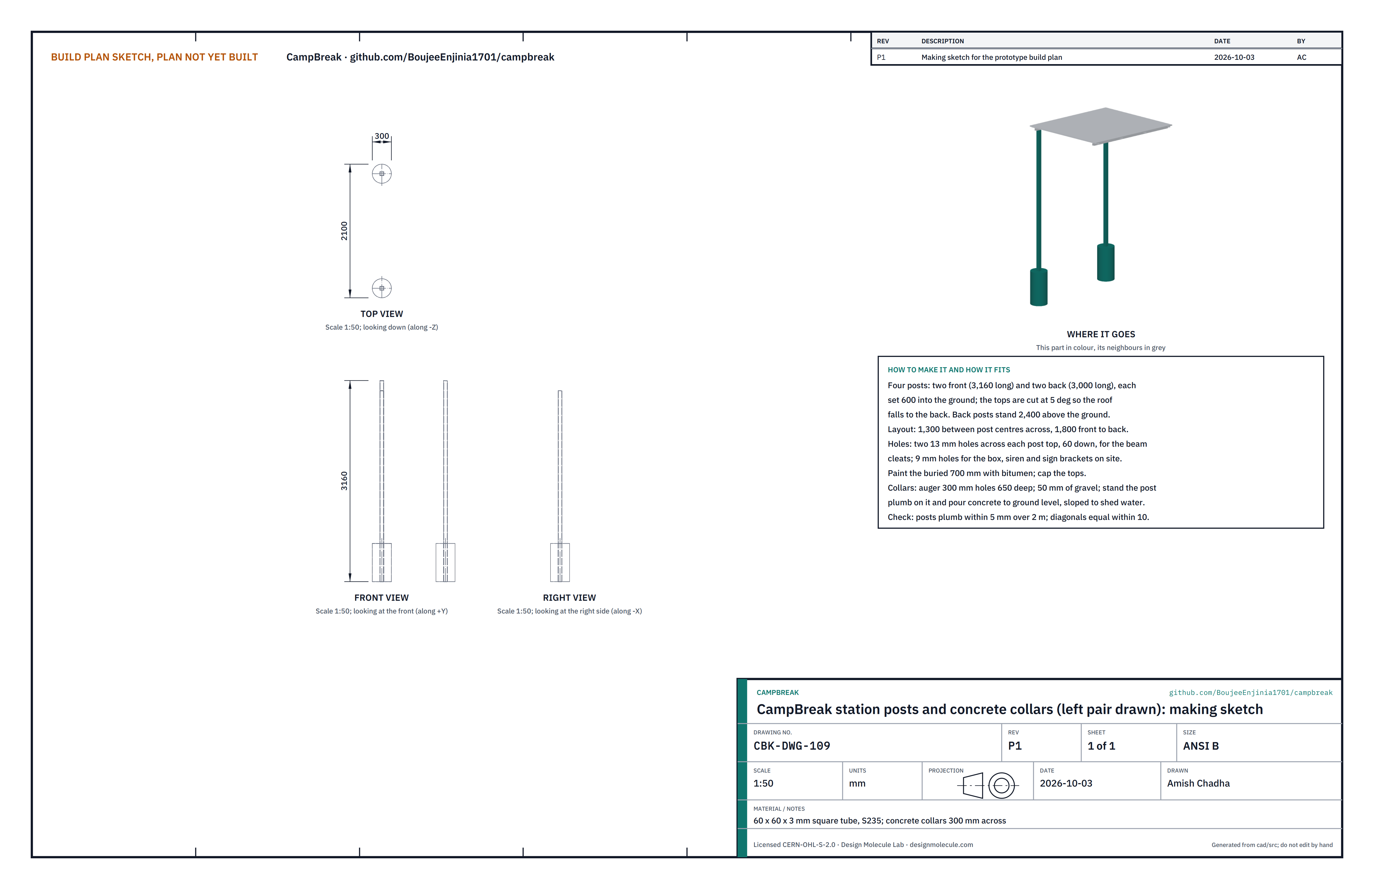
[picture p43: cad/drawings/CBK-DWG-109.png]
Figure 18. Making sketch of the station posts


*Figure 18. Station posts making sketch (CBK-DWG-109), left pair drawn.*

**What it is and what it is made from.** Four posts of 60 x 60 x 3 mm square tube, two front posts 3,160 long and two back posts 3,000 long, each set 600 into a concrete collar 300 across. Four bags of concrete and some gravel.

**How to make it.**

1. Cut the posts to length with the tops cut at 5° so the roof falls toward the back.
2. Drill two 13 mm holes across each post top, 60 down, for the beam cleats.
3. Paint the bottom 700 of each post with bitumen and cap the tops.
4. Peg out the four post centres: 1,300 apart across and 1,800 front to back; check the diagonals are equal within 10.
5. Auger four holes 300 across and 650 deep. Put 50 of gravel in each.
6. Stand each post on the gravel, plumb it in both directions and brace it. Pour concrete to ground level, sloped away from the post. Leave three days before loading.

**How it fits the parts next to it.**

Figure 19. Joint 8: station post in its concrete collar (cut open)

*Figure 19. The post stands 600 into its collar; the top of the collar is ground level.*

**Check before moving on.** Each post is plumb within 5 mm over 2 m; the back post tops are 2,400 above the ground.

### 3.11 Roof frame: beams, purlins and sheet

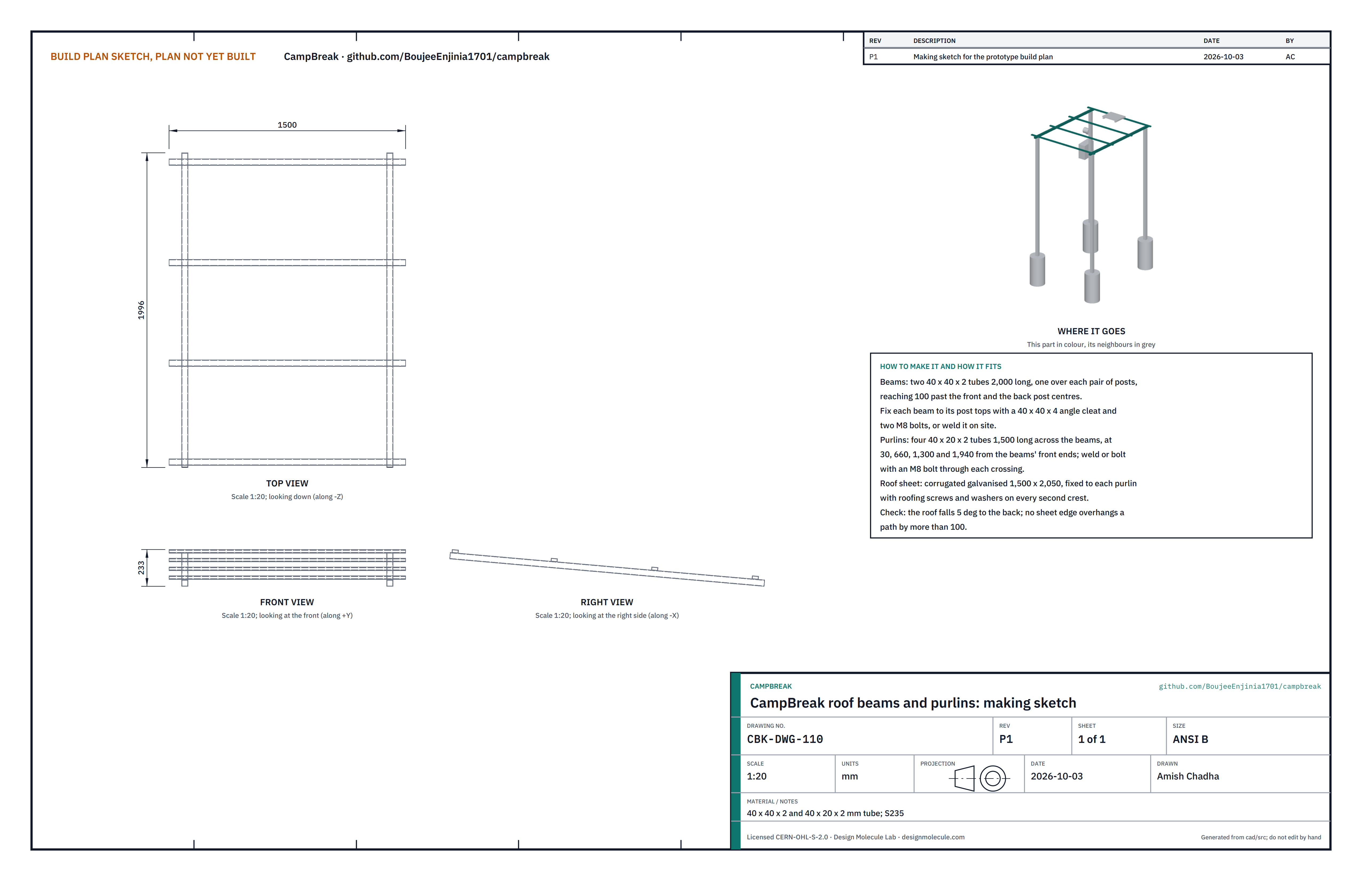
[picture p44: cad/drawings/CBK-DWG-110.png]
Figure 20. Making sketch of the roof frame


*Figure 20. Roof beams and purlins making sketch (CBK-DWG-110).*

**What it is and what it is made from.** Two beams of 40 x 40 x 2 mm tube, 2,000 long; four purlins of 40 x 20 x 2 mm tube, 1,500 long; one corrugated galvanised sheet 1,500 x 2,050; angle cleats, M8 bolts and roofing screws.

**How to make it.**

1. Cut the beams and purlins. Cut four cleats from 40 x 40 x 4 angle and drill them to match the post top holes.
2. Bolt a cleat to each post top. Lift each beam onto a pair of posts so it reaches 100 past the front and back post centres, and bolt or weld it to the cleats.
3. Fix the purlins across the beams at 30, 660, 1,300 and 1,940 from the beams' front ends.
4. Screw the sheet to every purlin through every second crest, with sealing washers.

**How it fits the parts next to it.**

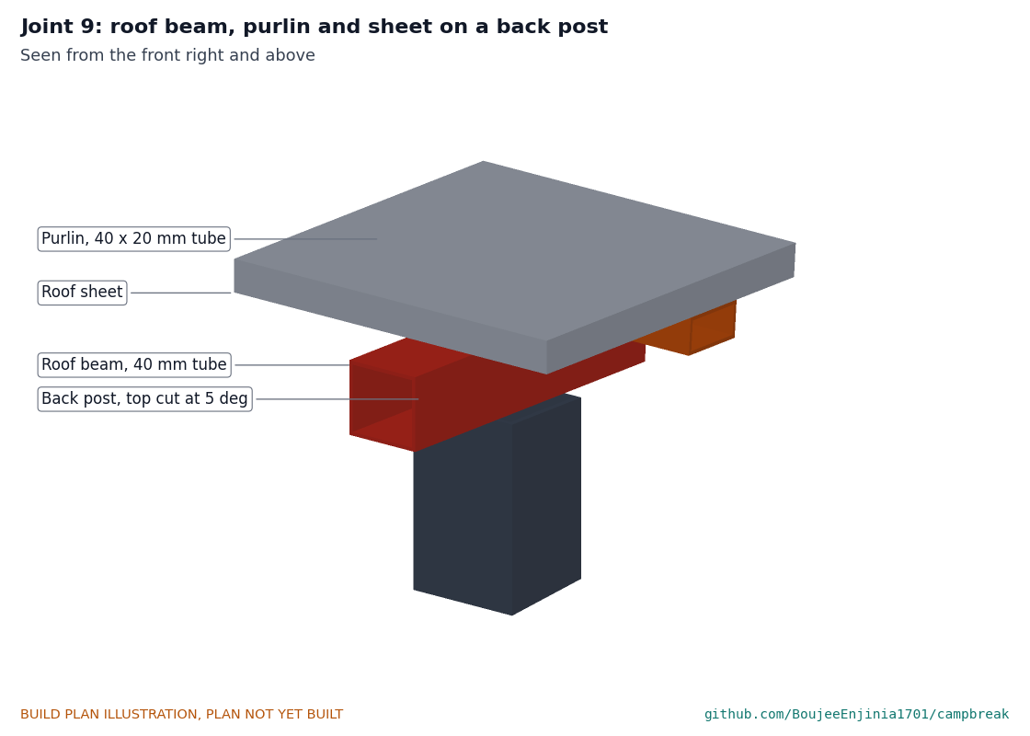
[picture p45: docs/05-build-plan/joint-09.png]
Figure 21. Joint 9: roof beam, purlin and sheet on a back post


*Figure 21. The beam sits on the cut post top; the purlins sit on the beams; the sheet sits on the purlins.*

**Check before moving on.** The roof falls 5° to the back and does not move when pushed at a corner.

### 3.12 Station sign

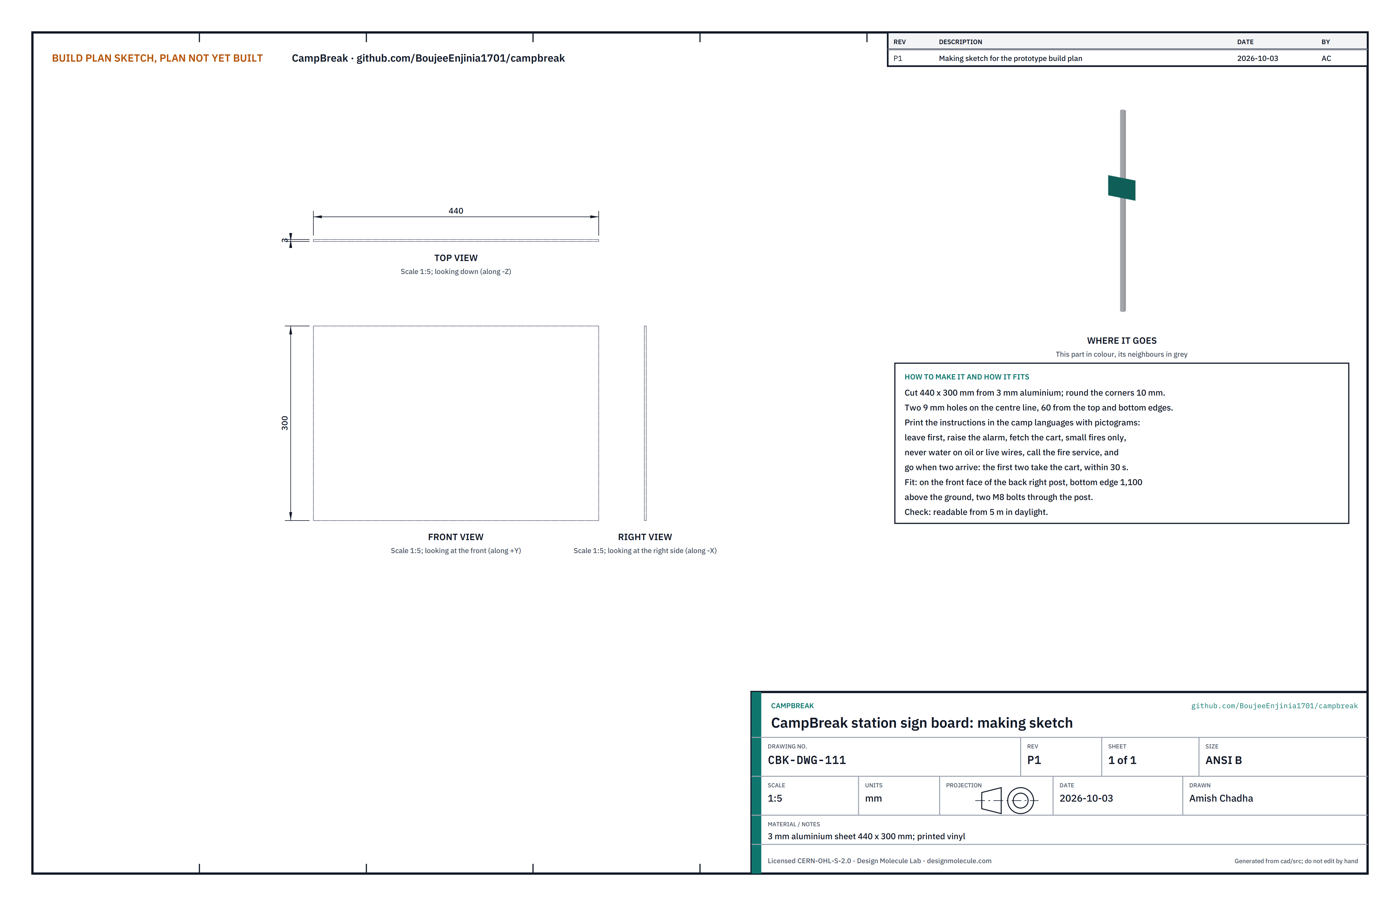
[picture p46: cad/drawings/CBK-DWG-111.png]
Figure 22. Making sketch of the station sign


*Figure 22. Station sign making sketch (CBK-DWG-111).*

**What it is and what it is made from.** A 440 x 300 x 3 mm aluminium sheet with printed instructions in the camp languages and pictograms.

**How to make it.**

1. Cut the sheet and round the corners.
2. Drill two 9 mm holes on the centre line, 60 from the top and bottom edges.
3. Apply the printed vinyl: leave first, raise the alarm, fetch the cart, small fires only, never water on oil or live wires, call the fire service.

**How it fits the parts next to it.** It bolts to the front face of the back right post with two M8 bolts, bottom edge 1,100 above the ground.

**Check before moving on.** It reads clearly from 5 m in daylight.

### 3.13 Bought station parts

- **Station alarm box:** a lockable IP65 box 300 x 300 x 150 holding the receiver board (the alarm board with a relay output), a solar charge controller and a 12 V 7 Ah sealed lead-acid battery with an inline fuse at its positive terminal. Drill it for the cable glands; mount it with U-bolts on the outer face of the back left post, bottom 1,400 above the ground.
- **Siren:** a 12 V siren of at least 110 dB(A) at 1 m on a bolted bracket on the same post, 1,900 up.
- **Solar panel:** a 10 W 12 V panel 350 x 290 on two rails screwed to the roof sheet near the back edge.
- **Water drum:** a 200 L food-grade drum with lid, beside the right of the station.

### 3.14 Heat alarm: mounting plate, box and guard

Figure 23. Making sketch of the heat alarm housing

*Figure 23. Heat alarm housing making sketch (CBK-DWG-112).*

**What it is and what it is made from.** A 140 x 50 x 3 mm aluminium plate, a stock two-part ABS box 100 x 100 x 40, and a small printed guard cup in PETG. Bought parts inside: the alarm board (low-power controller and sub-GHz radio with a thermistor input), a thermistor on a 40 mm lead, a piezo sounder of at least 95 dB(A) at 1 m, a 3 x AA holder with alkaline cells, four standoffs, and two UV-stable cable ties.

**How to make it.**

1. Cut the plate. Mark and file four slots 8 x 3, 58 each side of the middle, from 24 to 27 off the long centre line. Drill two 4.5 mm holes 30 each side of the middle.
2. Drill the box base to match the plate holes (3.3 mm) and screw the plate on from inside with two M4 screws.
3. Drill a 12 mm hole in the middle of the cover and eight 5 mm sound holes round a point 25 from the middle, over where the sounder will sit.
4. Print the guard (24 across, 14 tall, six side slots).
5. Fit the battery holder to the base with double-sided foam tape, screw the board onto its standoffs, lead the thermistor bead out through the 12 mm hole, close the cover and glue the guard over the hole.

**How it fits the parts next to it.**

Figure 24. Joint 10: heat alarm under a roof pole

*Figure 24. Two ties go round the pole, down through the plate slots and tight under the plate.*

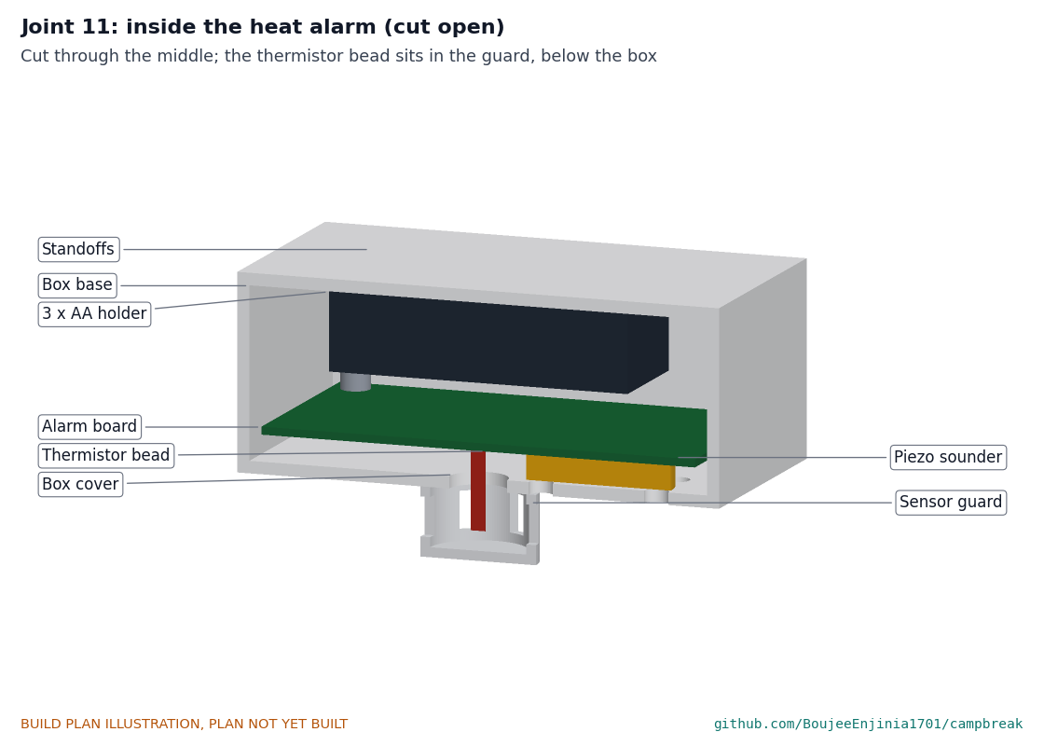
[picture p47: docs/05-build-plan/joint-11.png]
Figure 25. Joint 11: inside the heat alarm (cut open)


*Figure 25. The board sits on standoffs 12 clear of the battery holder; the thermistor bead hangs in the guard below the box, in moving air.*

**Check before moving on.** The cover closes on its seal with nothing pinched; the bead does not touch the guard.

## 4. Putting it together

Parts already fitted are grey; the part being fitted is in colour, pulled back along the way it goes in.

### Step 1: Base frame on its feet

Step 1

Push the rubber feet onto the legs (a dab of contact adhesive) and stand the frame on them.

### Step 2: Handle

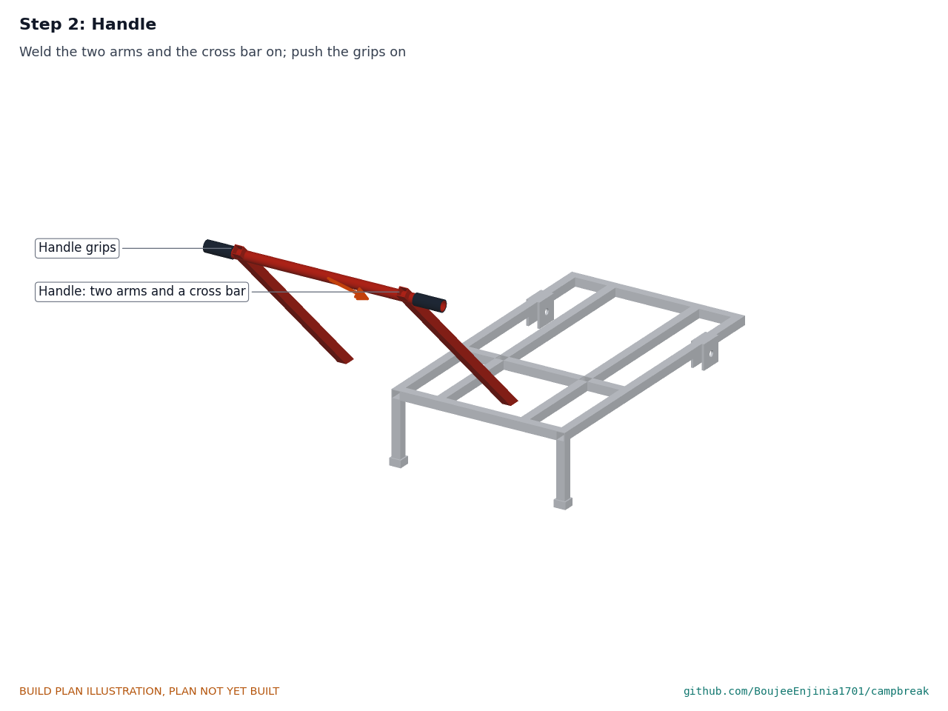
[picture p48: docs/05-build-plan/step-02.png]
Step 2


Weld the handle on as in section 3.2 and fit the grips.

### Step 3: Pump stand

Step 3

Weld the stand plate and gussets as in section 3.3.

### Step 4: Reel uprights

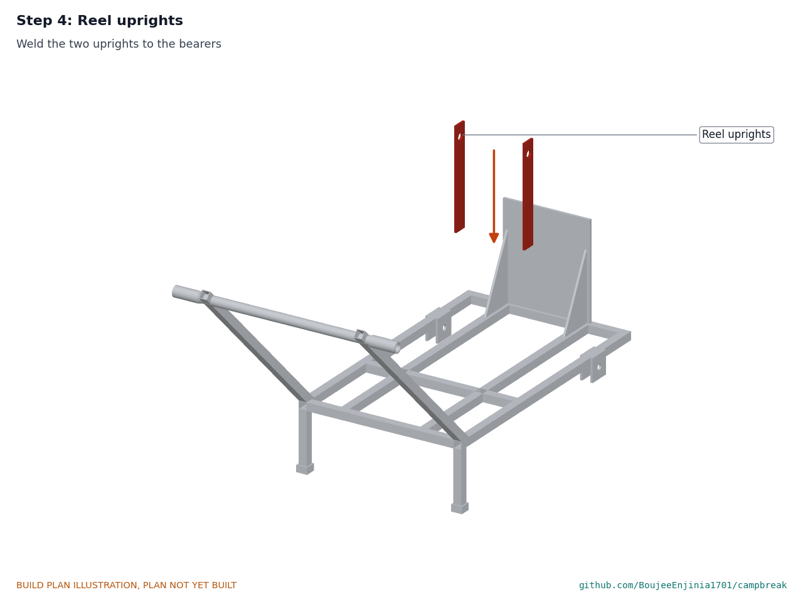
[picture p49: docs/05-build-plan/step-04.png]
Step 4


Weld the two uprights to the rear bearers as in section 3.4. Prime and paint the frame now, before anything is bolted on; mask the axle plate holes and the stand plate's back face.

### Step 5: Axle and wheels

Step 5

Grease the axle. Slide it through all four axle plates. On each side fit a spacer, the wheel, a collar (set screw tightened) and an R-clip.

**Hold point:** the cart rolls straight and both wheels spin freely.

### Step 6: Hand pump

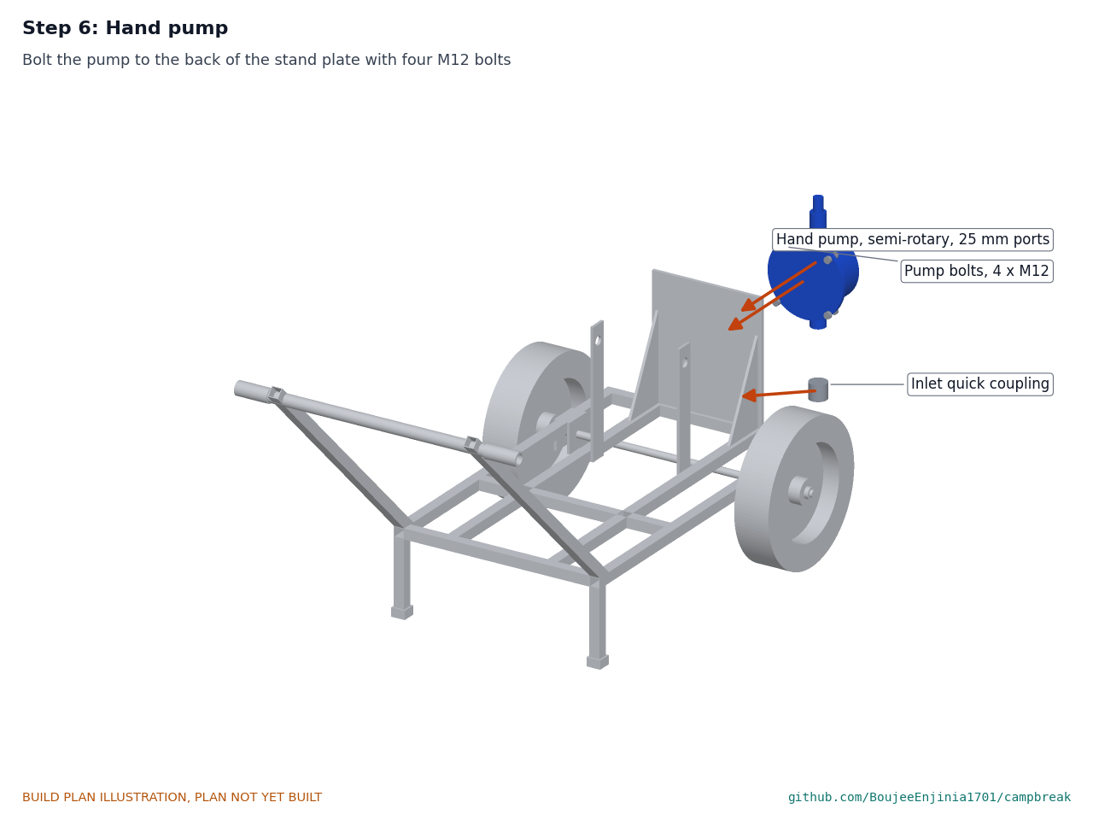
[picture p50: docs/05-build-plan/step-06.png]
Step 6


Two people lift the pump (about 14 kg) onto the back of the stand plate and fit four M12 x 40 bolts with washers both sides. Fit the 25 mm cam-lever coupler to the inlet, pointing down.

### Step 7: Relief valve

Step 7

Fit the tee and relief valve to the pump outlet with thread sealant, discharge pointing straight down.

### Step 8: Lever extension

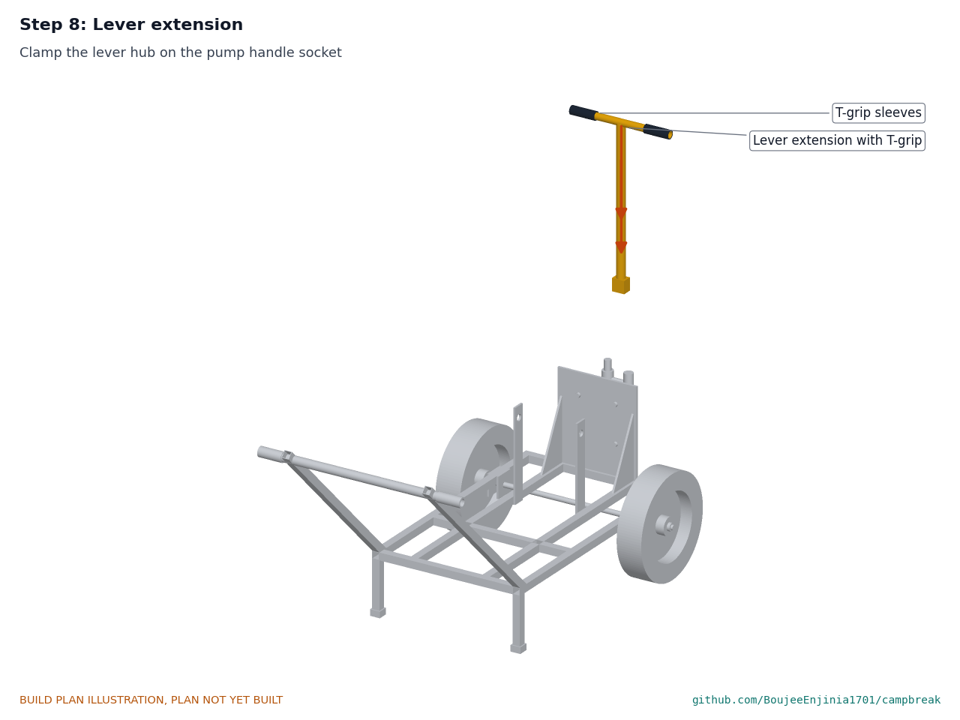
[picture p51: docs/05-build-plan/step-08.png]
Step 8


Clamp the lever hub on the pump's handle socket with the lever upright at mid-stroke and tighten both clamp bolts.

**Hold point:** swing the lever 40° each way: the grip clears the wheels by at least 50 and the frame by at least 30.

### Step 9: Hose reel

Step 9

Hold the drum between the uprights with a spacer each side. Slide the spindle in from the left, fit the collar outside the left upright, and fit the swivel inlet on the right-hand end.

### Step 10: Hoses

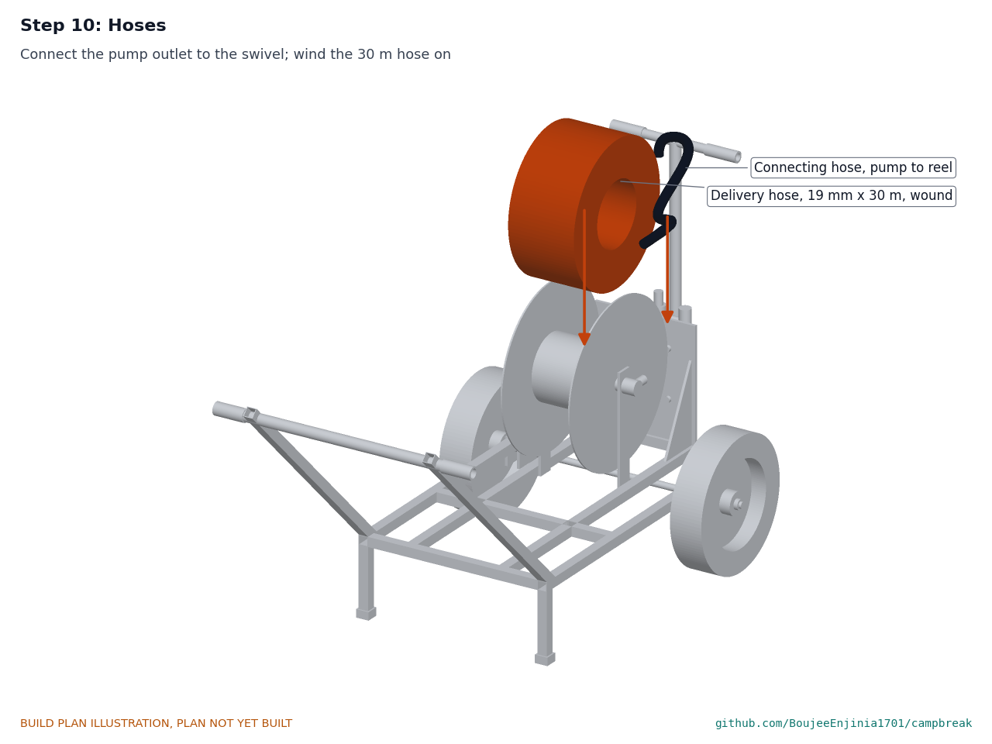
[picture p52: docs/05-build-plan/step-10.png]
Step 10


Fit the connecting hose from the pump outlet tail over to the swivel tail, with a clip at each end. Fit the 30 m hose to the drum's outlet and wind it on in neat even layers; it fills the drum, so a loose wind will not fit. Fit the nozzle to the free end.

### Step 11: Hose tray

Step 11

Bolt the tray to the bearers with four M8 bolts, washers and nyloc nuts.

### Step 12: Suction kit

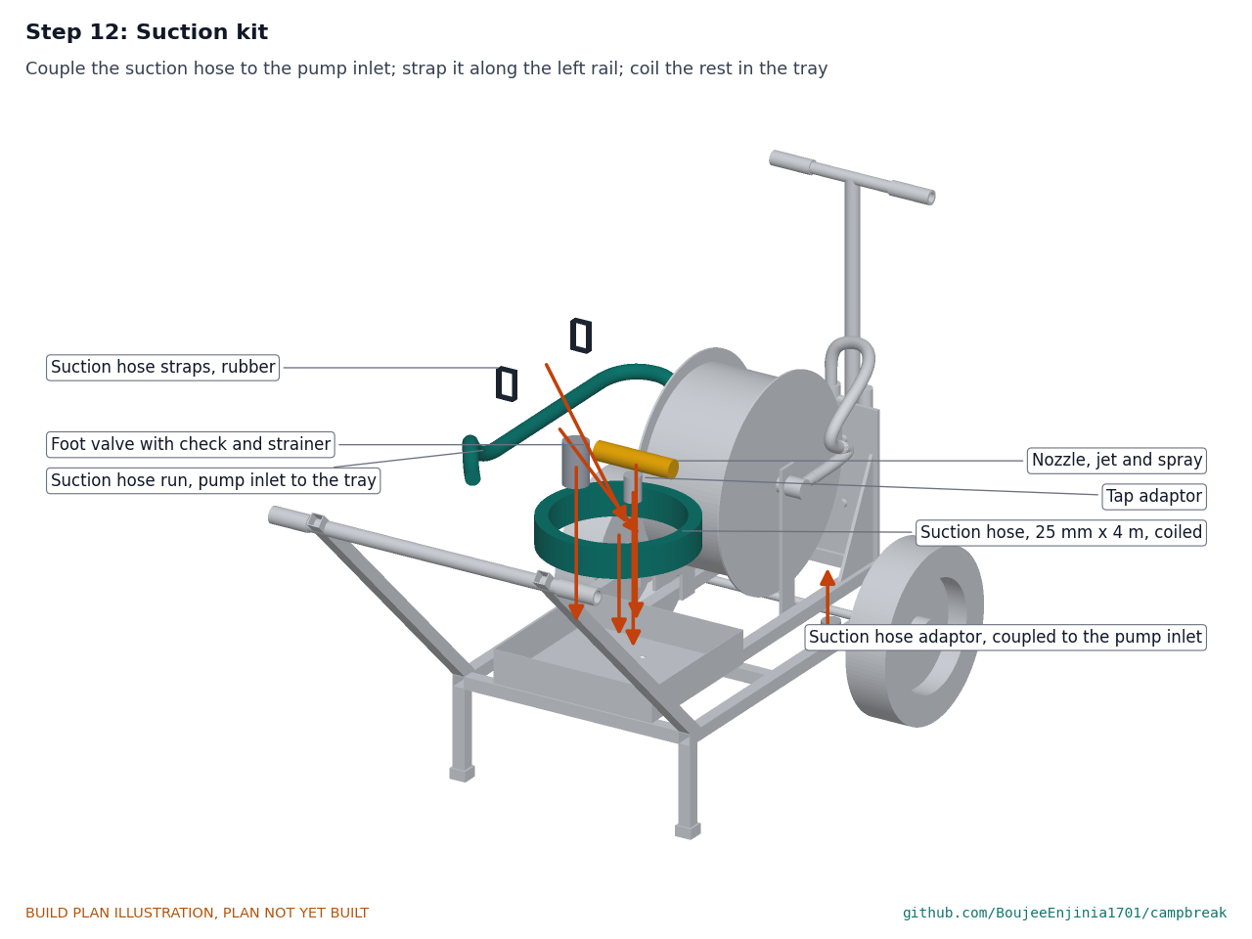
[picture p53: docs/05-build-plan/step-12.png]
Step 12


Fit the foot valve to one end of the suction hose and the cam-lever adaptor with its elbow to the other. Push the adaptor into the coupler under the pump and close both cam levers; it stays coupled from now on. Lead the hose to the left, up behind the end of the left rail and forward along the rail top, and fasten it with the two rubber straps. Coil the rest in the tray with the foot valve on top, and lay the tap adaptor inside the coil. Stow the nozzle in the tray when the hose is wound. Fit the reflective tape and the pump instruction label.

**Prime it once.** Stand the foot valve in a bucket of water and pump until water comes out of the nozzle, then lift the foot valve out. From now on the check in the foot valve keeps the pump and the suction hose full (see the weekly check on the drill card, section 5a). 

**Fill the delivery hose.** With the foot valve still in the bucket, run out the 30 m hose, open the nozzle and pump until water runs steadily from it, then close the nozzle shut-off and wind the full hose back onto the reel. The shut-off holds the water in; the 4 bar relief valve protects the full hose if the sun heats it. Top the bucket up if it runs low. A full hose is heavy to wind (about 8.9 kg of water), so wind it with two people.

### Step 13: Posts in their collars

Step 13

Set the posts and pour the collars as in section 3.10.

### Step 14: Roof beams

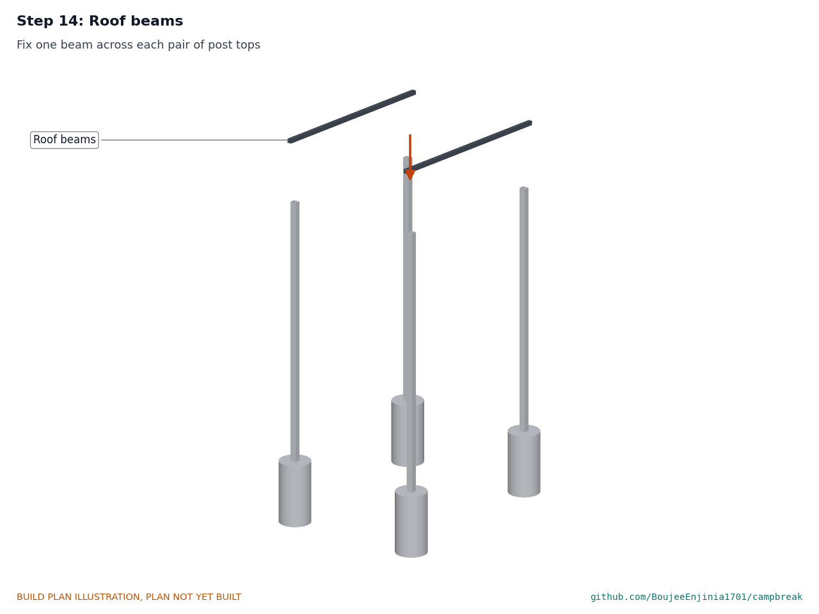
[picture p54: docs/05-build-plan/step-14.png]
Step 14


Fix the beams to the post tops as in section 3.11.

**Hold point:** posts plumb and braced; concrete at least three days old.

### Step 15: Purlins and roof sheet

Step 15

Fix the purlins, then screw the sheet down.

### Step 16: Station alarm box, siren and solar panel

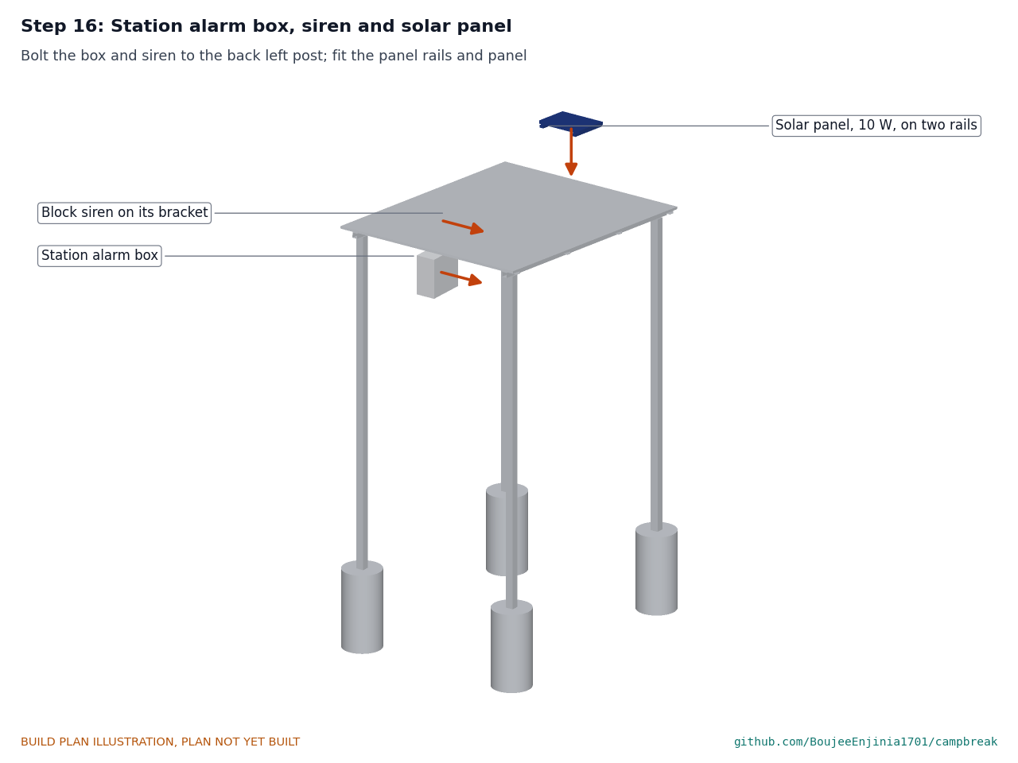
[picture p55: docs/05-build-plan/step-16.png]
Step 16


U-bolt the box to the back left post and bolt the siren bracket above it. Screw the panel rails to the sheet and bolt the panel on. Run the cables through glands into the box. Wire the panel to the charge controller and the siren to the relay output; connect the battery last, through its fuse.

### Step 17: Sign, drum and cart

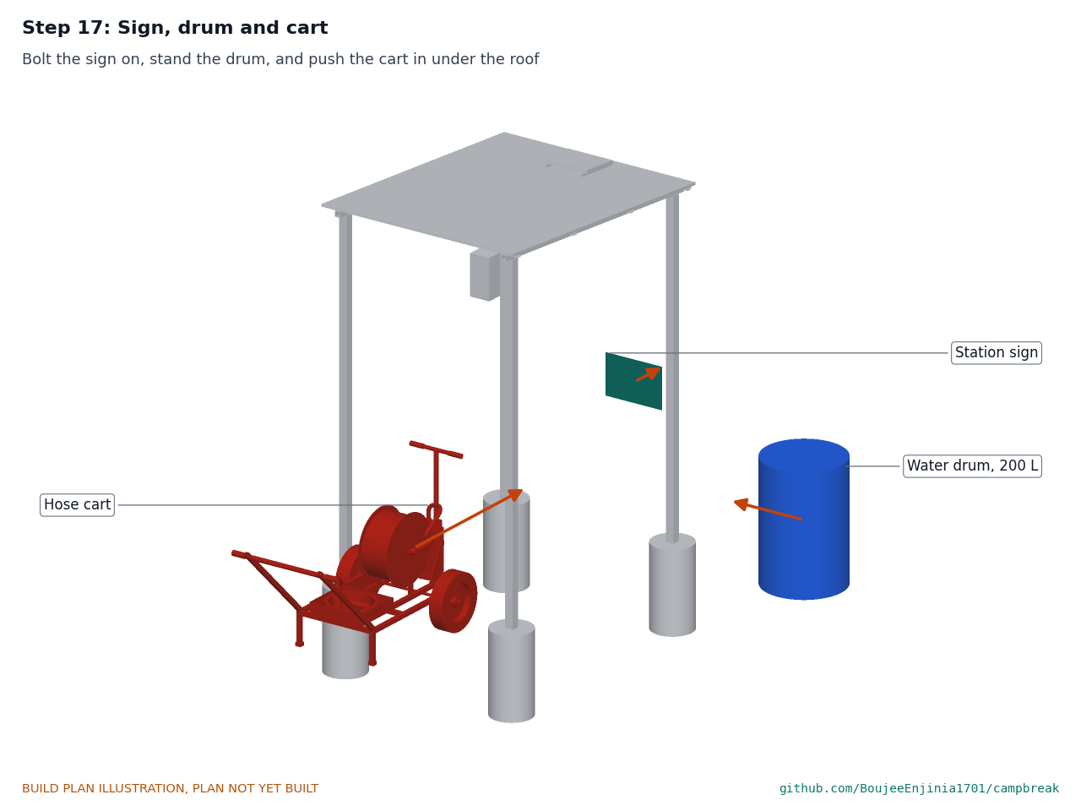
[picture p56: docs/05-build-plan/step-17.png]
Step 17


Bolt the sign to the back right post. Stand the drum beside the station and fill it. Push the cart in under the roof, handle to the front.

### Step 18: Plate on the box base

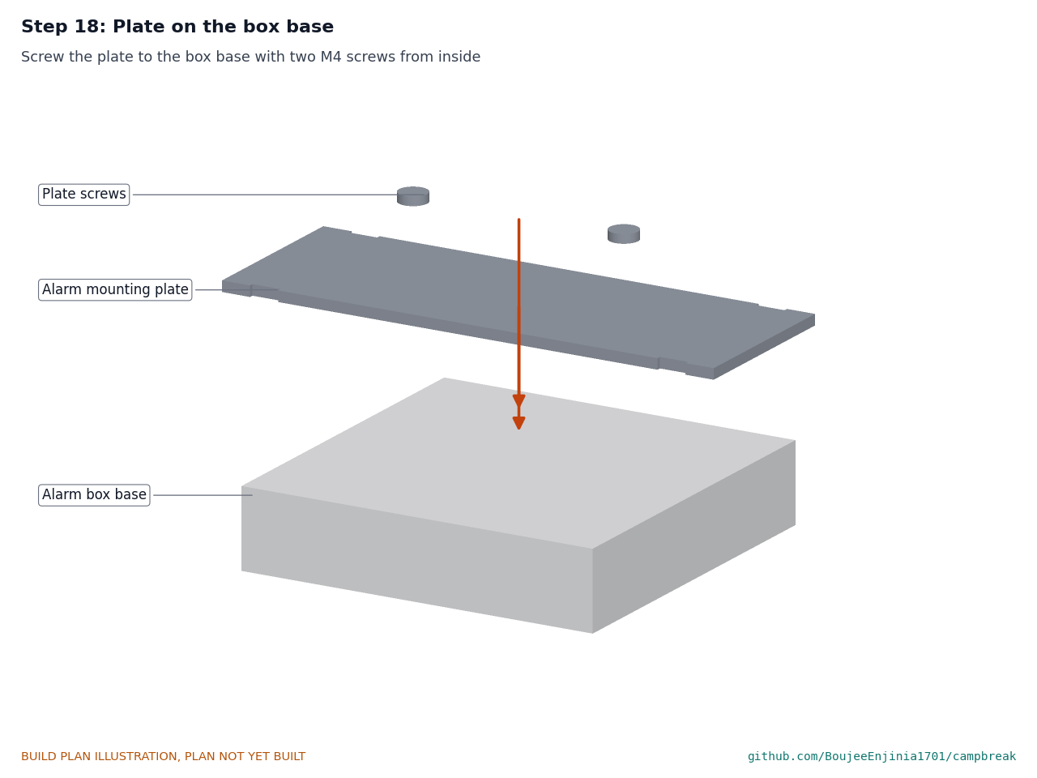
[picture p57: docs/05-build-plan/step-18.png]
Step 18


Screw the mounting plate to the alarm box base with two M4 screws from inside.

### Step 19: Battery holder and board

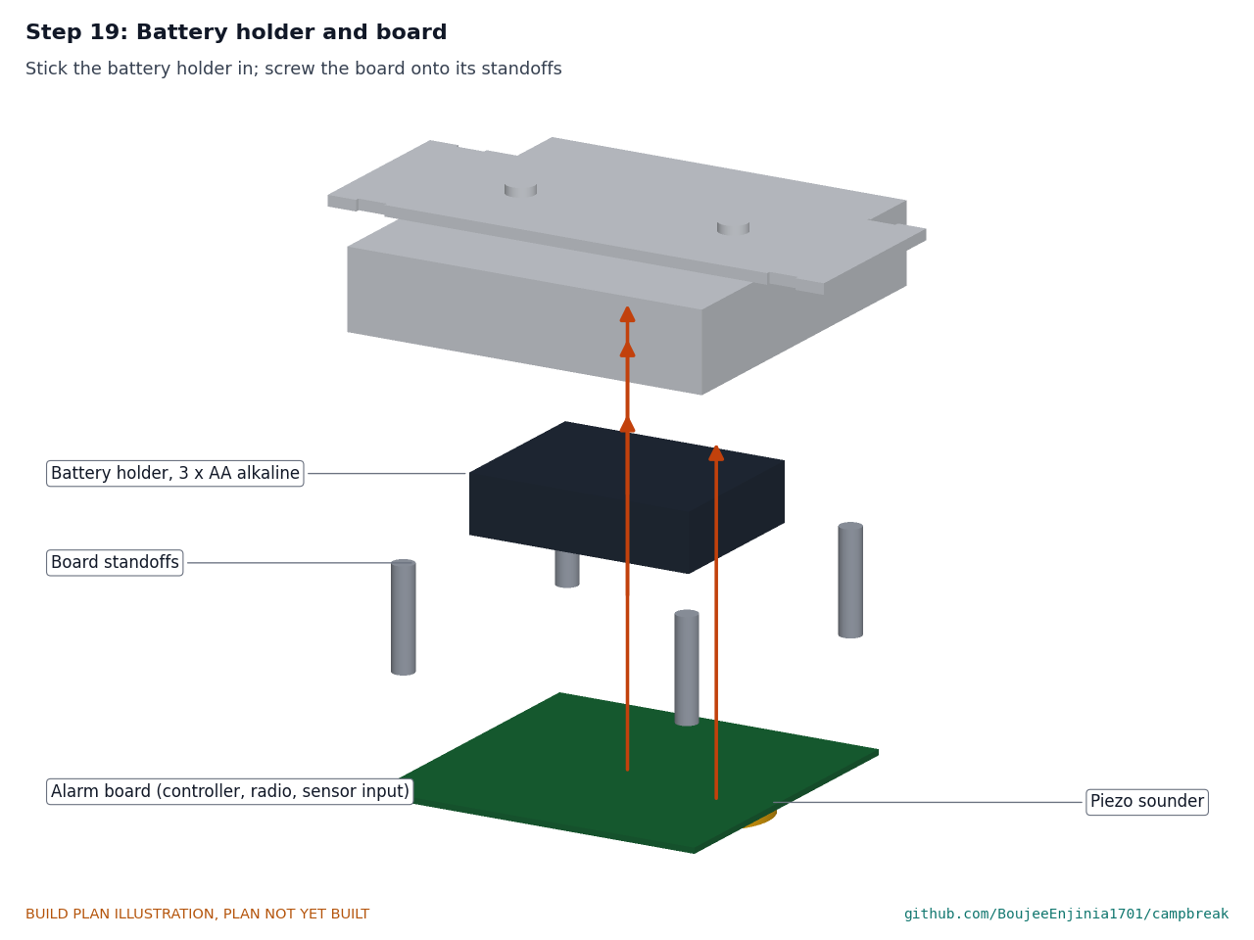
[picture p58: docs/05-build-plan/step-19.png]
Step 19


Fit the battery holder, the standoffs and the board with its sounder. Leave the cells out.

### Step 20: Cover, thermistor and guard

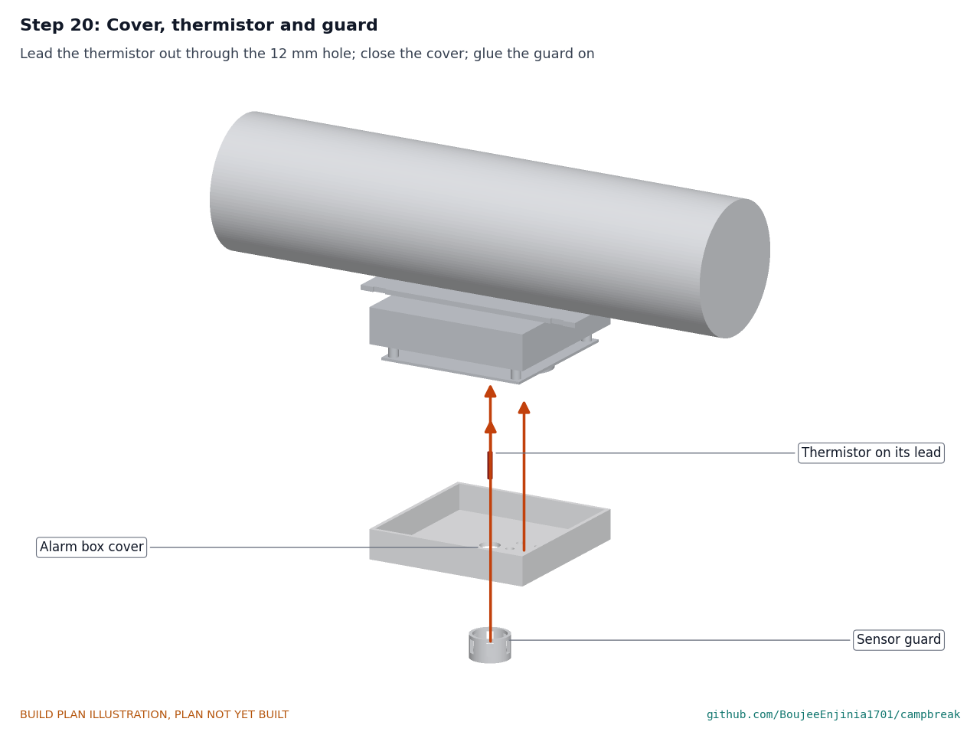
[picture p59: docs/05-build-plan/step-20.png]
Step 20


Lead the thermistor out through the cover hole, close the cover and glue the guard on.

### Step 21: Hang it under a roof pole

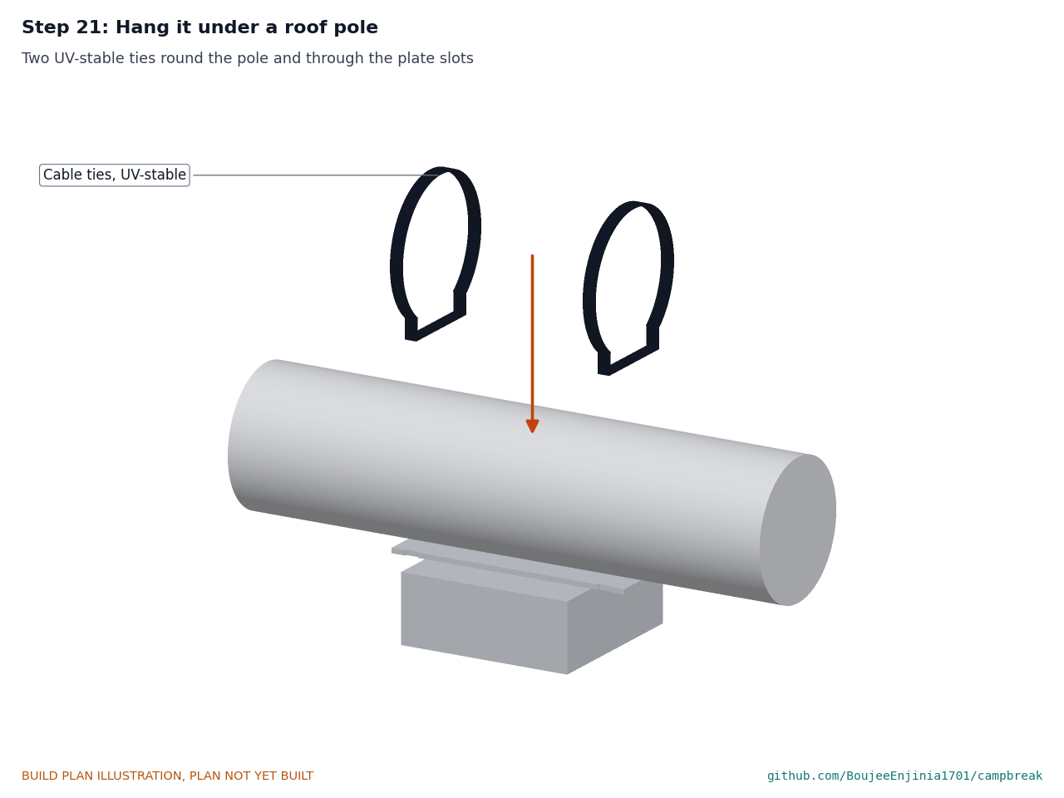
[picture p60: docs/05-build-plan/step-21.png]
Step 21


Put the cells in, close the box, and hang it under a roof pole about 300 from the ridge with two UV-stable ties through the plate slots, pulled tight under the plate.

## 5. First checks

These are listed here and recorded at TRL 4 in a test report.

*Table 2. First checks.*

| Check | Requirement | How | Pass when |
| --- | --- | --- | --- |
| Cart width | R6 | Tape across the tyres | 900 mm or less |
| Pulling | R6 | Two adults pull the loaded cart (delivery hose full) 100 m up a 10 % unpaved slope; note the effort | 3 min or less; effort per person against the 100 N assumed (about 101 N expected) |
| Flow | R7 | Pump from a drum into a measured container for 1 min, then for 10 min | At least 20 L/min, kept up for 10 min |
| Relief valve | R7, safety | Shut the nozzle and pump slowly; watch a gauge on the tee | Valve opens at 4 bar ± 0.5; nothing leaks |
| Jet reach | R8 | Measure where the jet lands on level ground at 30° | 6 m or more |
| Alarm trigger | R1 | Warm the bead with a hot-air gun through a ramp logged by a reference thermometer | Sounds at 8 °C per minute or faster, and at 57 °C |
| Alarm sound | R3 | Sound meter at 3 m | 85 dB(A) or more |
| Relay | R4 | Trigger one alarm in a mock block | Station siren and every alarm within 10 s |
| Cooking | R2 | One hour of stove cooking 1 m from an alarm in a mock shelter | No alarm |
| Pump stays primed | R9 | Leave the primed cart a week, drop the foot valve in a drum and pump | The lever takes load within 3 strokes; water at the nozzle in about 30 s; no drip from the foot valve |
| Hose stays full | R9 | Leave the cart with the delivery hose full and the nozzle shut for a week, then open the nozzle | Water leaves the nozzle at once with no air; no drip at the nozzle or swivel |
| Drill | R9 | Timed drill from the siren to water on target at 70 m and 100 m, using the drill card | 3 min or less at both distances (2.95 min and 2.5 min expected) |

## 5a. Drill card

The drill card is printed in the camp languages, laminated and kept in the station box; the station sign carries the first line. Volunteers practise it until the first two are away with the cart within 30 s of the siren.

*Table 3. Drill card.*

| When | What to do |
| --- | --- |
| Siren sounds | Everyone in the burning shelter and its neighbours gets out first. Volunteers go to the station |
| At the station | **Go when two arrive.** The first two volunteers take the cart out at once; do not wait for more. Never more than 30 s from the siren. Two people always move the cart; never run with it |
| Others | Follow to the fire; take over the second side of the pump lever when you arrive |
| At the fire | Park the cart on its feet, upwind, at least 6 m from the fire. Person 1: lift the suction hose off the rail, drop the foot valve in the drum or water, and start pumping; it is already coupled and primed. Person 2: run out the hose from the reel and aim at the base of the fire. The hose is already full, so water leaves the nozzle as soon as the first strokes lift water |
| Never | Water on burning oil or live wiring. Go into a burning shelter |
| Every week | Prime check: drop the foot valve in the station drum and pump. The lever should take load within three strokes and water reach the nozzle in about 30 s. If not, re-prime (Step 12) and report the foot valve. Then check that the delivery hose is still full: open the nozzle for a moment; if air comes out, pump until water runs, shut the nozzle and wind the hose back |

## 6. Safety stops

Work stops at each point below until what is listed is true.

1. **Before welding:** screen, gloves and mask on; fire extinguisher and a fire watch in place; no fuel, tarpaulin or shelters within 10 m.
2. **Before the first pumping:** the relief valve is fitted with its discharge pointing down; every hose clip and coupling is tight; the hose shows no cuts or kinks; nobody stands in front of the nozzle.
3. **Before pumping against a shut nozzle (relief check):** a pressure gauge is fitted on the tee, and the person pumping goes slowly and stops at 4.5 bar if the valve has not opened.
4. **Before moving the loaded cart on a slope:** two people on the handle, a third holding back on slopes steeper than 10 %; nobody in front of the cart downhill.
5. **Before putting up the roof:** posts braced and the concrete at least three days old; two people on stepladders; no work in wind.
6. **Before connecting the station battery:** the fuse is out, all wiring is finished and checked, and the box can be locked.
7. **Before any drill with fire:** the fire service or the camp's fire safety focal point is present, the fire is a small controlled test fire in a cleared area, and everyone knows that people leave first and water is never used on burning oil or live wiring.

## 7. Tools, skills and workspace

- **Workshop:** a flat steel or concrete welding table at least 1.2 x 2 m, a bench vice, and space to roll the finished cart out.
- **Tools:** angle grinder with cutting and flap discs, chop saw or hacksaw, pillar drill with bits to 26 mm (or a 21 mm and 26 mm hole saw in a magnetic drill), MIG welder (or stick welder), clamps, square and tape, hand folder or bending brake for 1.5 mm sheet, pop-rivet gun, taps M4 and M10, spanners to 19 mm, post-hole auger, spirit level, stepladders, a small soldering iron and screwdrivers for the alarm, a 3D printer for the guard.
- **Skills:** basic fabrication and fillet welding of thin-wall tube; setting posts in concrete; simple electrical wiring with a fuse. No machining is needed beyond drilling.
- **People:** two for lifting the pump and the roof parts; one for the alarm.

## 8. Where the numbers come from

- Model: `cad/src/model.py` (constructable design and its 115 constructability checks)
- General arrangement: `cad/drawings/CBK-DWG-001` (from `cad/src/sheets.py`)
- Making sketches and pictures: `cad/drawings/CBK-DWG-101` to `112` and `docs/05-build-plan/` (from `cad/src/build_plan_media.py`)
- Calculations: `docs/04-calcs/01-sizing.md` (CBK-CAL-001) and `docs/04-calcs/sizing.py`
- Bill of materials: `bom/bom.csv`
- Decision records: `docs/decisions/0001-trl2-review-decisions.md`, `docs/decisions/0002-design-for-construction.md` and `docs/decisions/0003-r9-response-time.md`

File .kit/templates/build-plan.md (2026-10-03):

---
doc_id: PRJ-BLD-001
title: Project prototype build plan
project: Project name
doc_type: Build plan
version: "0.1"
status: Draft
date: YYYY-MM-DD
author: Amish Chadha
license: CERN-OHL-S-2.0
revisions:
  - version: "0.1"
    date: YYYY-MM-DD
    author: Amish Chadha
    change: First build plan; design made constructable
---

# Project prototype build plan

**Plan, not yet built.** How to build the first proof-of-concept prototype, component by component. Building and testing to it is TRL 4 work. Decisions still to be made are kept in the design decisions register (`docs/06-design-decisions.md`), not here.

## 1. What you are building

Every component, pulled apart and numbered in build order

One short paragraph: what the prototype is, how many components, which are made and which are bought, and the main ways they are made.

## 2. What changed to make it buildable

| Component | The concept had | The buildable design has | Why |
| --- | --- | --- | --- |

## 3. Making the components

### 3.1 Component name

Making sketch

**What it is and what it is made from.**

**How to make it.**

1. Mark out ...
2. Cut ...

**How it fits the parts next to it.**

Close-up of the joint

**Check before moving on.**

## 4. Putting it together

### Step 1: ...

Step 1

## 5. First checks

| Check | Requirement | How | Pass when |
| --- | --- | --- | --- |

## 6. Safety stops

## 7. Tools, skills and workspace

## 8. Where the numbers come from

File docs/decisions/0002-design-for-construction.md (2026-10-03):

---
doc_id: CBK-DDR-002
title: CampBreak design for construction
project: CampBreak
doc_type: Design decision record
version: "0.1"
status: Draft
date: '2026-10-03'
author: Amish Chadha
license: CERN-OHL-S-2.0
revisions:
- version: "0.1"
  date: '2026-10-03'
  author: Amish Chadha
  change: Changes that make the concept buildable, decided under Amish's 2026-10-03 pre-approval
---

# 0002: Design for construction

- **Date:** 2026-10-03
- **Status:** decided. Amish, 2026-10-03: "start with the first 14 repos from the list of 29 projects. I pre-approve the batch runs along with any recommendations you come up with. I also accept any cost overruns or variations from the assumed scope cost." This covers every change below.

## Context

STANDARDS section 18 requires a constructable design at TRL 3 (Amish, 2026-09-30: "fix the design assumptions to match and be physically feasible"). The TRL 2 massing model showed what CampBreak does (an alarm in each shelter, a station, and a two-wheeled cart with a hand pump, reel and hose) but its parts were blocks with no process and no fixings. The parametric model `cad/src/model.py` was rebuilt so that every part is cut, drilled, welded, folded, cast or bought, and every joint has a fixing. It runs 97 constructability checks (`python3 cad/src/model.py --check`): parts that must touch do touch with no overlap, and parts that must stay apart keep a stated clearance, including the pump lever at both ends of its swing. All 97 pass.

The changes keep what the kit does, its pitch and its safety case: the same alarm principle, station role, pump type, hose, nozzle, cart width and crew of two.

## Decision

*Table 1. Changes made.*

| # | Problem in the concept | Change made | Why this way |
| --- | --- | --- | --- |
| P1 | Cart frame drawn as a solid platform, with no stock size or joints | A welded ladder frame of 30 x 30 x 2 mm square tube: two side rails 1,000 mm, three cross members (the middle one in three pieces), two lines of bearers 260 mm apart under the pump and reel, all tops flush | One tube size, square cuts, every joint a fillet weld on a flat table; the bearers carry the pump stand, reel uprights and tray |
| P2 | Wheels drawn on the frame sides with no axle mounting | A 20 mm through axle in four 80 x 85 x 8 mm axle plates (one each side of each rail), with 22 mm spacers, the wheel hubs, collars and R-clips | The axle is clear of the tube walls by 4.5 mm; two plates per side carry the load in double shear; the wheels come off with an R-clip |
| P3 | Cart stood only on its wheels | Two 190 mm legs under the rail front ends with 40 mm rubber feet | The cart parks level and stays put; lifting the bar by 73 N takes the feet off the ground |
| P4 | Pull bar drawn floating in front of the frame | Two 30 mm tube arms, cut to sit flat on the rail tops with the toe against the front cross member, coped to a 33.7 mm cross bar 820 mm long at 800 mm height, with grips | A welded triangle at each foot; bar height suits two adults pulling side by side |
| P5 | Pump drawn sitting on the deck with no fixing | A 10 mm stand plate, 320 x 355 mm, welded on the rear cross member with two 8 mm gussets to the bearers; the pump flange bolts to its back face with four M12 bolts on a 150 mm square | Puts the shaft 440 mm up, so the lever swings clear of the wheels and frame (checked at both ends of the swing) |
| P6 | Pump handle too short for two people | A clamp-on lever extension: 585 mm of 33.7 mm tube to a 400 mm T-bar, grip 610 mm from the shaft | Two people face each other across the T-bar; the force per person is about 28 N |
| P7 | Hose reel drawn as a cylinder with no support | A bought steel drum on a 25 mm through spindle in two welded 50 x 8 mm uprights, with 12 mm spacers, a collar on the left and a swivel inlet on the right | Uses a stock reel drum; the swivel lets the hose pay out while the pump is connected |
| P8 | No connection from the pump to the reel | 1.2 m of 19 mm reinforced hose from the pump outlet over to the swivel, with two clips; the 4 bar relief valve on a tee at the pump outlet, discharge pointing down | The connection is checked clear of the relief valve, stand and reel; relief water goes to the ground, not at the crew |
| P9 | Station drawn as a two-post cantilever roof | Four posts of 60 x 60 x 3 mm tube, 600 mm into concrete collars 300 mm across, two roof beams, four purlins and a corrugated sheet falling 5° to the back | A cantilever on two posts needed a moment connection at the ground; four posts in collars resist the uplift of a 30 m/s gust with a factor of about 2 using only bolts and welds |
| P10 | Station alarm box, siren, solar panel and sign drawn touching the posts with no fixings | Box and siren bolted to the back left post with U-bolts and a bracket; panel on two rails screwed to the roof sheet; sign on two M8 bolts through the back right post | All fixings are bought hardware |
| P11 | Loose suction hose, strainer, nozzle and tap adaptor | A folded 1.5 mm galvanised tray, 400 x 370 x 80 mm, with drain holes, bolted to the bearers with four M8 bolts; the suction hose coils in it with the small parts inside the coil | Everything needed at the fire travels on the cart and drains after use |
| P12 | Heat alarm drawn as a box glued to the roof | A 140 x 50 x 3 mm aluminium plate screwed to the box base, hung under a roof pole by two UV-stable cable ties through slots; the board on standoffs; the thermistor bead below the box inside a printed guard | Bamboo poles cannot take screws reliably; ties fit any pole from about 50 to 100 mm. The bead in moving air below the box sees the heat first |

*Table 2. Knock-on changes.*

| Item | Change |
| --- | --- |
| Mass | Loaded cart 91.4 kg (est.); 89 N per person on a 10 % slope; R6 still met (CBK-CAL-001, sections C and D) |
| Cost | USD 1,355 for the block kit, USD 245 under the USD 1,600 value-engineering target (`budget_usd` unchanged) |
| Drawings | CBK-DWG-001 Rev P1 (general arrangement) and making sketches CBK-DWG-101 to 112 |
| Documents | CBK-CAL-001 v0.1 written on this design; CBK-PRC-001 and CBK-REQ-001 revised to v0.3 |

## Consequences

- `design_state: constructable` in `project.yaml`. The build plan CBK-BLD-001 shows every component and step in pictures generated from the model (`cad/src/build_plan_media.py`).
- The appearance model `cad/src/product_model.py` uses this design; photoreal renders are made on Amish's Mac.
- The pump's flange pattern, displacement and handle socket, and the reel drum's bore, are confirmed when parts are bought (CBK-DEC-001); the stand plate holes and lever hub follow the pump bought.

## Safety

> **Safety:** CampBreak includes a pressurised hand-pumped water line (relief valve at 4 bar, hose rated 10 bar) and a sealed lead-acid station battery. The kit is for small, early fires only; people leave first, and water is never used on burning oil or live wiring. Safety stops are listed in the build plan, section 6. It is an open engineering reference, not certified equipment.

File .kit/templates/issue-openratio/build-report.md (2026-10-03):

---
name: Build report
about: Tell us what happened when you built, printed or tested part of this design
title: "Build report: "
labels: build-report
---

This is a research and educational prototype, not a medical device. It is a TRL 3 concept and is not released for fabrication. If you build any part of it, you do so at your own risk. Reports help everyone.

**What you built** (part, sub-assembly or test)

**Materials, tools and settings**

**What worked**

**What did not work, with photos or measurements if you have them**

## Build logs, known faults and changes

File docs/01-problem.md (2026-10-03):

---
doc_id: CBK-PRB-001
title: CampBreak problem statement
project: CampBreak
doc_type: Problem statement
version: "0.4"
status: Draft
date: '2026-10-03'
author: Amish Chadha
license: CERN-OHL-S-2.0
revisions:
- version: "0.1"
  date: '2026-09-30'
  author: Amish Chadha
  change: Initial scaffold
- version: "0.2"
  date: '2026-10-03'
  author: Amish Chadha
  change: "Populated to TRL 2 with concept media, components and first-order numbers"
- version: "0.3"
  date: '2026-10-03'
  author: Amish Chadha
  change: "TRL 3 with the decisions of CBK-DDR-001 and CBK-DDR-002 applied and results from CBK-CAL-001"
- version: "0.4"
  date: '2026-10-03'
  author: Amish Chadha
  change: "Estimated cost updated after Amish's R9 decision (CBK-DDR-003)"
---

# CampBreak problem statement

In a dense camp, a shelter fire becomes a block fire within minutes. The people who are there in those minutes are residents, and they have almost nothing to fight it with.

## The problem

Camp shelters are built from bamboo, tarpaulin and thatch, packed closer than planning standards allow, and cooked in with open flames. Residents in the January 2024 Camp 5 fire described flames spreading with the wind through thatch roofs, while hilly ground slowed vehicles and hydrants ran dry ([The New Humanitarian, 2024](https://www.thenewhumanitarian.org/news-feature/2024/01/10/fire-bangladesh-rohingya-refugee-camp-where-is-support)). In informal settlements more widely, residents raise the alarm, evacuate, gather water and fight fires themselves, but with poor equipment and little training ([Engineering X](https://engineeringx.raeng.org.uk/media/03cd1j4l/engx-a-comparative-study-of-fire-risk-emergence-in-informal-settlements-in-dhaka-and-cape-town-short.pdf)).

Parts of the answer exist separately. Lumkani's networked heat detectors raise the alarm across neighbouring homes and have been installed in South Africa, Kenya and Bangladesh ([Wikipedia](https://en.wikipedia.org/wiki/Lumkani)), and a 2026 study found rate-of-rise heat detection better suited than smoke alarms to homes that cook with open flames ([Afrin and Rush, 2026](https://www.sciencedirect.com/science/article/pii/S0379711226002171)). Camp agencies have deployed three-wheeler mobile firefighting units ([The New Humanitarian, 2024](https://www.thenewhumanitarian.org/news-feature/2024/01/10/fire-bangladesh-rohingya-refugee-camp-where-is-support)). What is missing is an open kit that links the alarm to water at block level, is hand-powered, and can be built and repaired in the camp.

## Users and context

| User | Need | Context |
| --- | --- | --- |
| Camp residents and block fire volunteers | Hear the alarm fast and get water onto a burning shelter within minutes | Night and day, narrow paths, slopes, no power at the shelter |
| Camp management and site planning agencies | A low-cost, repairable block kit that fits existing fire safety plans | Planned and unplanned camps, dry-season water shortages |
| Local fire services | Fires held small until engines or mobile units arrive | Long travel times and poor vehicle access |
| Community groups in urban informal settlements | A shared station they can own, maintain and train on | Dense shack neighbourhoods with communal standpipes |

## Operating environment

- Outdoor block station and indoor shelter alarms; ambient 5 to 45 °C (41 to 113 °F), monsoon rain, dust and high humidity.
- Unpaved, sloping and muddy paths, often under 1.5 m (5 ft) wide, with steps and drains to cross.
- Water from 200 L drums, jerrycans, tube wells or taps; supply may be low in the dry season.
- Cooking smoke and open flames inside or beside shelters, which rule out smoke-based detection.
- No mains power at the shelter; alarms run on batteries or small solar cells.

## Constraints

- Value-engineering target of USD 1,600 for one block kit (24 alarms, one station and one hose cart), a hypothetical control target rather than a limit; off-the-shelf parts and workshop fabrication. Estimated cost of the constructable design: USD 1,374 (USD 226 under the target).
- Hand-powered pumping only; no fuel engine on the cart.
- Cart must be moved by two adults on the paths above.
- Alarm detection by rate of rise of temperature, not smoke, to avoid cooking false alarms.
- Open design: hardware under CERN-OHL-S-2.0, firmware under MIT.
- No claims of alarm or extinguisher certification; published as an engineering reference.

## Out of scope

- Fighting fully developed block fires; that remains the fire service's job.
- Arson prevention, security and policing in camps.
- Shelter materials, fire-retardant treatments and site layout.
- Certified smoke or heat alarms and certified extinguishers.
- Motorised pumps and hydrant networks.

## Prior work

| Prior work | What it does | Gap for these users | Source |
| --- | --- | --- | --- |
| Lumkani networked heat detector | Rate-of-rise heat detector that alarms all homes within about 60 m and sends SMS alerts through a gateway | Raises the alarm but gives residents nothing to fight the fire with; the mesh network is described as patented | [link](https://en.wikipedia.org/wiki/Lumkani) |
| Stirrup pump | Portable hand pump used with a bucket of water to control small fires, used widely in civil defence | Needs constant bucket refilling and a crew; no stored hose or station at block level | [link](https://en.wikipedia.org/wiki/Stirrup_pump) |
| Hand-pumped fire engines and hose carts (1700s to 1800s) | Manually pumped engines with hose, drawn by crews and fed by buckets or cisterns | Large crews and heavy apparatus; not sized for narrow camp paths or modern parts | [link](https://hallofflame.org/hand-and-horse-drawn-apparatus/) |
| Indian 5-gallon backpack firefighting pump | Backpack water tank with hand-operated pump used in wildland firefighting | Small water volume per trip and no alarm link | [link](https://www.forestry-suppliers.com/product_pages/products.php?mi=15791&itemnum=85700) |
| Camp mobile firefighting units (MFFU) | Three-wheeler firefighting vehicles deployed in the Cox's Bazar camps | Limited by terrain and vehicle access and by hydrant water in the dry season | [link](https://www.thenewhumanitarian.org/news-feature/2024/01/10/fire-bangladesh-rohingya-refugee-camp-where-is-support) |

## Co-design

A camp management or shelter agency with an existing community fire volunteer programme, ideally working with a local fire service, so that the kit is tested against real drills, real paths and the water sources residents actually have.

## Answers to the open questions

The scaffold's open questions were answered at TRL 2 and TRL 3 and decided under Amish's 2026-10-03 pre-approval (CBK-DDR-001):

- **Alarm relay scheme:** a published star scheme. Each alarm reports to the block station, which sounds its siren and broadcasts once so every alarm sounds. It is not a mesh, and it will be checked against Lumkani's patents before release (D1).
- **Kit size and coverage:** 24 alarms, one station and one cart per block; stations are sited so that no shelter is more than 70 m from one (D4, D9).
- **Flow and pressure:** about 20 L/min through a 6 mm jet reaching about 6.9 m, at about 1.2 bar at the pump, with a 4 bar relief valve (CBK-CAL-001, D7).
- **Theft and misuse:** the cart parks under the station roof in view of the block and the alarm box is a locked enclosure. Arson remains out of scope.
- **First drill:** the first candidate to approach is a camp management agency in the Cox's Bazar camps working with the Bangladesh Fire Service and Civil Defence; nothing is agreed yet (D10).

## Safety

> **Safety:** CampBreak is for small, early fires only. People leave first; nobody enters a burning shelter or stays when the fire spreads. Water is never used on burning cooking oil or live wiring. The pump and hose are pressurised (relief valve at 4 bar); the station holds a sealed lead-acid battery. The kit is an open engineering reference, not certified fire alarms or firefighting equipment.

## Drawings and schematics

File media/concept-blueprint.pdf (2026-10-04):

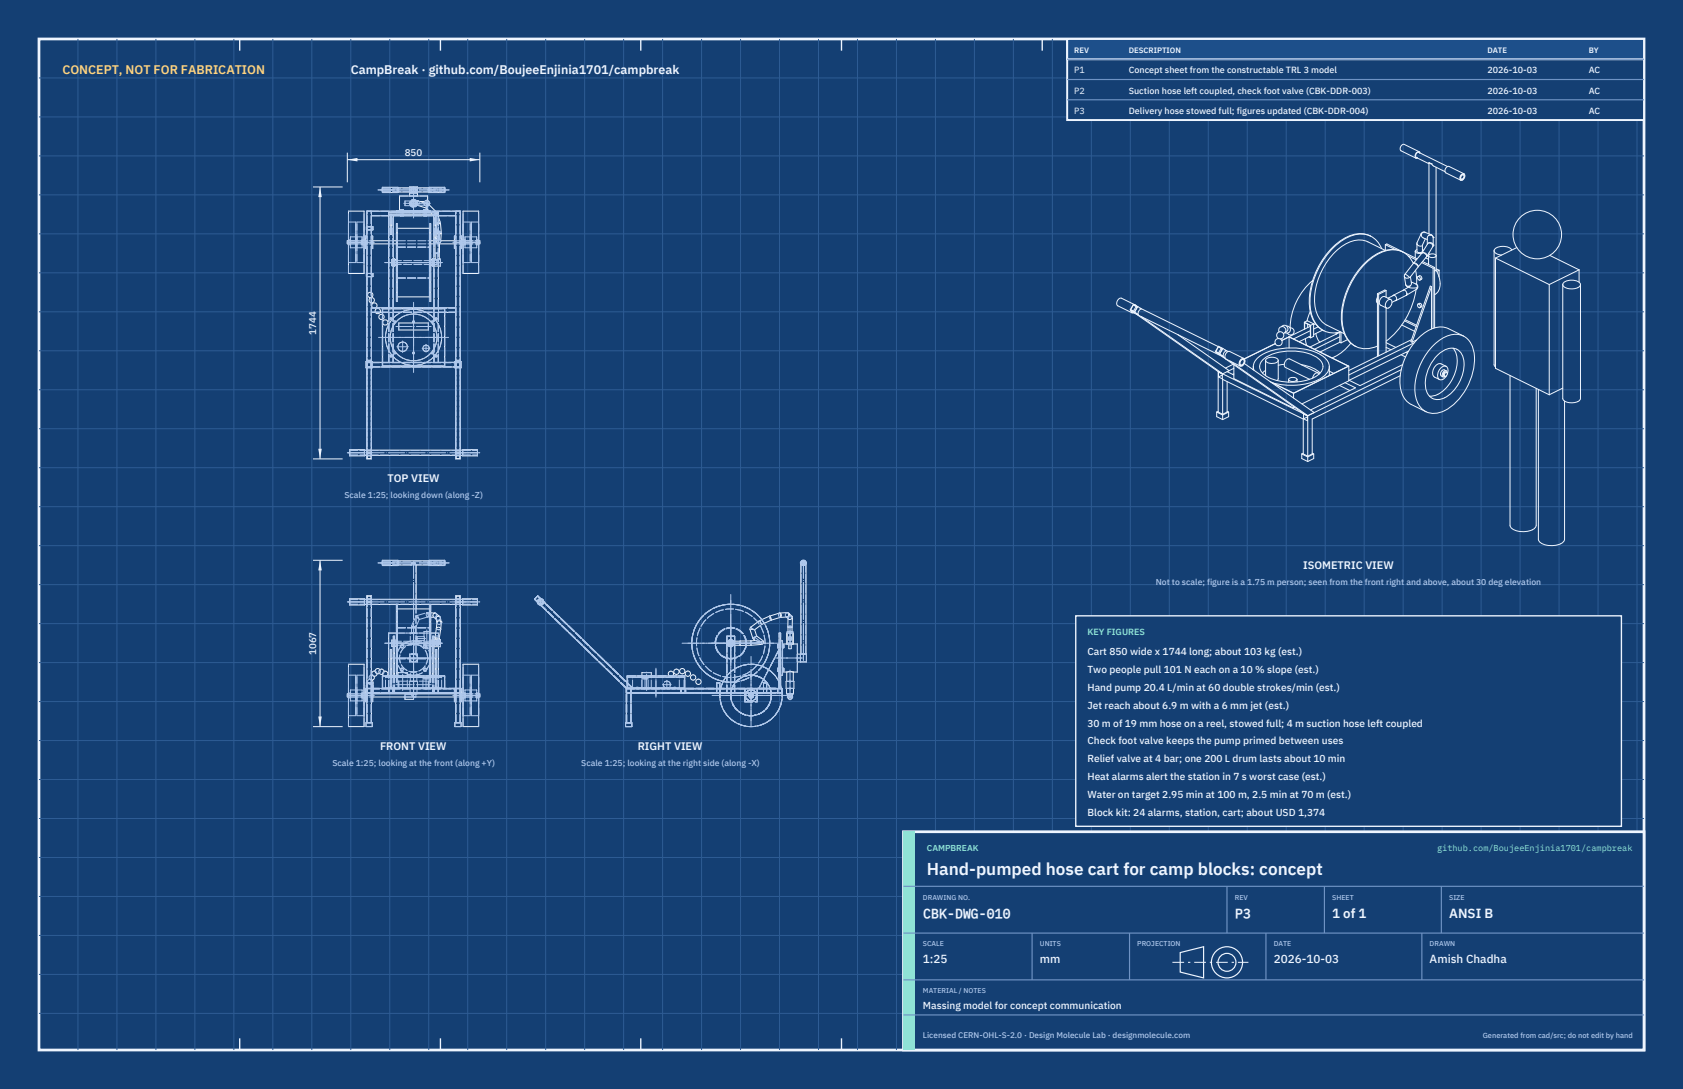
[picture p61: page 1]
CONCEPT, NOT FOR FABRICATION; CampBreak · github.com/BoujeeEnjinia1701/campbreak; FRONT VIEW; TOP VIEW; RIGHT VIEW; ISOMETRIC VIEW; REV; DESCRIPTION; DATE; Concept sheet from the constructable TRL 3 model; Suction hose left coupled, check foot valve (CBK-DDR-003); Delivery hose stowed full; figures updated (CBK-DDR-004); CAMPBREAK; github.com/BoujeeEnjinia1701/campbreak; DRAWING NO. CBK-DWG-010; REV P3; SHEET 1 of 1; SIZE ANSI B; SCALE 1:25; UNITS mm; PROJECTION; DRAWN Amish Chadha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

Scale 1:25; looking down (along -Z)

Not to scale; figure is a 1.75 m person; seen from the front right and above, about 30 deg elevation

KEY FIGURES
Cart 850 wide x 1744 long; about 103 kg (est.)
Two people pull 101 N each on a 10 % slope (est.)
Hand pump 20.4 L/min at 60 double strokes/min (est.)
Jet reach about 6.9 m with a 6 mm jet (est.)
30 m of 19 mm hose on a reel, stowed full; 4 m suction hose left coupled
Check foot valve keeps the pump primed between uses
Relief valve at 4 bar; one 200 L drum lasts about 10 min
Heat alarms alert the station in 7 s worst case (est.)
Water on target 2.95 min at 100 m, 2.5 min at 70 m (est.)
Block kit: 24 alarms, station, cart; about USD 1,374

Scale 1:25; looking at the front (along +Y)

Scale 1:25; looking at the right side (along -X)

Hand-pumped hose cart for camp blocks: concept

MATERIAL / NOTES
Massing model for concept communication

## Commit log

2026-10-03 CampBreak at TRL 3: constructable design (kit 1.7.0)
    Problem, concept and requirements; sizing calculations; CAD model, STEP and STL; general arrangement drawing; bill of materials; build plan with making sketches, joint close-ups and step pictures; design decisions register (all decided under Amish's 2026-10-03 pre-approval); TRL 2 and TRL 3 review; photoreal renders and storefront card. Private until Amish opens it.
    [bom.csv, campbreak-alarm.step, campbreak-alarm.stl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]
2026-10-03 Carry Amish's 2026-10-03 requirement decisions into the design
    Amish chose option A on each requirement decision ("1A 2A 3A 4A 5A 6A 7A 8A 9A 10A 11A"). CampBreak: primed foot valve, pre-coupled suction hose and a drilled 30 s gather (R9 now 3.2 min at 100 m, me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
    [bom.csv, campbreak-alarm.step, campbreak-assembly.step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]
2026-10-04 Carry Amish's round 2 requirement decisions into the design
    Amish approved all 47 recommendations on 2026-10-03 ("i approve all of the 47 recommendations provided by you. Execute them."). Each repo gains a decision record (DDR-003, or the next free number for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
    [results.csv]
2026-10-04 Carry Amish's round-2 and round-3 decisions into the design
    Amish approved all 46 round-2 recommendations ("i agree with all the 46 recommendations you provided. please proceed.") and all round-3 recommendations ("For round 3, I agree with all your proposed r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
    [bom.csv, results.csv]

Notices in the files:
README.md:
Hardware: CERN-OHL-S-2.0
